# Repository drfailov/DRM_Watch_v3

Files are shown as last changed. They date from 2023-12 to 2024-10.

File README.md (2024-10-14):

<!-- For new line: \ -->
<!-- Picture: <img src="Photos/" width="300"/>  -->
<!-- New Line: "  <br>"  -->

# Про проект DRM Watch 3

<p align="center">
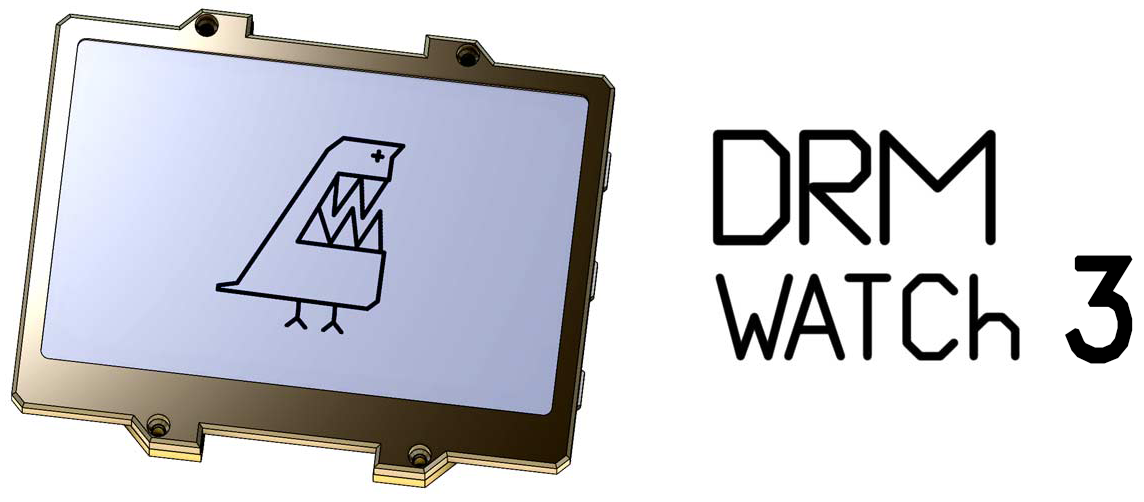
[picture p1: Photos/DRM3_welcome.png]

</p>

**DRM Watch 3** - це мій саморобний наручний годинник, в основі якого лежить дисплей Sharp Memory LCD, ESP32-S2 і бажання носити це на руці:)  <br>
Це **НЕ "Smart годинник"**! Цей пристрій по своїй функціональності близький до звичайного електронного годинника, з кількома додатковими можливостями, і їх можна додавати, перепрограмовувати годинник під себе.  <br>
Наразі в прошивці є всі можливості, що притаманні типовому годиннику і що дозволяє повноцінно використовувати його на щоденній основі.  <br>
В цьому репозиторії можна знайти інфу і інструкції **щоб зібрати собі такий годинник**.  <br>
  <br>
Це у мене таке хобі:) Я в кінці 2023 поліз вивчати проектування плат, після появи 3д принтера в 2022 поліз вивчати 3д моделювання, а за освітою програміст.  От власне це все і зібралось воєдино в цьому проекті) Робив це все з нуля. А яка б класна з цього була дипломна робота)))  <br>
  <br>
Посилання що наведено в цьому тексті є актуальними станом на **2024-04**. Якщо якісь товари будуть вже не актуальні, то шукайте за фотками))  <br>
  <br>
Стаття на Instructables:  <br>
https://www.instructables.com/DIY-ESP32-Wearable-DRM-Watch-3/    <br>
	  <br>

## Фото
<!--p align="center">
<img src="Photos/cad-angle.png" width="200"/>
<img src="Photos/cad-front.png" width="200"/>
<img src="Photos/cad-side.png" width="200"/>
</p-->

<p align="center">
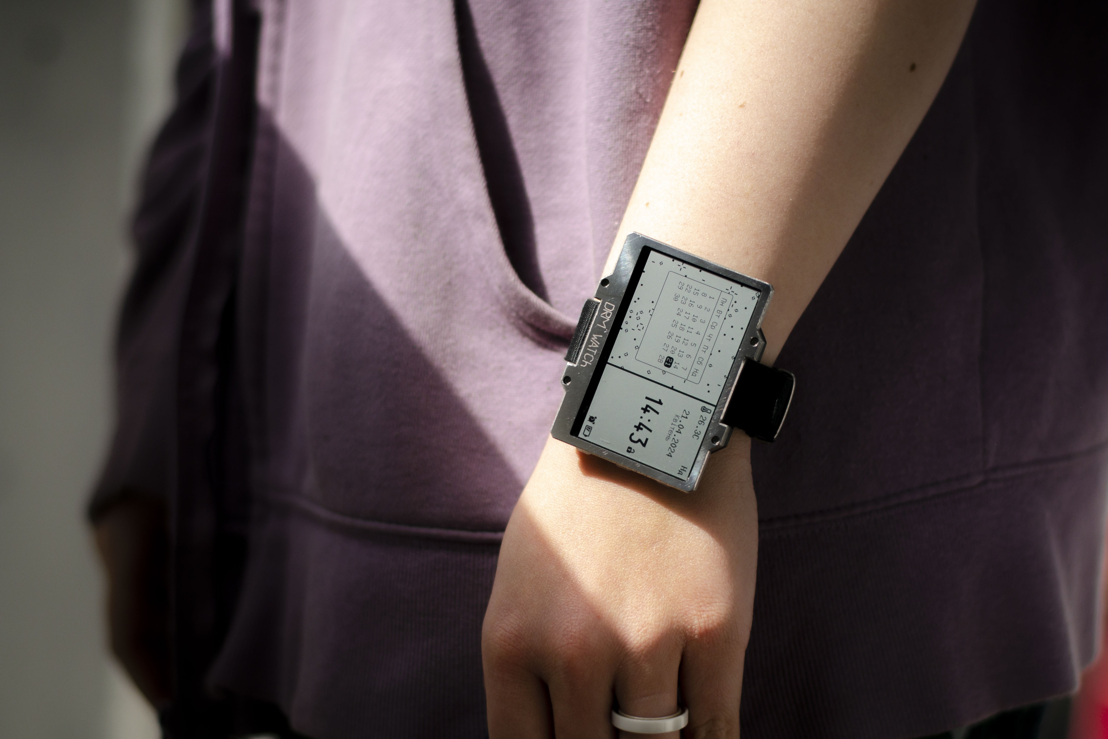
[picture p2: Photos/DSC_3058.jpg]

</p>
<p align="center">
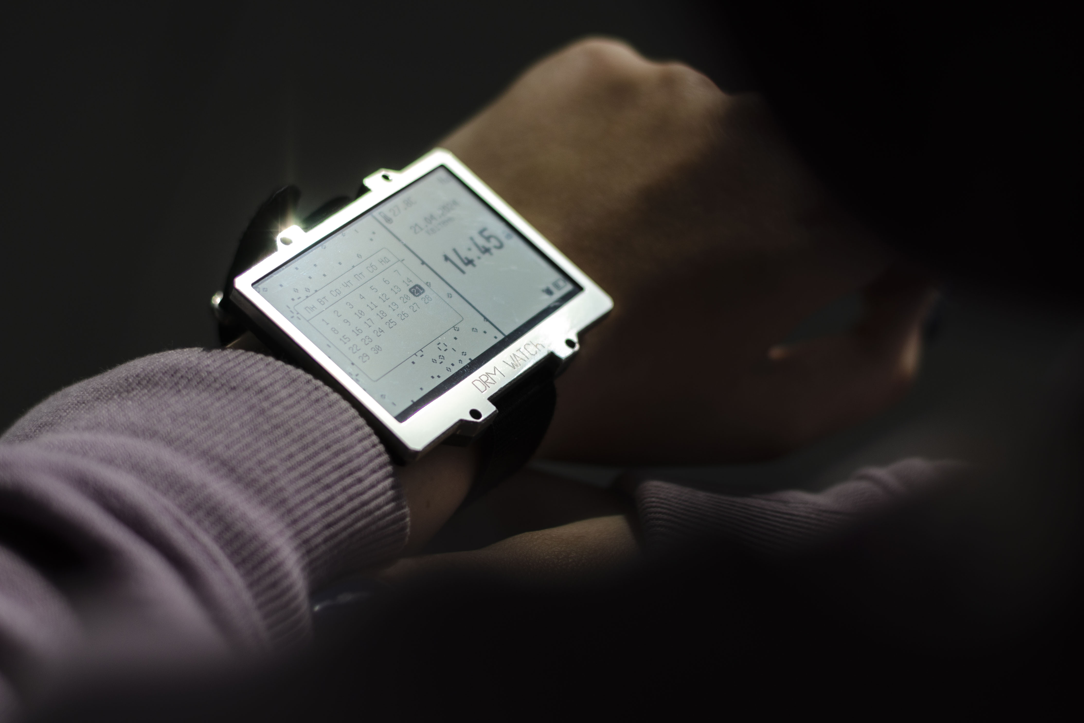
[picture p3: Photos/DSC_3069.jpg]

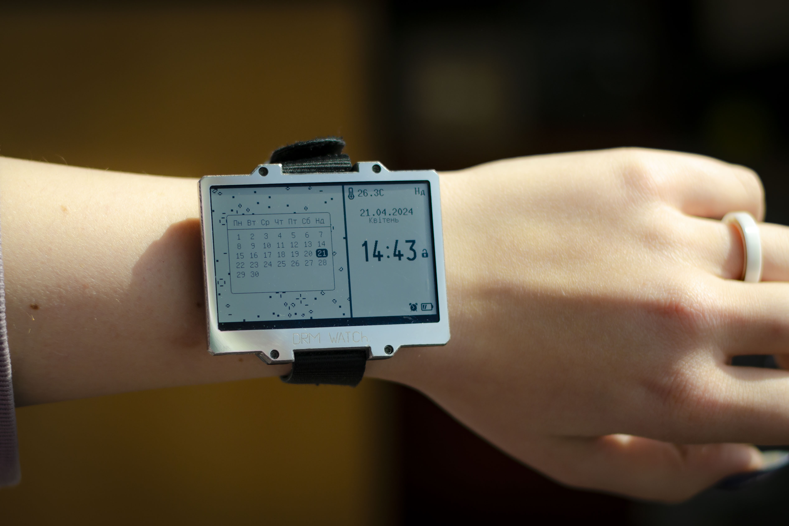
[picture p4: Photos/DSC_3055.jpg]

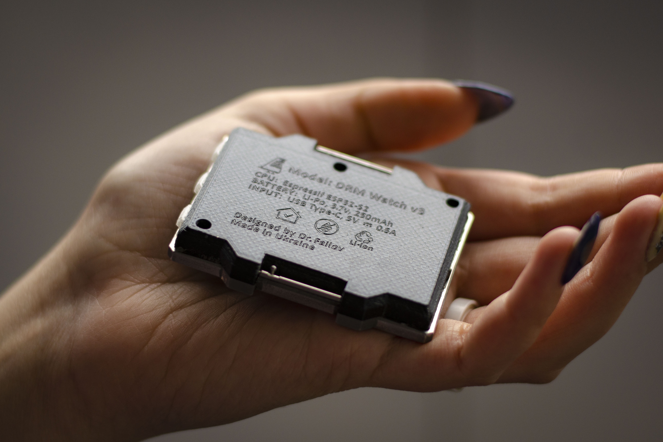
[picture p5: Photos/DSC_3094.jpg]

</p>
<p align="center">
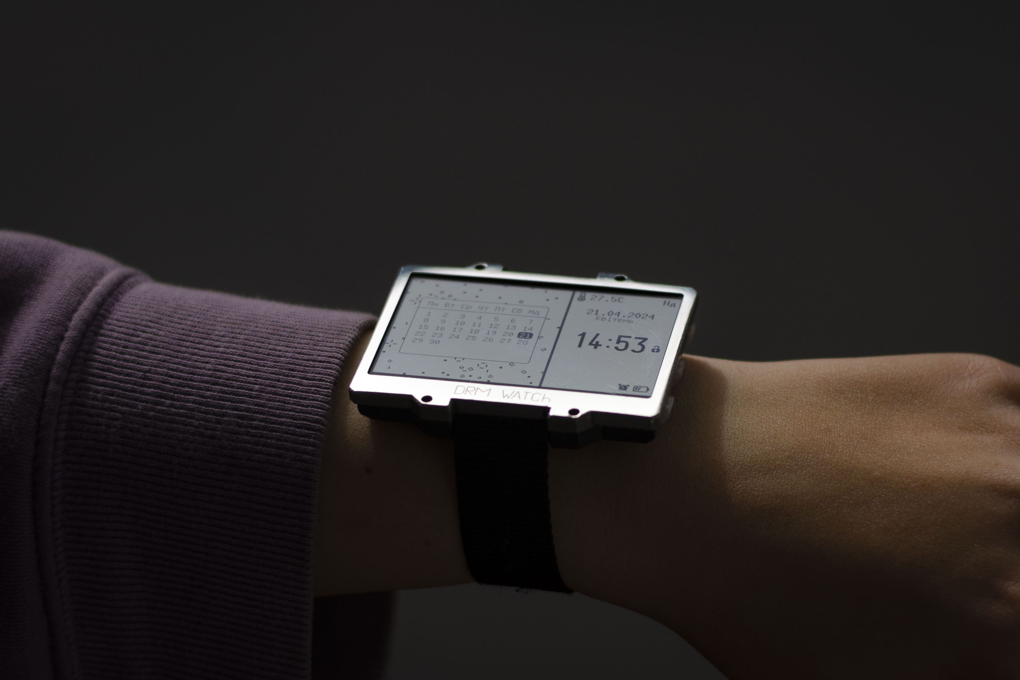
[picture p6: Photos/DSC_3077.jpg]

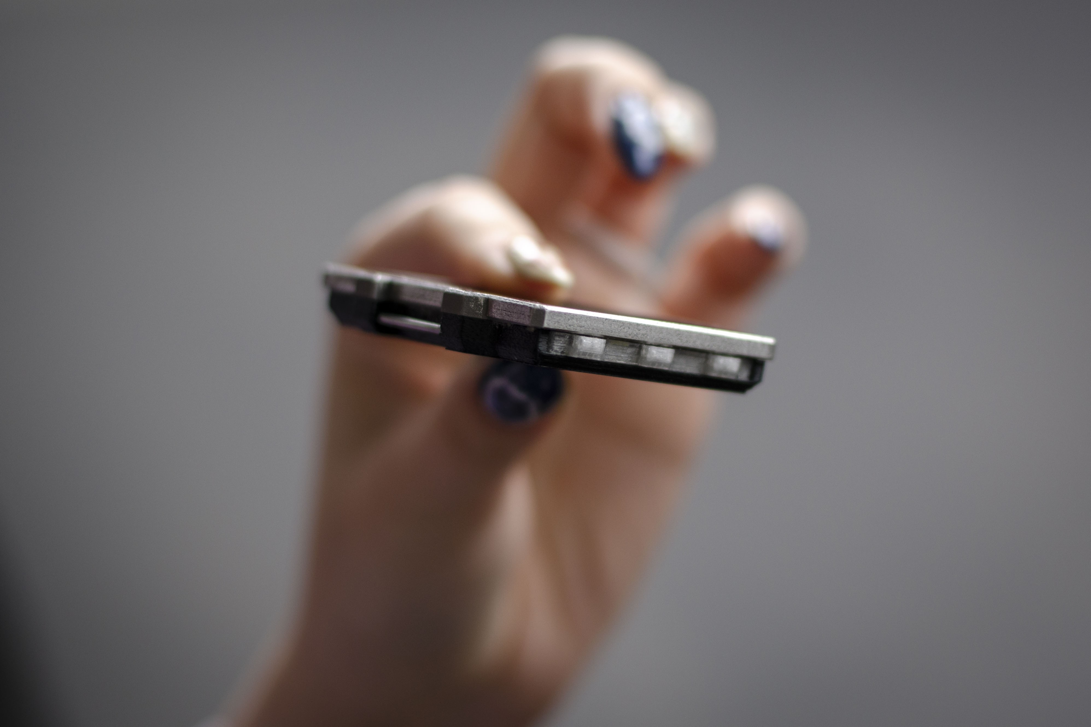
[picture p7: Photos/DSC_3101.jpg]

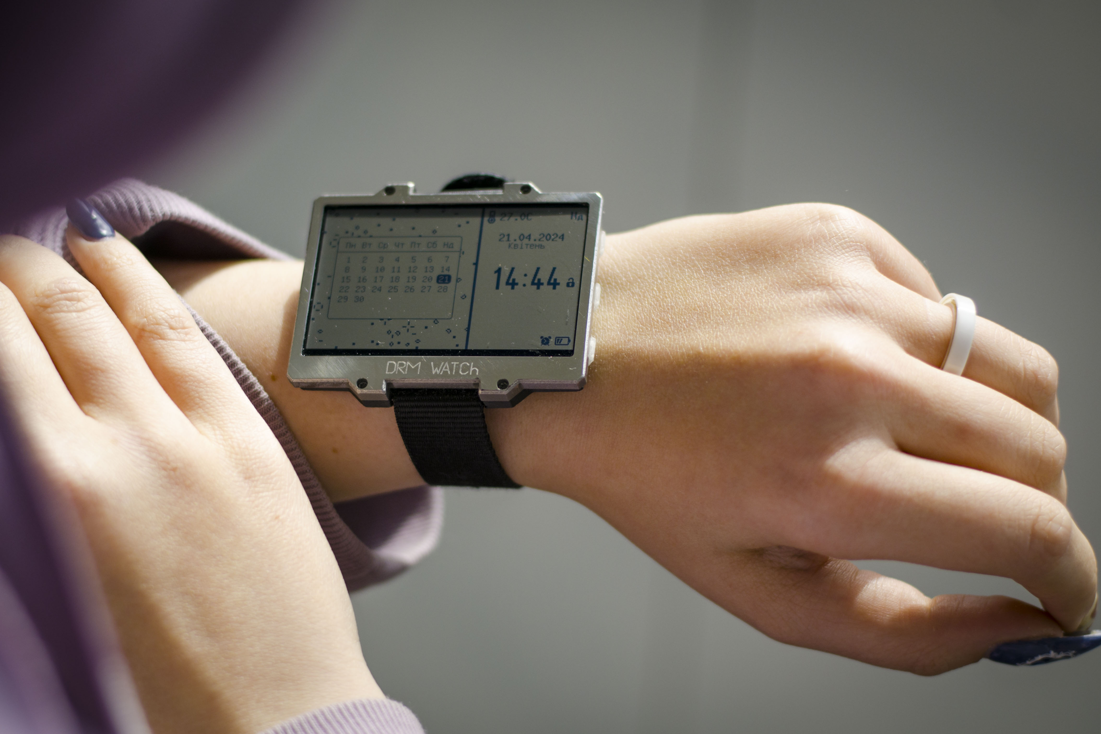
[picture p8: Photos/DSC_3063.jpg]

</p>
<!--p align="center">
<img src="Photos/DSC_3084.jpg" width="200"/>
<img src="Photos/DSC_3097.jpg" width="200"/>
<img src="Photos/DSC_3115.jpg" width="200"/>
</p-->

## Особливості годинника
- Зроблено в Україні;
- Стабільно працює і підходить для щоденного користування;
- Дисплей завжди показує час;
- Інтерфейс двома мовами: Українська та Англійська.
- В годиннику є вбудована "флешка" на 1.2МБ, в яку можна закинути файли
- Годинник може відкрити монохромний BMP, Wav файли, текстовий TXT документи
- Є дуже тускла але дуже приємна нічна підсвітка дисплея;
- Є ліхтарик, білий яскравий та червоний нічний;
- Акумулятора вистачає на понад 14днів, є індикатор заряду;
- Зручні меню, звідки можна отримати доступ до всіх функцій;
- Наявність Wi-Fi, можна зберегти до 8 мереж в пам'яті;
- Можливість синхронізації часу по Wi-Fi;
- Багато мелодій. Їх можна або просто слухати або встановити на будильник.
- Імітація звуку мявчання кошенят;
- Кілька циферблатів, які можна налаштувати;
- На циферблати можна додати календар, стрілочний годинник, дату, та цікавий фон
- Секундомір, працює в фоні;
- Будильники, до 6шт з назвами;
- Вічний календар (або я ще не догортав до кінця);
- Повнекранні клітинні автомати та анімації (Життя, Мураха, Вогонь, Шум, Лава, Мураха, Точки)
- Зарядка по USB, в тому числі від TypeC-TypeC;
- Можна оновлювати прошивку по USB, не розбираючи годинник.
- Компоненти для збірки легко дістати;
- Корпус підходить для стандартних 22мм ремінців;
- Зручно і просто прошивати. Можна написати свою прошивку.
- Якщо під час експериментів з прошивками годинник завис, в корпусі передбачено отвір щоб голкою його перезавантажити.
- Водонепроникність до 0 метрів:) (можна трохи покращити якщо при збірці обробити плату лаком а корпус збирати з клеєм.)
- Годинник можна використовувати як поле для експериментів з ESP32-S2: акумулятор, 3 кнопки, пищалка, дисплей, 3 світлодіоди;
- UART лог: інструмент для розробників, виводить на екран всі байти що надходять по UART.
- Екран "Про годинник" містить інформацію про розробника та версію прошивки.

## Застереження під час користування:
<p align="center">
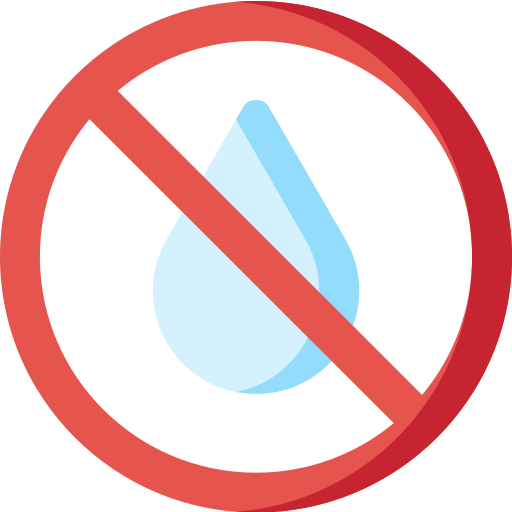
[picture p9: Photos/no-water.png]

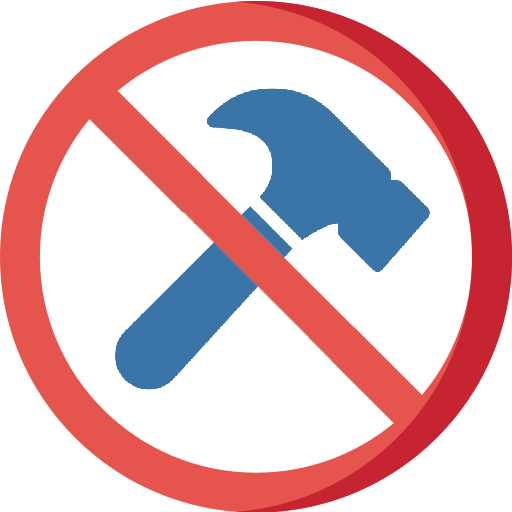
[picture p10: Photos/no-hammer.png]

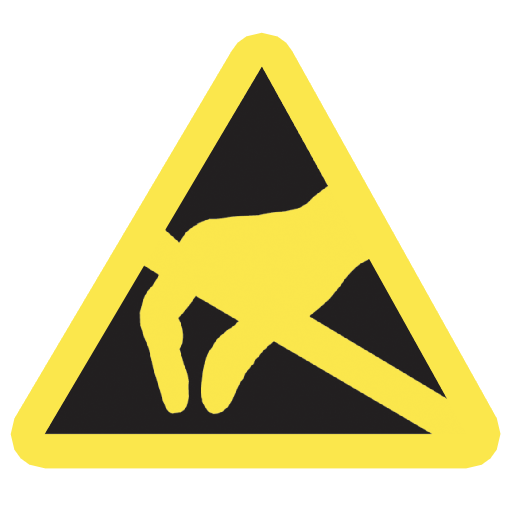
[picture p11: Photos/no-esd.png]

</p>

- Годинник **не можна мочити**. Захист від води тут майже відсутній і це призведе до поломки годинника. Від дрібного дощу або поту йому нічого не буде, а от залити при митті рук - може бути проблемою.
- Годинник **слабко захищений від ударів**. Дисплей не захищений, тонкі рамки, тонкий корпус, годинник спроектований без великого запасу механічної міцності, так він  ще й досить габаритний. Тому вдарити його легко, і це скоріше за все призведе до розбитого дисплея. Протягом моїх місяців експлуатації проблем з пошкодженням годинника не було, але я користувався досить обережно.
- Годинник варто **оберігати від впливу статики**. Є невеликий шанс вбити годинник якщо швидко змімати з себе светр) Тому або знімайте светр повільно, або зніміть перед цим годинник, або використовуйте светр який не електризується. Особливо ризикований момент - постановка на зарядку, тут може проскочити прямо через контроллер. Раджу перед тим як вставити кабель зарядки, доторкнутись до металевої частини корпусу зарядного пристрою - так ви розрядитесь через корпус, а не через годинник і все буде ок.

## Відео огляди годинника:
Тут я зібрав наявні відео годинника.

### Короткий огляд станом на FW v2.03
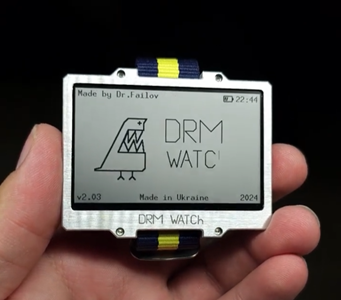
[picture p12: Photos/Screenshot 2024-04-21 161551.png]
Video review (https://www.youtube.com/watch?v=3oIwZVaCEvY)
  <br>
https://www.youtube.com/watch?v=3oIwZVaCEvY

### Повний огляд годинника станом на FW v3.22
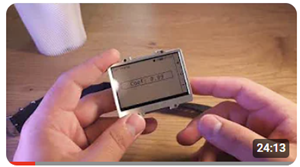
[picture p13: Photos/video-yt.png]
Video review (https://youtu.be/EeJpstsf5wk?si=9BsKVnumjvJCgt0X)
  <br>
https://youtu.be/EeJpstsf5wk?si=9BsKVnumjvJCgt0X

## Короткий відео огляд мелодій станом на FW v2.03
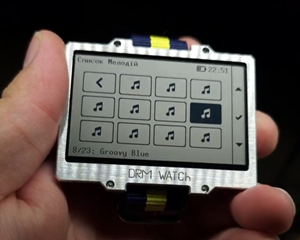
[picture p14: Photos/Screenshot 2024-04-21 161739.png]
Video review (https://www.youtube.com/watch?v=Ylm3CU0DTDE)
  <br>
https://www.youtube.com/watch?v=Ylm3CU0DTDE

### Мій акаунт тікток, де відео багато
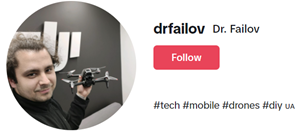
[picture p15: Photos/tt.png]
TT (https://www.tiktok.com/@drfailov)
  <br>
https://www.tiktok.com/@drfailov

# Опис меню, функцій та екранів

## Основний екран, циферблат
<p align="center"> 
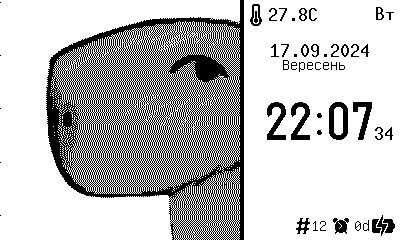
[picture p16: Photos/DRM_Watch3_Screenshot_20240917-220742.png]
       
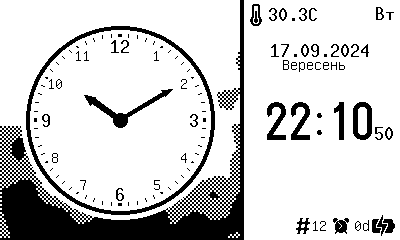
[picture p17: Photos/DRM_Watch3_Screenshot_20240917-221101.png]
       
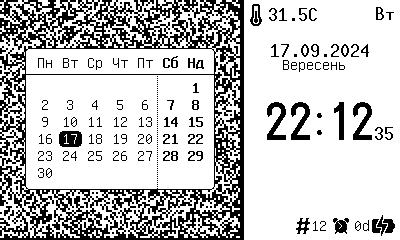
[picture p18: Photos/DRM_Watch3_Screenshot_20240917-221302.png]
       
<img src="Photos/DRM_Watch3_Screenshot_20240917-221522.png" height=200"/>       
<!--img src="Photos/photo_2_2024-06-02_22-49-14.jpg" height=200"/> 
<img src="Photos/photo_51_2024-06-02_22-49-14.jpg" height=200"/> 
<img src="Photos/photo_52_2024-06-02_22-49-14.jpg" height=200"/> 
<img src="Photos/photo_50_2024-06-02_22-49-14.jpg" height=200"/> 
<img src="Photos/photo_46_2024-06-02_22-49-14.jpg" height=200"/> 
<img src="Photos/photo_44_2024-06-02_22-49-14.jpg" height=200"/> 
<img src="Photos/photo_22_2024-06-02_22-49-14.jpg" height=200"/> 
<img src="Photos/photo_17_2024-06-02_22-49-14.jpg" height=200"/-->
</p>

Тут відображаєтья час. Це основний екран годинника, на нього переходят більшість екранів по таймеру бездіяльності. На цьому екрані годинник заходить в сон і спить, просинаючись раз в хвилину щоб намалювати час.     <br>
Вміст циферблату можна налаштувати під себе, тому тут так багато різних його фоток        <br>
**Кнопка вгору** (коротке натиснення) - Відкрити секундомір.      <br>
**Кнопка вгору** (довге натиснення) - Відкрити таймер.      <br>
**Середня кнопка** (коротке натиснення) - Увімкнути ліхтарик.      <br>
**Середня кнопка** (довге натиснення) - вимкнути годинник.      <br>
**Кнопка вниз** - відкрити меню програм.      <br>

## Програми

<p align="center"> 
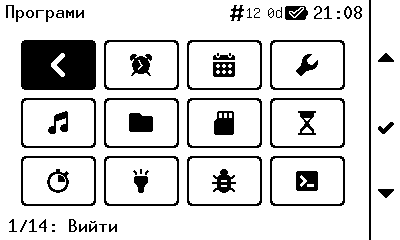
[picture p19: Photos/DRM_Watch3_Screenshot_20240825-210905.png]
 
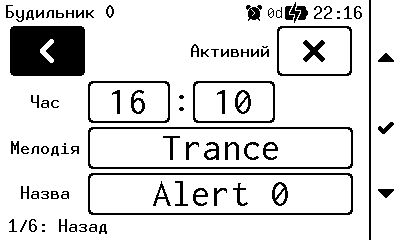
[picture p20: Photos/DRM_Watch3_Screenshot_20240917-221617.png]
 
</p>

Будильник запускає відтворення заданої мелодії в заданий час дня.     <br>
З цього екрану годинник автоматично перейде на основний екран через кілька хвилин бездіяльності.    <br>
Можна налаштувати кілька будильників. До кожного можна задати час, назву та мелодію. Будильник спрацює якщо годинник заряджений і якщо годинник звісно знає поточний час. Спрацює також якщо в момент спрацювання ви знаходитесь в меню а не на циферблаті, а також спрацює якщо годинник вимкнено (але він при цьому заряджений).     <br>
**Кнопками вгору та вниз** - обрати пункт меню.      <br>
**Центральна кнопка** активує обраний пункт меню.      <br>
Коли пункт меню активований, **кнопки вниз та вгору міняють значення пункту**.     <br>
Під час будильника гратиме обрана мелодія і відображатиметься назва будильника та час на який будильник було встановлено. Під час спрацювання будильника його можна закрити (вимкнути на поточний раз), або вікласти на 10 або 5 хвилин (за умови якщо в цей момент не запущено таймер). Після спрацювання будильника він спрацює знову наступного дня. 

## Програми -> Календар

<p align="center"> 
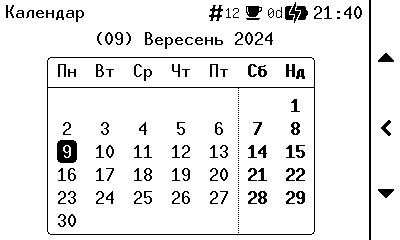
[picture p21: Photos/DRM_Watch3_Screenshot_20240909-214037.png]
 
</p>

## Налаштування -> Дисплей
<p align="center"> 
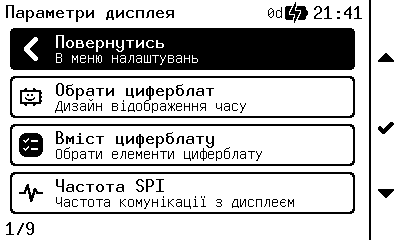
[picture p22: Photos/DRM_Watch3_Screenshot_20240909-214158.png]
 
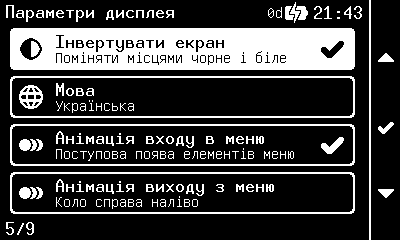
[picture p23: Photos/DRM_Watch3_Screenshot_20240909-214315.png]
 
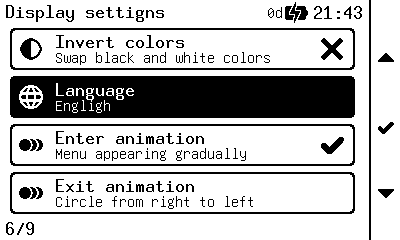
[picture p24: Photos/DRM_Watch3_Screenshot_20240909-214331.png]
 
</p>

Кожен годинник - унікальний, тому кожен показує заряд по своєму.      <br>
Щоб компенсувати цю неточність, я додав алгоритм який це виправляє, але для цього йому потрібно знати свою криву розряду. Щоб провести калібрування:      <br>
- повністю зарядити годинник 
- зняти з зарядки і пройти в налаштування -> дисплей ->калібрування акумулятора
- натиснути там початок калібровки.
- лишити годинник увімкненим на кілька годин поки він не вимкнеться.
Коли годинник вимкнеться, його можна поставити на зарядку і після цього він буде готовий до роботи з новою калібровкою     

## Програми -> Файли
<p align="center"> 
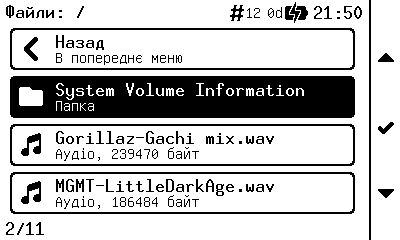
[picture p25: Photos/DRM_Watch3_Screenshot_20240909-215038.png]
 
</p>

Важливо!!! Не зберігайте на годиннику цінну інформацію яка не має копії! У мене кілька разів "ламалась" файлова система і файли втрачались. 
Закономірностей цього явища поки не виявив, але я б не довіряв годиннику нічого цінного!

Формати файлів які може відкрити годинник:
- BMP монохромний. Такі файли можна сформувати з допомогою Microsoft Paint.
- DWM мелодії. Такі файли можна сформувати з допомогою програми в папці `Software\MIDI-to-Arduino-main`.
- WAV PCM 8bit аудіо. Такі файли можна сформувати з допомогою Audacity.
- TXT текстові файли в UTF8 кодуванні. Такі файли можна сформувати з допомогою Notepad++.
<p align="center"> 
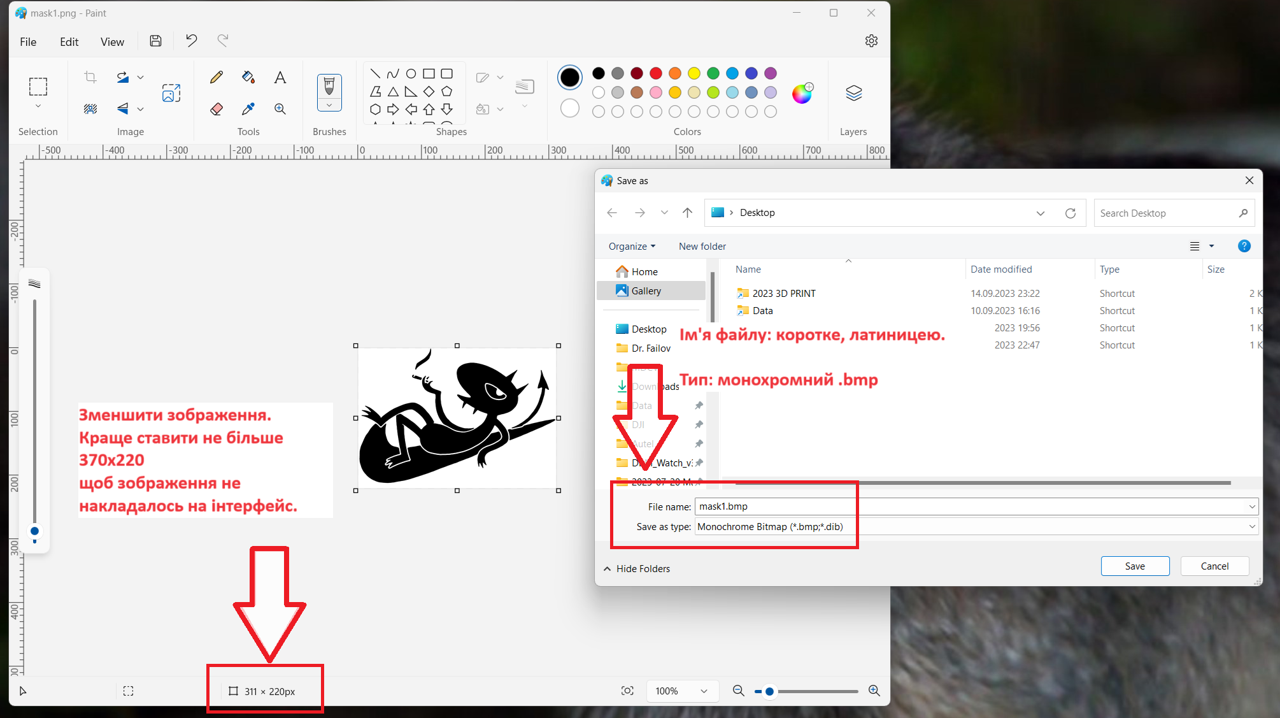
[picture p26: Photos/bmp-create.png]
 
</p>

## Програми -> Менеджер пам'яті
<p align="center"> 
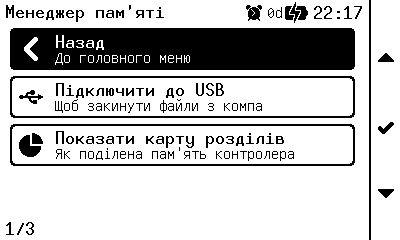
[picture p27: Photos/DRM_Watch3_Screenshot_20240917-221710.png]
 
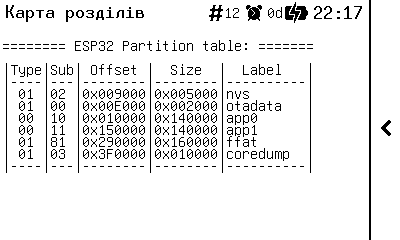
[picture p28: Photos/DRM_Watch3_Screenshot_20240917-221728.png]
 
</p>

Меню зі списком мелодій. Можна переглянути назви та увімкнути мелодію. Їх там багато.     <br>
Я постійно додаю нові мелодії, зокрема з мемів. Додати свої мелодії також можливо, дивіться розділ як зібрати прошивку а потім як додати мелодію.     <br>
З цього екрану годинник автоматично перейде на основний екран через кілька хвилин бездіяльності.    <br>
**Кнопками вгору та вниз** - обрати мелодію.     <br>
**Центральна кнопка** - відкрити і відтворити мелодію.   <br>

## Програми -> Мелодії -> Плеєр
<p align="center"> 
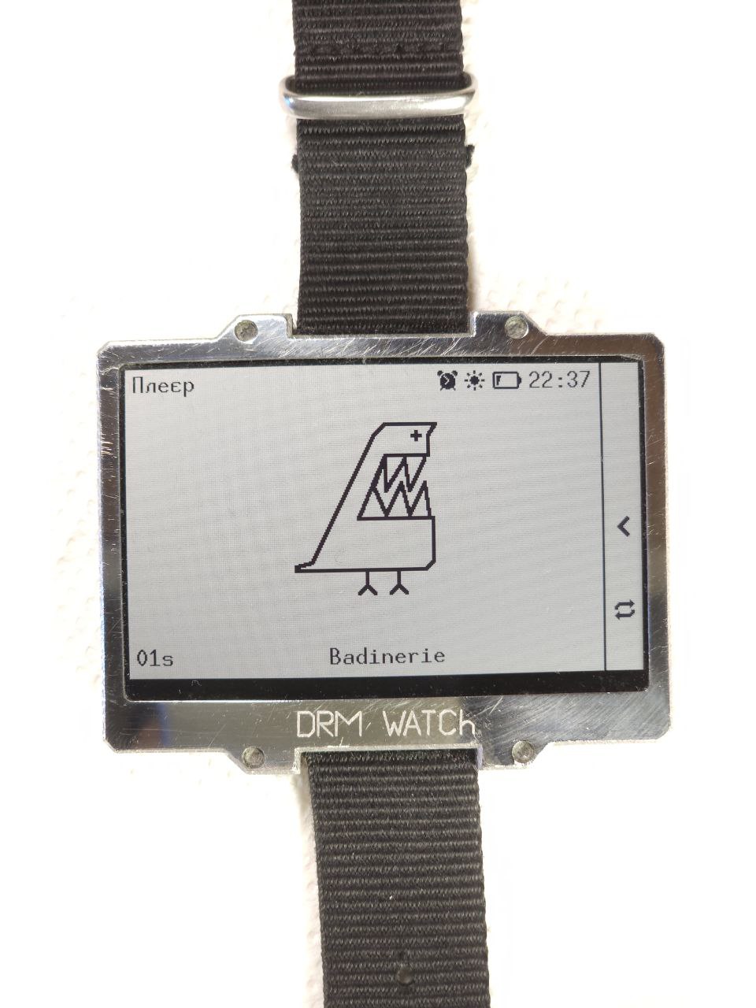
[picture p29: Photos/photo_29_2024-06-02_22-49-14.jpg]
 
</p>

Таймер веде відлік заданого часу від моменту запуску. Коли час спливає, запускається звуковий сигнал.      <br>
З цього екрану годинник автоматично перейде на основний екран через кілька хвилин бездіяльності.    <br>  
**Кнопками вгору та вниз** - задається час на який встановлюється таймер.    <br> 
**Центральна кнопка** - або закриває програму, або запускає таймер.     <br> 
Коли лунає звуковий сигнал, його можна закрити, або вікласти на 10 або 5 хвилин.

## Програми -> Секундомір
<p align="center"> 
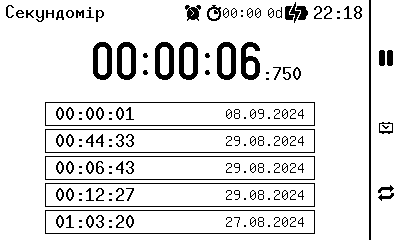
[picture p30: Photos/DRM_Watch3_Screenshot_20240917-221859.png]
 
</p>

Запускає ліхтарик. Програма при цьому ніяка не відкривається, просто вмикається світло.      <br> 
У ліхтарика два режими роботи - червоним світлодіодом і білим.       <br> 
Червоний буде корисним вночі - так він не сліпить і після його використання буде все ще добре видно вночі. 
Денний ліхтарик більш яскравий.      <br> 
Ліхтарик автоматично вимкнеться через кілька хвилин бездіяльності.  <br> 
**Один раз натиснути на кнопку** - якщо ліхтарик вимкнено - увімкнути нічний ліхтарик.      <br> 
**Другий раз натиснути** - увімкнути денний режим.      <br> 
**Якщо ліхтарик вже світить** - більше 5 секунд, то натиснення на кнопку його вимкне.      <br> 
Тобто якщо вночі запустити нічний ліхтарик, покористуватись ним, то натиснення на іконку ліхтарика не запустить денний ліхтар а вимкне ліхтар.      <br> 
Щоб запустити денний ліхтар - кнопку треба натиснути двічі протягом 2 секунд.      <br> 

## Програми -> Інженерне меню
<p align="center"> 
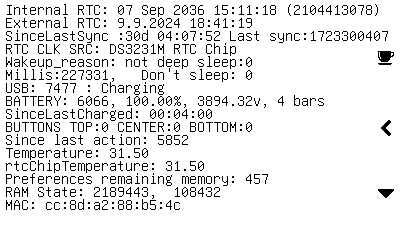
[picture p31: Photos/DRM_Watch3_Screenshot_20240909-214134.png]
 
</p>

На цьому екрані зібрано максимум технічної інформації яка допоможе зрозуміти стан системи.      <br> 
На цьому екрані годинник спить, і не виходить на циферблат.      <br> 
**Центральна кнопка** - вийти до меню програм.      <br> 
**Кнопка вгору** - активувати чи вимкнути режим безсоння     <br>
В режимі безсоння годинник не буде йти в сон по таймеру. 
В цьому режимі годинник дуже швидко розрядиться, за кілька годин. 
В режимі безсоння в статусбарі буде відображатись інонка з кавою, а в інженерному меню буде написано "Don't sleep: 1".     <br>

## Програми -> Лог UART
<p align="center"> 
<img src="Photos/DRM_Watch3_Screenshot_20240909-220405.png" height=200"/> 
</p>

Годинник при підключенні до компа імітує на компі **COM порт**. 
Всі дані що надходять на COM порт - виводяться в лог на екрані.   <br>
Це може бути корисно якщо потрібно зрозуміти яку команду надсилає 
невідома вам програма до підключеного пристрою в процесі, наприклад, діагостики або реверс інжинірінгу.   <br>
Відображення відбувається в форматі лога, можна виводити як в текстовому форматі (ASCII) так і в форматі шістнадцяткових байтів (HEX).  <br>
На цьому екрані годинник не спить і не виходить на циферблат автоматично! Він буде увімкнений доти, доки його не вимкнути вручну або він не розрядиться повністю.  <br>
**Кнопка вгору** - ставить зображення на паузу - якщо потрібно детальніше вивчити отримані дані. Нові дані не будуть виводитись на екран.  <br>
**Центральна кнопка** - вийти до меню програм.  <br>
**Кнопка вниз** - перемкнути режим відображення (ASCII чи HEX).  <br>

## Програми -> Meow
<p align="center"> 
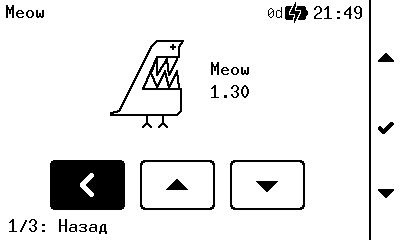
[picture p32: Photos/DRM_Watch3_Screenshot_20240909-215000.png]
 
</p>

Режим повноекранного кліткового автомату "Життя" (Convey's Game Of Life).    <br>
**Будь-яка з кнопок** - повернутись до меню програм.    <br>

## Програми -> Вогонь
<p align="center"> 
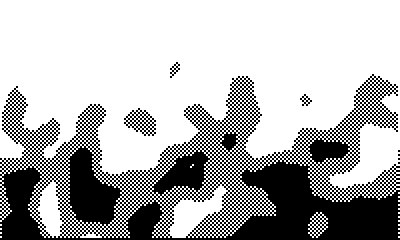
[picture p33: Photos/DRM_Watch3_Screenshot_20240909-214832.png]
 
</p>

Режим повноекранної анімації лави. Красиво. В основі лежить шум Перліна.    <br>
**Будь-яка з кнопок** - повернутись до меню програм.    <br>
Дякую за допомогу з реалізацією Кирилу Лейферу, ось його репозиторій: https://github.com/BOOtak/dct3ngine/blob/master/src/games/perlin_test

## Програми -> Мураха
<p align="center"> 
<img src="Photos/photo_43_2024-06-02_22-49-14.jpg" height=300"/> 
</p>

Режим повноекранного кліткового автомату "Мураха Ленгтона".    <br>
**Кнопки вниз або вгору** - змінити швидкість симуляції.    <br>
**Середня кнопка** - повернутись до меню заставок.    <br>

## Налаштування -> Вміст циферблату
Одночасно відображатиметься тільки один фон, тому щоб був відображався потрібний фон, потрібно залишити активний тільки один з доступних.    <br>
Кнопками вгору та вниз - обрати пункт меню. Центральна кнопка міняє обраний пункт меню. 

# Як зібрати годинник
Готових годинників в продажу не існує, тому якщо є бажання отримати такий годинник, можна зібрати самому.  <br>  

## Що знадобиться
<p align="center">
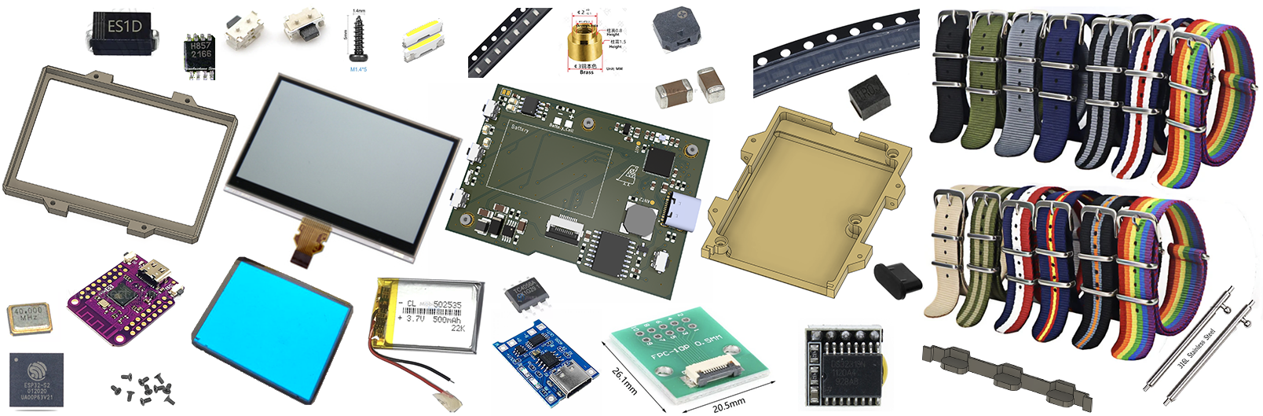
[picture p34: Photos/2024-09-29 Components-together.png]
 
</p>

- Паяльник
- Припой
- Паяльний фен або столик
- Флюс
- Пінцети
- Викрутки
- Мікроскоп (бажано)

## Де брати комплектуючі
<p align="center">
 
</p>

Якщо коротко, то:  <br>  
- Board: Order PCB on jlcpcb, GERBER included  <br>  
- Front panel: order alluminium CNC Milling on jlcpcb, STEP included  <br>  
- Back panel: 3d print, STL included  <br>  
- Display Sharp LS027B7DH01A  <br>  
https://www.aliexpress.us/item/1005005611440829.html  <br>  
- Connector FPC 10pin 0.5mm pitch  <br>  
https://www.aliexpress.us/item/10000348360254.html  <br>  
- Battery lipo 502535  <br>  
https://ampul.eu/de/batterie/4242-li-pol-akku-450mah-37v-502535  <br>  
- Buzzer SMD 7525-3.6V-passive  <br>  
https://www.aliexpress.us/item/1005003620083880.html  <br>  
- Mosfet 2N7002LT1G  <br>  
https://www.aliexpress.us/item/1005003079655220.html  <br>  
- Esp32 board: Lolin S2 Mini  <br>  
https://www.aliexpress.us/item/1005004438665554.html  <br>  
- TP4056 Charging module  <br>  
https://www.aliexpress.com/item/1005006310424899.html  <br>  
- Resistor set SMD 0603  <br>  
https://www.aliexpress.us/item/1005002364437129.html  <br>  
- Capacitors set SMD 0603  <br>  
https://www.aliexpress.us/item/1005006124283234.html  <br>  
- RTC Module based on Analog Devices DS3231   <br>  
https://www.aliexpress.us/item/32822420722.html  <br>  
- 020 SMD Side View LED White 6000K  <br>  
https://www.aliexpress.us/item/32419907074.html  <br>  
- Buttons 2\*4\*3.5mm Micro SMD Tact Switch Side Button  <br>  
https://www.aliexpress.us/item/1005004312046546.html  <br>  
- Screw places SMTSO Surface Mount Copper Nut M1.4X3X1.5-2X0.8  <br>  
https://www.aliexpress.com/item/1005005579653583.html  <br>  
- Screws PH000, M1.4, 3mm length  <br>  
https://www.aliexpress.com/item/1005002364568213.html  <br>  
- Self tapping screws M1.5, 6mm  <br>  
https://www.aliexpress.com/item/1005002324715062.html  <br>  
- Watch band, 22мм   <br>  
https://www.aliexpress.us/item/1005005890436737.html  <br>  
- USB Type C cover:  <br>  
https://www.aliexpress.com/item/4000148621089.html  <br>  
- EL Panel driver: Microchip HV857MG MSOP8  (optional, only if you want backlight)  <br>  
https://www.aliexpress.us/item/1005005512523052.html  <br>  
- EL Driver Capacitor SMD 1206 10NF X7R 200V (optional, only if you want backlight)  <br>  
https://www.aliexpress.us/item/1005004628006766.html  <br>  
- EL Driver Capacitors SMD 1206 320PCS 16Value   (optional, only if you want backlight)  <br>  
https://www.aliexpress.us/item/1005006124283234.html   <br>  
- EL Driver Diode ES1D   (optional, only if you want backlight)  <br>  
https://www.aliexpress.us/item/1005005254835443.html  <br>  
- EL Driver  SMD Inductor 1210 3225 22UH   (optional, only if you want backlight)  <br>  
https://www.aliexpress.us/item/32981310345.html  <br>  
- Glue to connect EL panel MECHANIC MCN-DJ002 Conductive Adhesive Glue Silver (optional, only if you want backlight)  <br>  
https://www.aliexpress.us/item/1005002369819447.html  <br>  

### Дисплей
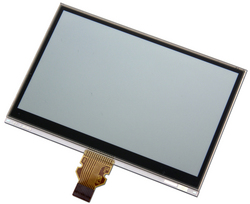
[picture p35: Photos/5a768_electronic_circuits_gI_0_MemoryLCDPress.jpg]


Дисплей потрібен, щоб відображати інформацію користувачу:)  <br>
Модель дисплея: **Sharp LS027B7DH01A**    <br>
Він звісно недешений, але мені дуже подобається як він виглядає. Його можна купити готовим, я купував тут:   <br>
https://www.aliexpress.us/item/1005005611440829.html  <br>

### Конектор дисплея
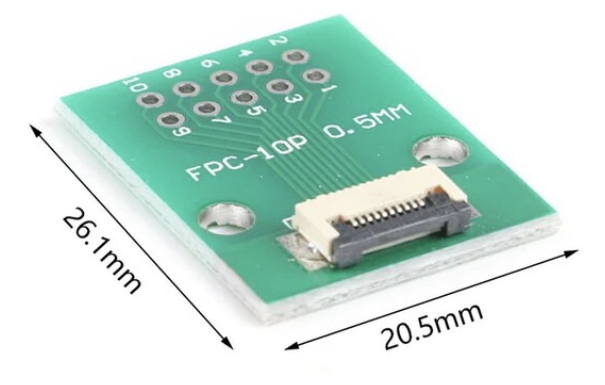
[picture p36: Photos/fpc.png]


Для підключення цього дисплея. Я купував модулем, але можна пошукати і роз'єм окремо.  <br>
Модель: **FPC 10pin 0.5mm pitch** Я купував тут:    <br>
https://www.aliexpress.us/item/1005002288363000.html   <br>
https://www.aliexpress.us/item/10000348360254.html   <br>

### Акумулятор
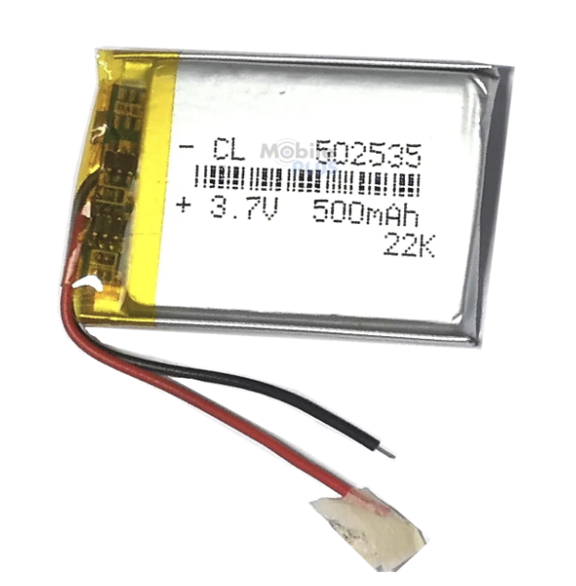
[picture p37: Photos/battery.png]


Якщо потрібно щоб пристрій працював автономно, то потрібен акумулятор.  <br>
Корпус та плата спроектовано під літій-іонний акумулятор такої форми: 35*25*5mm. Звісно, підійде будь-який і меншого розміру, але матиме меншу ємність.  <br>
Модель яка найкраще підходить: **lipo 502535**. Я купував тут:    <br>
https://prom.ua/ua/p1286391849-akkumulyator-kontrollerom-universalnyj.html   <br>
https://ampul.eu/de/batterie/4242-li-pol-akku-450mah-37v-502535   <br>

### Буззер
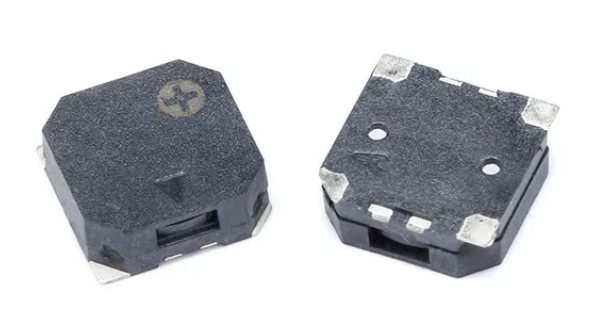
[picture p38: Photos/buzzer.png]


Буззер потрібен щоб пищати, грати мелодії.  <br>
Модель: **Buzzer SMD 7525-3.6V-passive**. Я купував тут:    <br>
https://www.aliexpress.us/item/1005003620083880.html   <br>
https://eu.mouser.com/ProductDetail/CUI-Devices/CMT-7525S-SMT-TR?qs=qCxwlXJ4fnw4ZHFvNib47A%3D%3D

### Мосфет
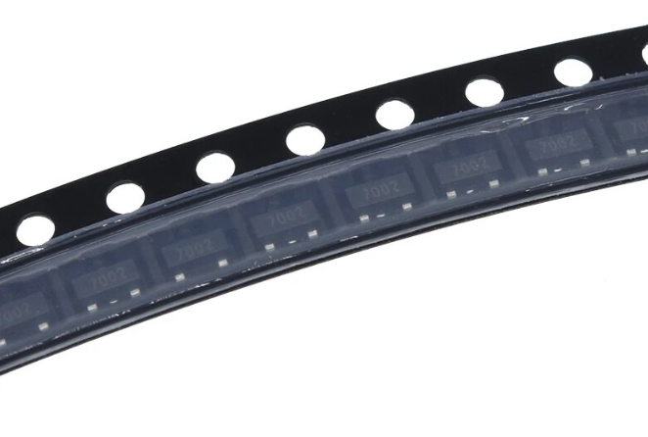
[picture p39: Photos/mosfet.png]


Мосфет використовується для того щоб керувати буззером, щоб на нього надходив не слабкий сигнал з мікроконтроллера, 
а потужний з батареї.    <br>
Модель: **2N7002LT1G**. Можна купити тут:    <br>
https://www.aliexpress.us/item/1005003079655220.html    <br>

### ESP32
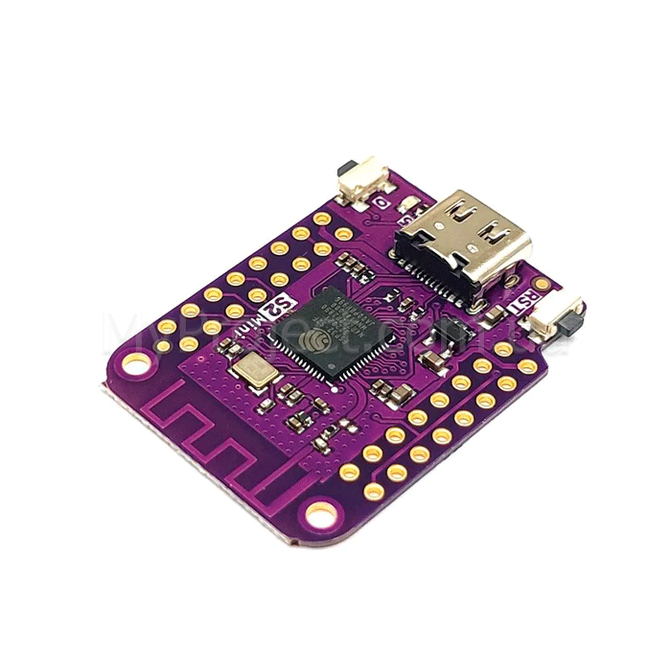
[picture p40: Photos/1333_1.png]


Я розпаював на комплектуючі плати **Lolin S2 Mini**, ось ссилка де я купував:  <br>
https://www.aliexpress.us/item/1005004438665554.html  <br>
  <br>
Якщо немає бажання розпаювати Lolin S2 Mini, можна купити комплектуху окремо:  <br>
<p align="center">
 
</p>

Датащіт:
https://www.espressif.com/sites/default/files/documentation/esp32-s2_datasheet_en.pdf 
Чіп: **ESP32-S2FN4R2, QFN56**  <br>
https://www.tme.eu/ua/details/esp32s2fn4r2/moduli-iot-wifi-bluetooth/espressif/esp32-s2fn4r2   <br>
Кварц: **SMD 3225 4pin 40MHz**:  <br>
https://www.aliexpress.us/item/1005004689346275.html  <br>

### Модуль зарядки акумулятора
<p align="center">
  
</p>

Щоб була можливість заряджати акумулятор. Причому якщо акума не буде - годинник не працюватиме навіть на зарядці.   <br>
https://www.aliexpress.com/item/1005006310424899.html
Тому якщо потрібно обійти модуль зарядки, можна замкнути перемичку біля мікросхеми заряду на платі (вона вона розташована біля самого краю плати) - вона подасть напряму напругу з USB порта замість напруги батареї. Основне не залишити перемичку зі вставленим акумом, щоб не отримати **фаєр-шоу**)))   <br>
Розпаявши такий модуль можна дістати чіп **TP4056** , який відоповідає за зарядку акума. Датащит:  <br>
https://dlnmh9ip6v2uc.cloudfront.net/datasheets/Prototyping/TP4056.pdf  <br>
Якщо нема бажання розпаювати модуль, можна знайти окремо:  <br>
<p align="center">
 
<img src="Photos/led.png" height=50"/> 
</p>

Чіп: **TP4056**  <br>
https://www.alibaba.com/product-detail/TC4056A-SOP-8-is-compatible-with_1600806443781.html  <br>
Роз'єм: **TYPE-C-31-M-12**  <br>
https://jlcpcb.com/partdetail/Korean_HropartsElec-TYPE_C_31_M12/C165948  <br>
Світлодіод: **0805 SMD LED**  <br>
https://www.aliexpress.us/item/4000936781234.html  <br>

### SMD Резистори


Я робив плату під резистори **SMD 0603** (переважно), їх я брав з такого набору:   <br>
https://www.aliexpress.us/item/1005002364437129.html   <br>

### SMD Конденсатори


Я робив плату під конденсатори **SMD 0603** (переважно), їх я брав з такого набору:   <br>
https://www.aliexpress.us/item/1005006124283234.html   <br>

### RTC модуль
<p align="center">
   
  
</p>

Використовується мікросхема **Analog Devices DS3231**, я її купував в складі такого модуля:   <br>
https://www.aliexpress.us/item/32822420722.html   <br>
Але можна також знайти мікросхеми окремо. Ось ще трохи інфи по ним:   <br>
https://octopart.com/ds3231-maxim+integrated-14739425
https://www.analog.com/en/products/ds3231.html   <br>
https://www.analog.com/media/en/technical-documentation/data-sheets/DS3231.pdf   <br>

### Світлодіод ліхтарика
<p align="center">
  
  
</p>

Ці світлодіоди я діставав виключно з підсвітки старих телефонів, бо їх дисплеїв у мене багато.   <br>
Але я знайшов їх типорозмір щоб можна було замовити окремо: **020 SMD Side View LED White 6000K**.   <br>
Знайшов що тут можна замовити:  <br>
https://www.aliexpress.us/item/32419907074.html   <br>

### Кнопки


Я так і не знайшов як їх можна назвати, тому шукаємо по фото і цьому тексту: **2\*4\*3.5mm Micro SMD Tact Switch Side Button**  <br>
https://www.aliexpress.us/item/32880903601.html    <br>

### Місця для гвинтів


Такі можна знайти на материнці DJI Mavic 3. Під гвинт М1.4  <br>
Орієнтовна назва: **SMTSO Surface Mount Copper Nut M1.4X3X1.5-2X0.8**  <br>
Щось схоже:  <br>
Обирати: M1.4X3X1.5-2X0.8 <br>
https://www.aliexpress.com/item/1005005579653583.html

### Гвинти для задньої кришки


Я їх брав з материнки мавіка 3.  <br>
Тип: PH000, M1.4, 3mm  <br>  <br>
Приклад де замовити:  <br>
Обрати Size: M1.4 X 50pcs   Length: 3mm  <br>
https://www.aliexpress.com/item/1005002364568213.html  <br>

### Гвинти для передньої кришки


Я їх брав з Nokia 1280, вона скручена на такі.  <br>
Тип: T5, 1.5mm по пластику   <br>

Схожі можна замовити тут:  <br>
В складі набору є гвинти 1.4мм, вони мають підійти.  <br>
https://www.aliexpress.com/item/1005002324715062.html  <br>

### Електролюмінесцентна панель


Цей елемент можна ставити або не ставити за бажанням, залежно від того чи потрібна вам нічна підсвітна екрана.   <br>
Електролюмінесцентна панель (EL панель) є складовою частиною системи підсвітки. Це панель, що світиться під впливом високої напруги і частоти. Також їх називають світлоконденсаторами (LEC). Це просто цікаві факти щоб краще розуміти що воно таке.  <br>
Фішка цього типу підсвітки в тому, що панель є дуже тонка, світить дуже рівномірно приємним синім кольором, а також її можна нарізати на фрагменти потрібної форми. Але після порізки складною є задача підключення до панелі. Я для підключення використовував одиночні жили дроти а також токопровідний клей.  <br>
Мінуси: будучи розташована за дисплеєм який тут використовується, її ледь-ледь видно, але вночі цього достатньо. Також трохи пищить при роботі. А ще для її роботи потрібна досить складна схема драйвера.  <br>
Раджу купувати синій колір, тому що EL панель натівно такого кольору, а в інші кольори її тупо фарбують, а фарба поглинає частину світла. Якщо прийшла пофарбована панель, її можна очистити від фарби лезом.  <br>
Ось де я купував:  <br>
https://www.aliexpress.us/item/1005003971896012.html  <br>

### Драйвер електролюмінесцентної панелі


Цей елемент можна ставити або не ставити за бажанням, залежно від того чи потрібна вам нічна підсвітна екрана.   <br>
Це та мікросхема, яка і формує змінну високу напругу для електролюмінесцентної панелі.   <br>
Схему її підключення я не розумію, просто зібрав по схемі і воно запрацювало))   <br>
Модель: **Microchip HV857MG MSOP8**   <br>
Датащит:   <br>
https://ww1.microchip.com/downloads/aemDocuments/documents/APID/ProductDocuments/DataSheets/HV857-High-Voltage-Low-Noise-EL-Lamp-Driver-IC-Data-Sheet-DS20005683.pdf   <br>
Я купував тут:  <br>
https://www.aliexpress.us/item/1005005512523052.html  <br>

### Обвязка драйвера електролюмінесцентної панелі
<p align="center">
 
 
</p>

Цей елемент можна ставити або не ставити за бажанням, залежно від того чи потрібна вам нічна підсвітка екрана.   <br>
Насправді я в цій мелочовці взагалі не шарю, причому навіть деякі елементи замовив не ті що треба було... Але у мене воно запрацювало. Тому я кладу тут ссилки на те що я конкретно замовляв.   <br>

Модель: **Capacitor SMD 1206 10NF X7R 200V**   <br>
https://www.aliexpress.us/item/1005004628006766.html   <br>

Модель: **1206 320PCS 16Value**   <br>
https://www.aliexpress.us/item/1005006124283234.html   <br>

Модель: **Diode ES1D**   <br>
https://www.aliexpress.us/item/1005005254835443.html   <br>

Модель: **SMD Inductor 1210 3225 22UH**   <br>
https://www.aliexpress.us/item/32981310345.html   <br>

### Клей для електролюмінесцентної панелі


Цей елемент можна ставити або не ставити за бажанням, залежно від того чи потрібна вам нічна підсвітка екрана.   <br>
Цей клей я використовую для того щоб під'єднати дроти до електролюмінесцентної панелі. Детальніше про процес можна почитати в розділі "процес збірки".   <br>
Модель: **MECHANIC MCN-DJ002 Conductive Adhesive Glue Silver**   <br>
https://www.aliexpress.us/item/1005002369819447.html   <br>

### Ремінець
<p align="center">
  

 
</p>

Можна купити на алі, вибір великий. Потрібні стандартні ремінці **шириною 22мм**.   <br>
До прикладу, можна замовити тут:   <br>
https://www.aliexpress.us/item/1005005890436737.html   <br>

До ремінців як правило йдуть в комплекті і піни для встановлення, але якщо його в комплекті нема, можна замовити окремо:   <br>
https://www.aliexpress.us/item/1005006026719458.html   <br>

### Заглушка роз'єма USB


Оскільки годинник використовується в умовах високої вологи та поту, нагальною є проблема 
окислення роз'єма USB, що з часом призводить до того що роз'єм працює нестабільно, а годинник 
стає все складніше заряджати або прошивати.   <br>
Використання подібних заглушок вирішує дану проблему.  <br>
Лишається тільки не загубити її:)  <br>
<br>
Я їх купував тут:  <br>
https://www.aliexpress.com/item/4000148621089.html

## Корпус
<p align="center">
  


</p>

Корпус спроектовано для простоти збірки та простоти друку на FDM 3D принтері. При цьому можна також замовити друк металом або фрезерування.  <br>
Малював корпус в Fusion 360, якщо потрібно щось змінювати, відкривайте файли `.f3d`. В папці купа версій, шукайте версію з новішою датою в назві.  <br>
Корпус спроектовано під **ремінці 22мм**.  <br>
Корпусні частини краще друкувати з чорного платику, а вкладку з кнопками - прозорим пластиком, щоб через нього світили ліхтарики.  <br>
В папці багато файлі і моделей, обираючи найновіший дивіться на номер версії або дату в назві файлу.  <br>
Для замовлення фрезерування та лазерного маркування вам знадобиться файл `.step` та `.dwg`.  <br>
Для друку металом або звичайним 3д принтером знадобиться `.stl` файл. (по одному на кожну частину корпусу)

### Замовлення фрезерування
<p align="center">
  
  

</p>
Передню частину корпусу рекомендую фрезерувати з алюмінію. 
Замовити можна на JLCPCB, для замовлення знадобиться `.step` файл. 
Також можна додати гравіювання, для цього знадобиться `.dxf` файл.
Параметри можна побачити на скріншоті з замовлення.

## Плата
<p align="center">
  
</p>
<p align="center">
  
  
  
  
  
</p>

Корпус спроектований під плату товщиною **0.8mm**. Колір плати можна обирати на свій смак, я обирав чорні.  <br>
В папці можна знайти плати різних ревізій, коротко про ревізії:  <br>
**Rev 1:** конденсатори розміщені надто далеко від контроллера, конденсаторів мало, 
немає елементів що формують EN для контроллера, нема RTC мікросхеми, антена на платі неефективна, 
розпіновка в деяких моментах відрізняється від нової ревізії, елементи розміщені не плотно, немає ніякої підсвітки.  <br>
**Rev 2:** вісутні підтяжки RTC SCL та SDA. Елементи розміщені не плотно, підсвітна світлодіодна і неефективна.  <br>
**Rev 3:** Помилок по схемі наче поки немає, я зібрав і воно одразу запрацювало. 
Підсвітка електролюмінесцентна з драйвером. Компоненти розміщені плотно. Можна поставити великий акум на 500мАг.  <br>
**Rev 4:** Додано піни щоб підключити до RTC окремий акум щоб не збивався час при розрядці акумулятора, 
додано елементи які відповідають за роботу вібро. Поки програмно він ніяк не задіяний, але хай буде.  <br>  
**Rev 5:** Оновлено BOM виправлено потенційні неоднозначності  <br>  

### Генерування BOM з проекту KiCad
- Відкрити проект KiCad, Перейти до редактора схеми.
- Натиснути `Genetate Bill Of Materials`
- Зі списку обрати `bom_csv_grouped_by_value_with_fp`
- Згенерований файл лежатиме тут: `Board\KiCad Project\_DRM_Watch_v3\DRM_Watch_V3.csv`, але він напряму екселем не читається.
- Створюємо нову таблицю в екселі.
- Йдемо до `Дані - Отримати з текстового/CSV файлу`, обираємо створений файл. Обираємо параметри з якими відображатиметься коректно.
- Готово. Зберігаємо таблицю в файл - цей BOM вже можна нормально переглядати.

Якщо формат "Стандартного" генератора BOM не подобається, то можна замінити скрипт. Я вже його трохи підправив.
Ідемо до папки `C:\Program Files\KiCad\7.0\bin\scripting\plugins` (у вас може бути в іншому місці, пошукайте), 
і заміняємо файл `bom_csv_grouped_by_value_with_fp.py` на файл з моєї папки `Board\KiCad Project\_DRM_Watch_v3\bom_csv_grouped_by_value_with_fp.py`. 
Після заміни створюєм BOM повторно. 
Якщо і цей формат не сподобається, тоді правце цей файл під себе.

### Замовлення плати
<p align="center">
 
 
</p>
Щоб замовити собі плату, можна скористатись файлами в папках GERBER. Знаходяться вони тут: `Board\Gerber OUTPUTs`  <br>
Ці файли достатньо завантажити на сайт де виготовляють плати, я замовляв у **jlcpcb.com**. 
Там одразу має бути видно як виглядатиме плата.   <br>
Якщо потрібно щось поміняти - ставимо KiKad, відкриваєм проект `Board\KiCad Project\_DRM_Watch_v3\DRM_Watch_V3.kicad_pro` і можна міняти.   <br>
Експортувати Gerber на Drl можна в редакторі плат KiKad.  <br>
Також в схемі в проекті я до кожного елемента пододавав інфу про те де його можна замовити (якщо знаю звісно)  <br>

### Пайка елементів на плату
<p align="center">
  
</p>

В проекті KiKad є більше інфи що і куди паяти, що з чим з'єднано. Якщо немає бажання відкривати проект, то я вивів потрібну інфу в файл `Doc\2024-09-29 Board Soldering Plan.pdf`

### Замовлення зібраної плати
Деякі виробники плат в Китаї пропонують замовлення плат вже готовими і зібраними (PCBA = PCB Assemply). Як правило процес замовлення не надто автоматизований, а робота таких виробників покладається на роботу менеджерів. Тому такі замовлення вони часто приймають у форматі особистої переписки в месенджерах.  <br>
Для такого замовлення їм треба наступна інформація:
- Gerberи плати. Це формується з редактора плат KiKad в файли `.gbr` і містить інформацію про саму плату (всі її шари). Один файл `.gbr` це один шар плати. Можна взяти в папці `Board/2024-04-18 GERBER REV4` (або новішу).
- Список елемнетів які розміщено на платі, тобто файл BOM. Він формується зі схеми в KiKad в файл `.csv` і містить інформацію про номер елемента на платі, виробника, назву компонента, посилання де його можна замовити, та опис кожного елемента. Можна взяти в папці `Board/2024-04-18 GERBER REV4` (або новішу).
- Інформацію про розміщення елементів на поверхні плати. В моєму випадку це окремий шар на Gerber плати, а саме `DRM_Watch_V3-F_Fab.gbr`. Там я розписав розміщення елементів, причому я робив це для себе в довільному по суті форматі, але цей файл підійшов для замовлення.
- Інформація про тип плати, в моєму випадку це товщина **0.8mm** та колір чорний.

# Процес збірки та налагодження

## Підготовка електролюмінесцентної панелі
<p align="center">
 
 
</p>

Оскільки щоб встановити електролюмінесцентну панель, її потрібно **порізати**, то з'являється проблема її підключення, 
адже контакти панелі відріжуться. Окрім того все підключення слід виконати **дуже компактно**, оскільки місця під дисплеєм мало.   <br>
У тих панелей що я замовляв, на зворотній стороні можна було бачити, що два контакти які живлять панель **проходять по вьому її периметру**. В них і будем підключатись. Щоб все працювало треба один дріт підключити до зовнішнього електрода, а другий до центрального.   <br>
Підключатись будемо одною **тонкою жилою багатожильного дроту**. Вона звісно дуже тендітна, але в зібраному годиннику це не проблема.   <br>
Я робив так: 
- беремо гостре (свіже, незатуплене) лезо, і під мікроскопом **розрізаємо ламінацію панелі**. Діяти треба обережно, щоб не пошкодити 
нічого зайвого.   <br>
- Далі в цей розріз обережно **запихуємо кінець жили дроту**, пінцетом або лезом. Бажано щоб всередину помістилось хоча б 4мм дроту.   <br>
- Далі набираємо на зубочистку провідний клей, зовсім трішки, і **набиваємо провідний клей всередину** вслід за дротом. Далі чекаємо поки клей засохне.   <br>
- Процес засихання клею можна прискорити прогрівши місце поклейки до температути приблизно **100 градусів на хвилин 20**. Я робив це на паяльному столику.   <br>
- Після поклейки вигинаємо жили дроту так щоб вони виходили до контактів `EL1` та `EL2` на платі, і всю цю поклейку і **жили фіксуємо скотчем.**    <br>
<br>

На цьому етапі ми маємо панель з двома надтонкими жилами які виходять з неї. Можна паятись до плати і має працювати.   <br>
Якщо не працює - варіанти звісно два, або платою не генерується напруга або щось не так з панеллю.    <br>
Плату перевірити легко - звичайним мульмиметром в режимі **вимірювання змінної напруги** поміряти між `EL1` та `EL2`. Має бути приблизно 90 вольт змінного струму.   <br> Якщо напруга є - проблема в панелі.

## Інструменти та розхідники


На етапі налагодження може допомогти такий **QFN56 Breakout Board** який підійде для ESP32-S2 (нагадую, там корпус QFN56)  <br>
https://www.aliexpress.us/item/1005002805132028.html  <br>

<p align="center"><img src="Photos/urethan.png" height=180"/> </p>

**Uretan 71**  <br>
Для покриття плат лаком я використовував таку штуку як **Uretan 71**. Наносив за допомогою маленького пензля в два шари.   <br>

## Інструменти, які я використовував при проектуванні:
- Проектування плати та схеми: **KiCad 7.0.9**;
- Формування BOM: **bom_csv_grouped_by_value_with_fp.py** (розташований в папці `Board`);
- Написання прошивки: **VSCode** (проект в папці `Firmware`);
- Розширення плати: **PlatformIO + Espressif32** (В списку плат оберіть "Lolin S2 Mini");
- Конвертування іконок: **Програма LCD Assistant**. (Виберіть Horizontal).
- Написання флешера: **Visual Studio + C# + WindowsForms + .NET Framework 4.6**.

# Прошивка
Прошивка написана на C++ в **VSCode 1.89.1** з використанням розширення **PlatformIO**, компілювати треба під плату **Lolin S2 Mini**.   <br>
Як не складно помітити, прошивка містить багато робочих екранів (я їх назвав режимами або Mode). Кожен з них - це окремий набір функцій Setup, Loop, Exit, OnButton..., тощо.   <br>
Перехід між режимами (екранами) здійснюється викликом функції `SetupMode...()` для відповідного режиму (екрану) який треба запустити. Ця функція має замінити адреси виконавчих функцій на свої.   <br>
Кожен режим в прошивці (поточний екран, mode) - це комплект функцій які займаються відмальовуванням екрану та обробкою кнопок. Кожен режим може робити по суті що завгодно.   <br>
Основний спосіб навігації в прошивці це змінні типу `Runnable`:  `modeSetup, modeLoop, modeButtonUp, modeButtonCenter, modeButtonDown, modeButtonUpLong, modeButtonCenterLong, modeButtonDownLong`.    <br>
Ці змінні знаходяться в файлі Global і доступні з усієї програми. В кожен момент часу містять посилання на функції які відповідають поточному режиму (екрану). Саме ці змінні викликає кореневий Loop.   <br>
Коли потрібно перемкнути режим (поточний екран), функція `modeSetup` відновідного режиму має перезаписати ці посилання, 
і відновідно `loop` викликатиметься вже інший, малюватиметься інша інфа, користувач бачитиме інший екран та взаємодіятиме з ним.   <br>
   <br>
 
- **enableAutoReturn** - чи з цього режиму годинник виходитиме автоматично якщо його залишити. Ця логіка реалізована в коненевому Loop.	
- **enableAutoSleep** - Чи в цьому режимі годинник буде спати не виходячи з нього. Важливо пам'ятати що сон стирає всю оперативку. Ця логіка реалізована в коненевому Loop.

**modeSetup** - поточного режиму функція входу. Вона має:
- Виконати modeExit якщо вона не нульова (щоб завершити попередній режим)
- Відтворити анімацію виходу з попереднього меню: clearScreenAnimation()
- Задати змінні для даного режиму: modeSetup, modeLoop, modeExit. Якщо щось з цього нема, ТРЕБА задати 0.
- Задати дії кнопок доя даного режиму: modeButtonUp, modeButtonCenter, modeButtonDown, modeButtonUpLong, modeButtonCenterLong, modeButtonDownLong.  Якщо щось з цього нема, ТРЕБА задати 0.
- Викликати registerAction();
- Задати правила цього режиму: enableAutoReturn, enableAutoSleep, autoReturnTime, autoSleepTime.
  <br>
**modeLoop** - поточного режима Loop функція. 
- Намалювати екран
- Обробити дані
- кнопки обробляти тут не треба оскільки вони обробляються окремо і будуть викликані відповідні функції.
  <br>
**ModeExit** - функція призначена для завершення "роботи" що робилась в поточному режимі.
- Можна почистити пам'ять
- Позакривати файли якщо відкриті
- вимкнути вайфай, діоди, чи що ще використовувалось
- при виконанні завжди в ній треба додавати modeExit = 0; щоб не було повторного запуску 

## Структура роботи батареї
В процесі виявлення рівня заряду застосовується
- Усереднене значення кількох замірів
- Виявлення аномалій в значеннях та відсікання аномальних
- Таблиця калібровки для розрахунку відсотка
- Гістерезис для ігнорування дрібних змін відсотка
- Дабл-чек якщо є підозра на 

Послідовність руху даних:
- `analogRead()`   <br>
Беремо сире зашумлене значення з ADC.   <br>
**Діапазон:** [0...8096], **Шумів** - ДУЖЕ багато.

- `analogSmoothRead()`    <br>
Згладжуємо середнім - протитавши кілька разів поспіль.   <br>
**Діапазон:** [0...8096], **Шумів** - багато.

- `readSensBatteryRaw()`   <br>
Функція для спрощення виклику по програмі.   <br>
**Діапазон:** [0...8096], **Шумів** - багато.
  
- `readSensBatteryRawFiltered()`   <br>
Рахуємо середнє, девіацію кожного значення відносно середнього, середнє девіації та ліміт девіації.   <br>
Всі значення девіація яких виходить за межі ліміту, відсікаємо (заміняємо середнім).   <br>
А далі фільтроване значення усереднюєм.   <br>
**Діапазон:** [0...8096], **Шумів** - нормальна кількість.

- `batteryCalibrationGetValuePercent(raw)`   <br>
На основі отриманого Raw рахуємо відсоток заряду на основі таблиці калібровки яка   <br>
була сформована під час повної калібровки вручну.   <br>
**Діапазон:** [0...100], **Шумів** - нормальна кількість.
   
- `getBatteryBars()`   <br>
Беремо відсоток і застосовуємо до нього гістерезис, ігноруючи дрібні зміни відсотка.   <br>
На основі відсотка рахуємо кількість "палочок"   <br>
**Діапазон:** [0...4], **Шумів** - небагато.

- `isBatteryCritical()`
Беремо кількість палочок і дивимось чи годинник в глибокому розряді.   <br>
Якщо в глибокому - перевіряємо ще раз.   <br>
**Діапазон:** [0...1], **Шумів** - не повинно бути.

### Як прошити годинник
<p align="center">
 
<img src="Photos/flasher-complete.png" height=200"/> 
</p>
Найпростіший спосіб - скористатись програмою флешером.  <br>
В релізі можна знайти готову програму яка вже включає в себе файли з потрібною прошивкою.  <br>
Потрібно тільки підключити годинник в режимі прошивки і далі слідувати інструкції.     <br>
   
### Як скомпілювати прошивку
- Скачати **VSCode** (У мене 1.89.1)
https://code.visualstudio.com/docs/?dv=win64user
- Встановити розширення **PlatformIO** (у мене Core 6.1.15·Home 3.4.4)   
Extensions -> в пошук "PlatformIO IDE" -> Install
- Встановити платформу **Espressif 32** (у мене Core 6.6.0)
PlatformIO Home (Відкривається при запуску) -> бокове меню Platforms -> Emnedded -> в пошук "Espressif 32" -> Install
- Відкрити проект **Firmware\DRM Watch 3**
PlatformIO Home (Відкривається при запуску) -> Open Project -> знайти і обрати папку "Firmware\DRM Watch 3"
- Далі коли проект відкрився, внизу натиснути **"Upload"**
Після цього PlatformIO скачає купу всього ще, щоб зібрати прошивку і скомпілить прошивку. Перший раз компілитиме довго, наступні рази буде швидше. 
І Після цього він спробує залити прошивку на підключений по USB годинник.

### Як додати іконку і використати її в меню


**Загалом послідовність така:**
- Мати іконку 24х24 пікселі, зберегти її в форматі **монохромному BMP форматі**;
- Відкрити програму **LCDAssistant.exe**.
- **Load Image** - Обираємо монохромний BMP файл. Файл відкривається, бачимо що показується правильно.
- **Byte orientation** обираємо **Horizontal**.
- **Save Output** - обираємо текстовий файл куди збережемо код.
- Код вставляємо в файл **Icons.ino** (можна звісно інший, але в цьому проекті так прийнято).
- Формуємо для іконки `draw_` функцію за прикладом інших іконок.
- Вставляємо нашу `draw_` функцію в відображення меню.
- Готово. Компілюємо і має працювати.

**Відео як це зробити:**   <br>
(відео таке трішки простеньке, але суть передає)   <br>
https://www.youtube.com/watch?v=P4BCf7cneI8   <br>

### Як додати до прошивки свою мелодію:


1) Знайти мелодію. Це має бути midi файл у якого один із інструментів має містити мелодію повністю. 
Я для пошуку мелодій використовую сайт https://onlinesequencer.net/sequences . Там же можна підправити мелодію щоб вона краще підійшла для годинника.
2) Конвертувати мелодію в формат мелодій годинника. Для цього я дещо модифікував інструмент від ShivamJoker, який тепер генерує мій формат мелодій. Конвертер знаходиться в папці `Software\MIDI-to-Arduino-main`. Для його роботи встановіть NodeJS собі на комп.	
3) В файлі `MelodyPlayer.ini` додаємо масив даних мелодії в файл а також додаємо мелодію та її ім'я до масиву `melodies`. 
4) Цього має бути достатньо. Компілюємо прошивку і має з'явитись нова мелодія.

Зауважу, що після додавання нової мелодії, вона посуне індекси попередніх мелодій і якщо мелодія була обрана для будильника, вона зміститься.    <br>

Я записав відео процесу додавання мелодії:   <br>
https://www.youtube.com/watch?v=u_XPCM6kgQM

Формат масиву:   <br>
- Додатнє число - частота в Гц який потрібно вітворити
- Від'ємне число - час, скільки треба тримати частоту. Від'ємне число після частоти - тривалість частоти. Якщо від'ємних кілька підряд то це паузи.
- 19 - ідентифікатор кінця мелодії. Його треба ставити обов'язково бо система почне відтворювати сміття із оперативки.

### Відомі конфлікти між бібліотеками або пінами
- Temperature measurement is hanging system if after Wi-Fi usage it were not initialized.
- Pin D17 - Stays ON when firmware update
- Pin D31 - Used for flash communication
- Pin D32 - Used for flash communication

## Цікаві факти:
- Щоб загнати в режим прошивки ESP32-S2 достатньо підключитись до неї по COM порту з баудом 1200.
- Процес маркування металевого корпусу: https://youtube.com/shorts/PZIMB8fdEP8?si=xofTaj4oOFBRnQQU

## Посилання на ресурси

- Дякую за код для "Вогню": https://github.com/BOOtak/dct3ngine/blob/master/src/games/perlin_test

- Big repository of phone melodies where I found some melodies
http://onj3.andrelouis.com/phonetones/unzipped/

- Vibration implementation
https://makeabilitylab.github.io/physcomp/advancedio/vibromotor.html

## Історія проекту
- 2023 рік: я десь наткнувся на відео про sharp memory lcd зрозумів, що дуже хочу собі такий дисплей. Замовив на алі.
- 2023 кінець року: Таки дійшои руки до замовленого дисплея, було бажання розібратись з проектуванням плат, тож я спробував створити свій перший проект в KiCad.
- 2024 рік, в новорічну ніч я програмував перший прототип, який ще навіть не мав своєї плати, був зібраний на картонці.
- 2024 рік, вечорами після роботи по невеличкій частинці на день я покращував прошивку

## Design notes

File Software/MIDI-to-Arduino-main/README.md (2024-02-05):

# MIDI-to-Arduino
Convert MIDI files into arduino code

Website - https://arduinomidi.netlify.app

## Video Demo

https://user-images.githubusercontent.com/23727670/130347699-c570263c-faeb-4b81-9385-85230c25dcc2.mp4

Запустить очень легко

Тебе нужно скачать и установить nodejs (это  для js )

https://nodejs.org/en/download/current

После чего тебе нужно зайти из консоли в проект

и запустить npm install

Это установка зависимостей

После чего npm start

И оно у тебя запустится

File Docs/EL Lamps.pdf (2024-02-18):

Seite 1 von 20

LUMITEC LTD | Tel. ++41 71 791 07 37 | DATSSAGA_E
Strahlholz 13 | Fax ++41 71 793 14 23 | E/A: 18.07.18 RT
CH-9056 Gais | E-Mail mail@lumitec.ch | G+F: 18.07.18 EE

## General Information about Electroluminescent Lamps

Characteristics of EL-Lamps | 2
1. Capacity of an EL-lamp
2. What’s the appearance of the replace control circuit of an EL-lamp?
3. How can the EL-cristals be stimulated?
4. Requirements of operation voltages
5. The mentioned characteristics of the EL-lamp lead to following
conclusions for EL-drivers: | 2
| 3
| 4
| 5
| 5
Definitions for EL-Lamps | 6
EL-Driver Technologies for EL-Lamps | 10
1. Self swinger
1.1. Self swinger circuit
1.2. Specifications E040 601X
2. PWM-Inverter
2.1. EL-driver from DC-supply, with output power of about 10VA with transformer or transferrable at the output
2.2. EL-driver ELD-76
| 10
| 10
| 11
| 12
| 13
| 14

Seite 2 von 20

LUMITEC LTD | Tel. ++41 71 791 07 37 | DATSSAGA_E
Strahlholz 13 | Fax ++41 71 793 14 23 | E/A: 18.07.18 RT

### Characteristics of EL-Lamps

### 1. Capacity of an EL-lamp

The EL-lamp is actually a light capacitor. For this reason the term "LEC" (Light-Emitting-Capacitor) would be more suitable analogous to the term "LED" (Light-Emitting-Diode). From the point of view of the supply we are mainly concerned with a capacitive load, precisely with a disk capacitor. The disk capacitor has the following structure:

electrode 1

dielectric εr

electrode 2

Between the two electrodes 1 and 2 with the distance s there is the so-called dielectric with a permeability number εr

. The unity for the capacity of the capacitor is Farad. We define the capacitor "C" with the following formula:

# C = ε0 x εr x A / s

The units have the following meaning as written below:

ε0 is the electric field constant with the quantity 8,85 x 10-12As/Vm

εr
is the permeability number which is determined by the material between the electrodes

Seite 3 von 20

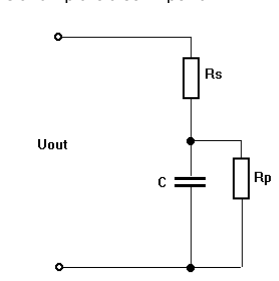
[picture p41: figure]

LUMITEC LTD | Tel. ++41 71 791 07 37 | DATSSAGA_E
Strahlholz 13 | Fax ++41 71 793 14 23 | E/A: 18.07.18 RT
A | is the real capacitor surface
s | is the distance between the two electrodes

How can you influence the capacity when you produce an EL-lamp?

Capacity index of an EL-lamp:

Cpassive 0,2 - 0,5 nF/cm²
i.e. measured with a C-measuring instrument (approx. 0,5V at approx. 800Hz) Cactive 0,3 - 0,6 nF/cm²
i.e. measured while operating
(e.g. 110V 400Hz)

### 2. What’s the appearance of the replace control circuit of an EL-lamp?

Apart of the capacity respresenting a dominant quantity, the two resistances Rs and Rp are also important.

Seite 4 von 20

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

The series resistance Rs is determined by transmission resistance, transition resistance of the connections, electrode resistance and light emission. The values are around 100kOhm x cm2.

Seite 5 von 20

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

The parallel resistance Rp has in fact more than 100MOhhm which is very much, but is still small enough to enable the capacitor to discharge after switching off.

The capacitive blind resistance depends on the frequency and has the following formula: Xc =1/2xπxfxC.

### 3. How can the EL-cristals be stimulated?

In principle the EL-lamp emits light in dependance of the electrical current. The current however can only flow by changing the voltage at the electrodes. Therefore an EL-system can only be operated with alternative voltage.

The current is influenced by two parameters. On the one hand by the amplitude of the voltage and on the other hand by the frequency of the change of polarity in function of time, i.e. the frequency of supply voltage.

A big advantage of EL-lamps are the short reaction times. The delay in switching on of the light emission is neglectible with the EL-systems of nowadays and the delay in switching off is about 100µs. Because of that the useful maximum frequency is about 3000Hz. Exceeding this frequency the efficiency decreases extremely due to overstimulation.

The luminousity of EL-lamps is specified in luminous intensity [cd/m2].

Seite 6 von 20

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

### 4. Requirements of operation voltages

EL-lamps being produced with the paste of Du Pont, so-called EL-thick-coat-systems start emitting the cristals at about 20VAC. Not until this voltage, a field power is reached which stimulates the electrons enough and therefore releases a light emission.

The maximum voltage depends on the construction of the EL-lamp. At high-voltage systems up to 200Veff can be set up.

### 5. The mentioned characteristics of the EL-lamp lead to following

conclusions for EL-drivers:

1. At a defined EL-system the quantity of the capacity depends on the
illumination surface. With it the driver load is proportionally to the illumination surface.
2. Several lamps can be connected at the same supply. The entire capacity is the total sum of all single capacities.
3. At a serial circuit a voltage distribution occurs in opposite proportion to single capacities. Normally this kind of operation is
only used for special cases.
4. A phase angle between 80° and 87° results from the dominant influence of the capacity in proportion to the resistances Rs and
Rp. Because of that there flows practically only reactive current
and there is no heat in the EL-lamp.
5. Efficient operating frequences are between 200 and 3000Hz.
6. The sector of operation voltage of an EL-lamp extends to 20 up to

Seite 7 von 20

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

150VAC.

Seite 8 von 20

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

### Definitions for EL-Lamps

Nominal Supply Conditions
All the values of the parameters of the current supply, from which the nominal characteristics are derived and where the lamp produces the nominal output.

The parameters, where the values are specified in the product norm, are as follows:

- Nominal voltage [V eff]
- Nominal frequency [Hz]
- Form of signals

Nominal Current Intensity [A]
Effective alternative current, which is absorbed from the lamp under nominal supply conditions.

Nominal Current Intensity related to Surfaces [A/m²]
Effective alternative current which is absorbed from the surface unity of the lamp under nominal supply conditions.

Power Factor
Cosine of the angle of phase displacement at sine wave supply between the absorbed current and the regulated tension under nominal supply conditions.

Apparent Nominal Power [VA]
Product from nominal tension and nominal current intensity.

Seite 9 von 20

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

Apparent Nominal Power related to Surfaces [VA/m²]
Product from nominal tension and nominal current intensity relating to the surface.

Nominal Luminance [cd/m²]
Luminance of the electroluminescent lamp under nominal supply conditions.

Useful Luminance [cd/m²]
Value of the luminance according to the specific application conditions.

Half-Life [h]
Number of operation hours under nominal supply conditions to reach half of the value of nominal luminance.

Useful Life [h]
Number of operation hours during which the electroluminescent lamp at nominal frequency supplied with nominal tension (not exceeding nominal tension) can be hold on the value of useful luminance.

Emission Spectrum
Representation of the energetic allocation as function of the wavelength which has been emitted by the electroluminescent lamp under nominal supply conditions.

Luminance-Constancy [%]
Luminance fluctuations related to the nominal value of the illuminated surface of the electroluminescent lamp under nominal supply conditions.

Lead Wavelength [nm]

Seite 10 von 20

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

Wavelength of the energetic emission-maximum of the electroluminescent lamp under nominal supply conditions.

Leading Wavelength [nm]
Wavelength of the monochromatic radiation of the same colour as the illuminated surface of the electroluminescent lamp under nominal supply conditions.

Seite 11 von 20

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

Chromatic Coordinates
Chromatic coordinates (x, y or u`, v`), fixed in the chromatic spectrogramme C.I.E. 1931 (standard observer 20 or C.I.E. 1976), of the electroluminescent lamp under nominal supply conditions.

Energetic Luminance [W/m²/sr]
Energy which is radiated from the electroluminescent lamp under nominal supply conditions.

Luminous Power [Im/W]
Light flow emitted by the electroluminescent lamp under nominal supply conditions related to the active absorbed efficient power.

Efficiency [cd/VA]
Quotient of the luminance under effective illumination surface divided by the apparent power.

Capacity [F]
Capacity of the electroluminescent lamp under nominal supply conditions.

Capacity related to Surfaces [F/m²]
Capacity per unit of illumination surface of the electroluminescent lamp under nominal supply conditions.

Width of Margins [mm]
Dimensions of the non-luminous external limits of the electroluminescent lamp.

Seite 12 von 20

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

Minimal Curve Radius [mm]
Smallest radius which can be accepted by a flexible electroluminescent lamp without deterioration of its power.

Seite 13 von 20

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

Looks
The way of presentation of an electroluminescentlamp at visual inspection.

Visible Faults
Visible defects, especially in the luminous surface which can affect the performance.

Seite 14 von 20

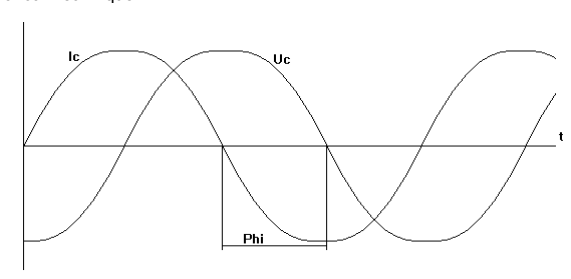
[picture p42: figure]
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

### EL-Driver Technologies for EL-Lamps

### 1. Self swinger

At an adapted EL-lamp the self swinger has got a similar current to sine, preceding the voltage by almost 90°. EL-drivers ELD-40 are based on this circuit technique.

### 1.1. Self swinger circuit

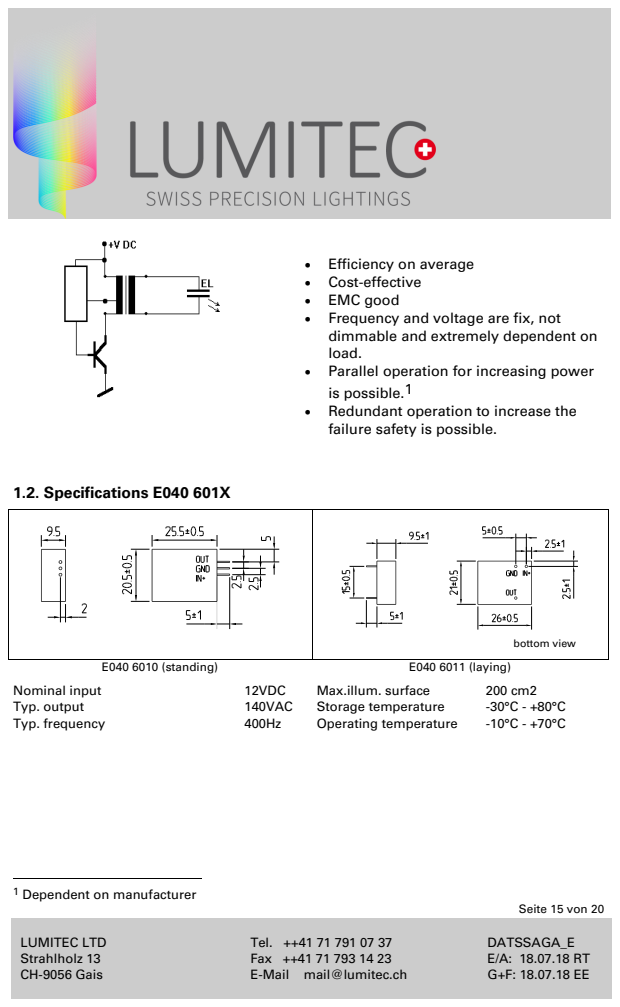
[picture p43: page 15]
Seite 15 von 20; LUMITEC LTD Strahlholz 13; Tel. ++41 71 791 07 37 Fax ++41 71 793 14 23; DATSSAGA_E E/A: 18.07.18 RT; 1.2. Specifications E040 601X; bottom view; E040 6010 (standing); E040 6011 (laying); Nominal input; 12VDC; Typ. output; 140VAC; Typ. frequency; Max.illum. surface; Storage temperature; Operating temperature

• Efficiency on average
• Cost-effective
• EMC good
• Frequency and voltage are fix, not
dimmable and extremely dependent on
load.
• Parallel operation for increasing power
is possible.1
• Redundant operation to increase the
failure safety is possible.

1 Dependent on manufacturer

Seite 16 von 20

LUMITEC LTD
Strahlholz 13

Tel. ++41 71 791 07 37
Fax ++41 71 793 14 23

DATSSAGA_E
E/A: 18.07.18 RT

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
0 | 25 | 50 | 75 | 100 | 125 | 150 | 175 | 200 | 225

Illum. Surface [cm²

2

]

Pin=640mW Uout=170V f=810Hz

| Pin=850mW Uout=140V f=610Hz
Pin=350mW Uout=130V f=780Hz | | Uin=16V
| Pin=450mW Uout=110V f=580Hz | | Pin=1210mW Uout=120V f=470Hz | | Pin=1450mW
Pin=150mW Uout=90V f=780Hz | | Uin=12V | Pin=640mW Uout=100V f=440Hz | ] Luminous Intensity [cd/m | Uout=110V f=420Hz | Pin=1690mW Uout=100V f=380Hz
| Pin=190mW Uout=80V | Uin=8V | | | Pin=740mW Uout=90V f=390Hz | Pin=860mW Uout=80V f=350Hz
| f=580Hz | | Pin=260mW Uout=70V f=440Hz | | Pin=310mW Uout=60V f=380Hz | Pin=360mW Uout=60V f=340Hz

The values on the above diagram are based on the following EL-datas:

ELF 2006

Colour
Emission max.
C passive
C active

green-blue
500nm
0.25 nF/cm2
0.39 nF/cm2 @ 100V 400Hz

Attention: Running on the spot or short circuit can damage the EL-Driver!

### 2. PWM - Inverter

The meaning of PWM is Pulse-Wide-Modulation. With this way of circuit any EL-lamp can be driven with an accurately definite frequency. An ideal harmonic current curve is caused for the EL-lamp. The Full Costum ASIC ELD-

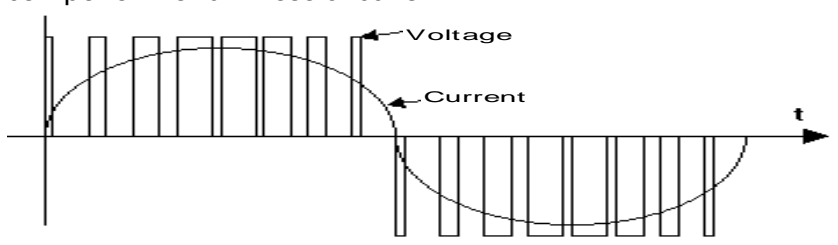
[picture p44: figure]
Voltage; Current

Seite 17 von 20

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

76 which has been developped by ENZ-Electronic AG offers an optimum main component for all these circuits.

Seite 18 von 20

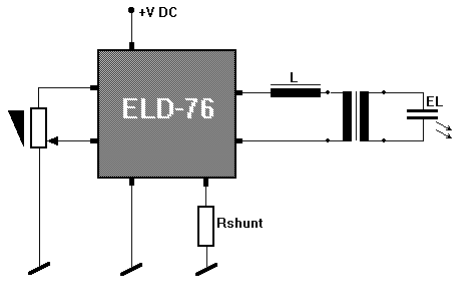
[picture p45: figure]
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

### 2.2.1. EL-driver from DC-supply, with output power of about 10VA with

transformer or transferrable at the output

Characteristics: high efficiency, galvanic separation, dimmable, 200 - 2800Hz

Seite 19 von 20

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

### 2.2. EL-Driver ELD-76

The driver ELD-76 is a full custom ASIC for controlling thickfilm electroluminescent lamps via transformator. The ASIC is available in DIE form and with PLCC44 case.

Main Characteristics
- High current driver up to 0.5A
- Wide supply voltage range from 4.5V to 35V
- Overload protection
- High efficiency through PWM
- Integrated 5V - Low Drop voltage regulator
- Thermal overload protection, fault output
- Eight output frequencies digitally selectable from 200 Hz to 2800 Hz
- Flash mode with three flash intervalls from 1.4 Hz to 5.5 Hz
- Output voltage adjustable by means analog and digital (PWM)
- Softstart
- Appropriate for control of output voltage or luminous intensity
- Mode selectable for external high current driver
- Noise filter guarantees high quality sine wave
- Input/output isolation through transformator

Block Diagram

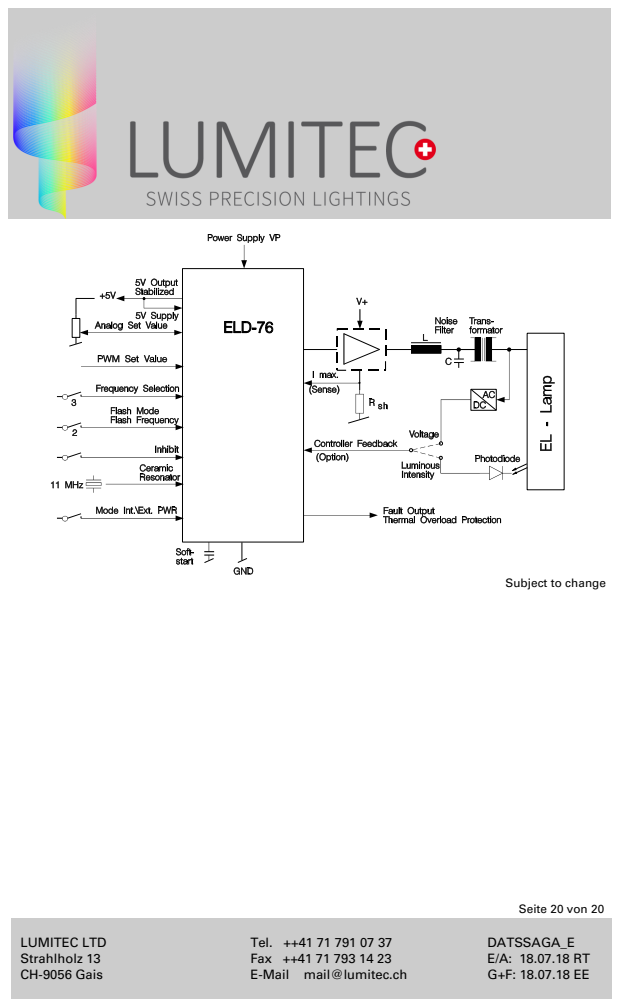
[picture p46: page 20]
Seite 20 von 20; LUMITEC LTD Strahlholz 13; Tel. ++41 71 791 07 37 Fax ++41 71 793 14 23; DATSSAGA_E E/A: 18.07.18 RT

Subject to change

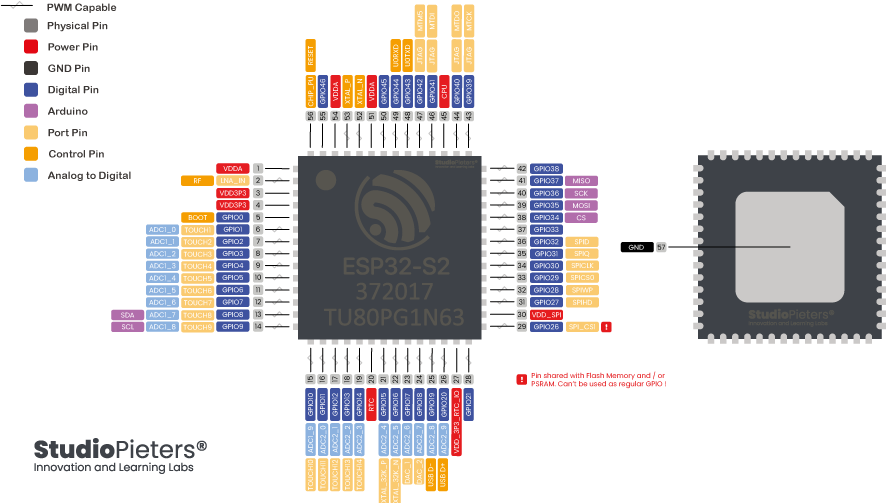
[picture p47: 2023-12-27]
Docs/ESP32-S2-FQN-PINOUT.png

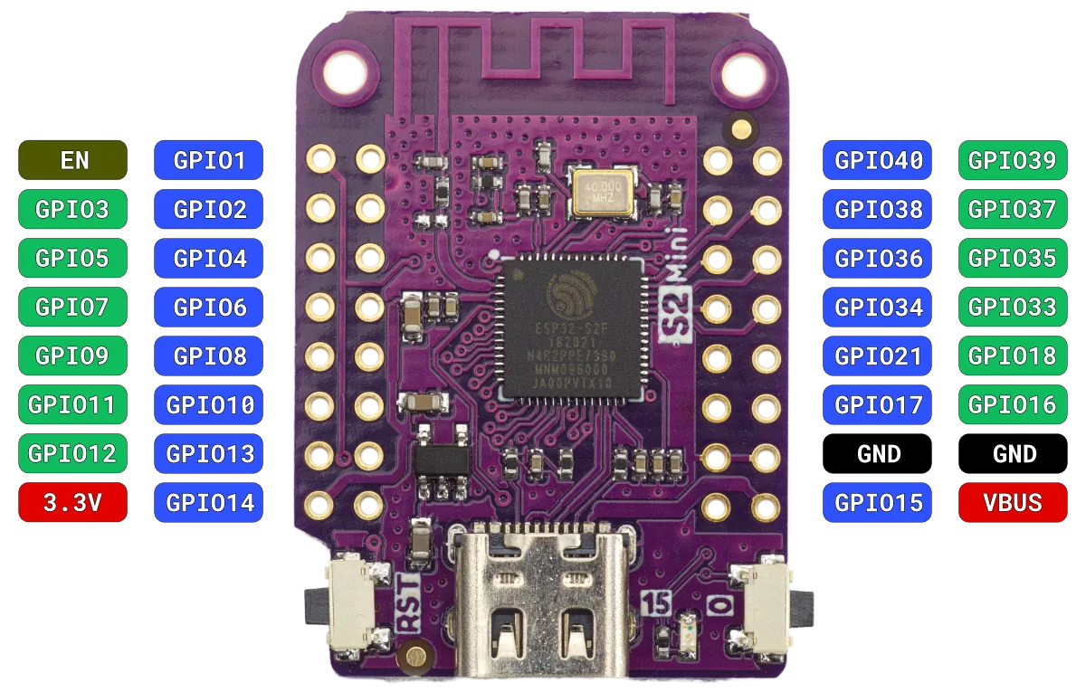
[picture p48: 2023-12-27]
Docs/Wemos_S2_mini_EPS32_pinout.webp

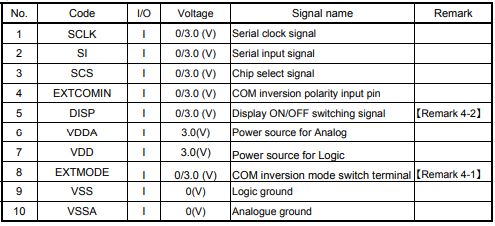
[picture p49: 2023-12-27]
Docs/sharp_lcd_display_pinout_ls013b7dh03.jpg

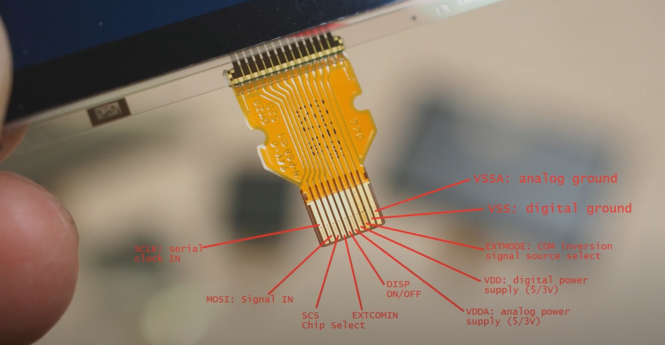
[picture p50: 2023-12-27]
Docs/Screenshot 2023-10-03 204709.png

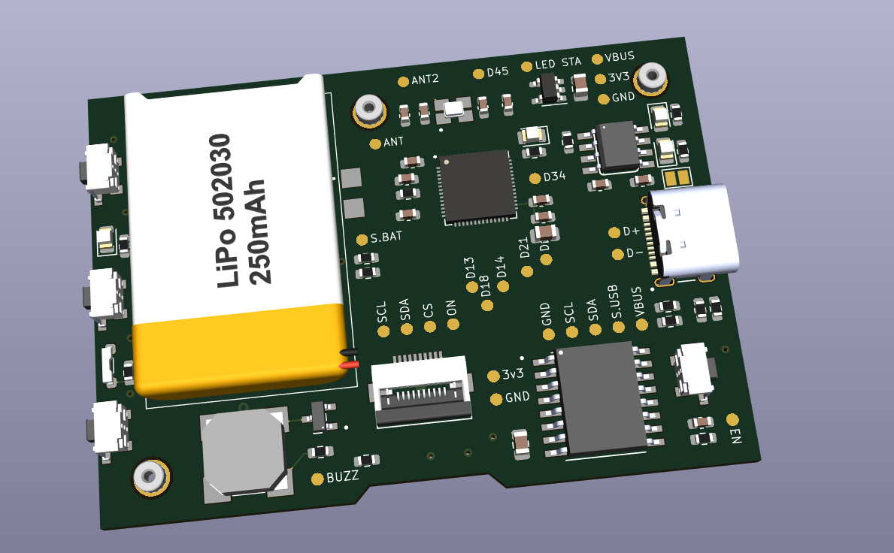
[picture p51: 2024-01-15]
Board/Photos/Screenshot 2024-01-14 222454.png

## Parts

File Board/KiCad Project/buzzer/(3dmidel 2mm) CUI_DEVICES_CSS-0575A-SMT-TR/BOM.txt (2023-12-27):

3DX_CUI_DEVICES_Supplier: CUI Devices
3DX_CUI_DEVICES_Description: 5 mm, 3 V, 76 dB, Surface Mount (SMT), Magnetic Audio Transducer Buzzer
3DX_CUI_DEVICES_Model Number: CSS-0575A-SMT-TR

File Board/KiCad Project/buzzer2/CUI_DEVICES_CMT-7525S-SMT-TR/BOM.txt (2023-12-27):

3DX_CUI_DEVICES_Supplier: CUI Devices
3DX_CUI_DEVICES_Description: 7.5 mm, 3.6 Vo-p, 90 dB, Surface Mount (SMT), Magnetic Audio Transducer Buzzer
3DX_CUI_DEVICES_Model Number: CMT-7525S-SMT-TR

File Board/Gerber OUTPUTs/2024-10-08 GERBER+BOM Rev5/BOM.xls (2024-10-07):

Column1 | Column2 | Column3 | Column4 | Column5 | Column6 | Column7 | Column8 | Column9 | Column10 | Column11 | Column12 | Column13
Date: | 08/10/2024 00:11:06
Tool: | Eeschema 7.0.9
Component Count: | 68
Collated Components:
Item | Qty | Reference(s) | Value | LibPart | Footprint | Datasheet | DNP | Description | Link | Link2 | Manufacturer | Role
1 | 1 | C1 | 0.1uF | Device:C | Project-Lib:C_0805_2012Metric | ~ |  | Unpolarized capacitor | https://www.aliexpress.us/item/1005006124283234.html |  |  | Voltage stabilizer capacitor for 3v3
2 | 3 | C2, C3, C13 | 10pF | Device:C | Project-Lib:C_0603_1608Metric | ~ |  | Unpolarized capacitor | https://www.aliexpress.us/item/1005006124283234.html |  |  | Capacitor for oscilator
3 | 4 | C4, C5, C6, C8 | 0.1uF | Device:C | Project-Lib:C_0603_1608Metric | ~ |  | Unpolarized capacitor | https://www.aliexpress.us/item/1005006124283234.html |  |  | Voltage stabilizer capacitor for 3v3
4 | 2 | C7, C14 | 1uF | Device:C | Project-Lib:C_0603_1608Metric | ~ |  | Unpolarized capacitor | https://www.aliexpress.us/item/1005006124283234.html |  |  | Voltage stabilizer capacitor for VDD_SPI
5 | 3 | C9, C10, C19 | 1uF | Device:C | Project-Lib:C_0805_2012Metric | ~ |  | Unpolarized capacitor | https://www.aliexpress.us/item/1005006124283234.html |  |  | Voltage stabilizer capacitor for VBAT
6 | 3 | C11, C12, C15 | 10uF | Device:C | Project-Lib:C_0603_1608Metric | ~ |  | Unpolarized capacitor | https://www.aliexpress.us/item/1005006124283234.html |  |  | Capacitor for vbat
7 | 1 | C16 | 12nF 200V | Device:C_Small | Project-Lib:C_1206 | ~ |  | High voltage unpolarized capacitor SMD 1206 12nF 200V | https://www.aliexpress.us/item/1005004628006766.html |  |  | Complementary component for EL driver chip
8 | 1 | C17 | 4.7uF | Device:C_Small | Project-Lib:C_1206 | ~ |  | Unpolarized capacitor | https://www.aliexpress.us/item/1005006124283234.html |  |  | Input capacitor
9 | 1 | C18 | 0.1uF | Device:C_Small | Project-Lib:C_1206 | ~ |  | Unpolarized Capacitor | https://www.aliexpress.us/item/1005006124283234.html |  |  | Input capacitor
10 | 2 | D1, D4 | LED RED | Device:LED | Project-Lib:HOLE_LED_0805_2012Metric | ~ |  | SMD 0805 LED Color RED | https://www.aliexpress.us/item/4000936781234.html |  |  | LED TOP
11 | 1 | D2 | 020 SMD Side View LED White 6000K | Device:LED | Project-Lib:SMD-LED-Side-View | ~ |  | SMD 020 Side View bright LED | https://www.aliexpress.us/item/32419907074.html |  |  | Flashlight, Led bottom
12 | 2 | D3, D5 | LED BLUE | Device:LED | Project-Lib:HOLE_LED_0805_2012Metric | ~ |  | SMD 0805 Blue LED | https://www.aliexpress.us/item/4000936781234.html |  |  | LED STBY
13 | 2 | D6, D7 | US1D | Diode:US1D | Project-Lib:US1D | https://www.diodes.com/assets/Datasheets/ds16008.pdf |  | SMD schottky diode | https://www.aliexpress.us/item/1005005254835443.html |  |  | Complementary part for EL driver chip
14 | 1 | J1 | TYPE-C-31-M-12 | Project-Lib:TYPE-C-31-M-12 | Project-Lib:HRO_TYPE-C-31-M-12 | https://www.lcsc.com/datasheet/lcsc_datasheet_2205251630_Korean-Hroparts-Elec-TYPE-C-31-M-12_C165948.pdf |  | USB Type-C Connector | https://jlcpcb.com/partdetail/Korean_HropartsElec-TYPE_C_31_M12/C165948 | https://www.snapeda.com/parts/TYPE-C-31-M-12/HRO+Electronics+Co.%252C+Ltd./view-part/?ref=snap | HRO Electronics Co., Ltd. | USB Port for charging and update
15 | 1 | J2 | FPC 10pin 0.5mm pitch | Project-Lib:687110149022 | Project-Lib:687110149022 |  |  | FPC Connector 10 pin 0.5mm pitch | https://www.aliexpress.us/item/10000348360254.html |  |  | LCD Connector
16 | 1 | L1 | 220uH | Device:L | Project-Lib:Inductor-L_1210_3225Metric | ~ |  | 220uH SMD 1210 Inductor | https://www.aliexpress.us/item/32981310345.html |  |  | Complementary part for EL driver chip
17 | 1 | LS1 | CMT-7525S-SMT | Project-Lib:CMT-7525S-SMT | Project-Lib:CUI_CMT-7525S-SMT | https://eu.mouser.com/datasheet/2/670/cmt_7525s_smt_tr-1777280.pdf |  | 7.5 mm, 3.6 Vo-p, 90 dB, Surface Mount (SMT), Magnetic Audio Transducer Buzzer | https://www.aliexpress.us/item/1005003620083880.html | https://eu.mouser.com/ProductDetail/CUI-Devices/CMT-7525S-SMT-TR?qs=qCxwlXJ4fnw4ZHFvNib47A%3D%3D | CUI Devices | Buzzer to play sound
18 | 3 | M1, M2, M3 | Brass SMTSO-M1.4X3X1.5-2X0.8 | Project-Lib:screwMount | Project-Lib:m1.4-screw-mount |  |  | M1.4 screw mount get from DJI Mavic 3 CORE board | https://www.aliexpress.com/item/1005005579653583.html |  |  | Screw mount for back case
19 | 1 | Q1 | 2N7002LT1G (SOT-23-3) | :2N7002LT1G_1 | Project-Lib:SOT95P240X111-3N | https://www.rcscomponents.kiev.ua/datasheets/2n7002lt1g.pdf |  | 2N7002 N-Channel MOSFET, SOT-23-3 Package | https://www.aliexpress.us/item/1005003909614901.html | https://www.aliexpress.us/item/1005003079655220.html | ON Semiconductor | Driving MOSFET for buzzer
20 | 1 | Q2 | 2N7002LT1G (SOT-23-3) | Project-Lib:2N7002LT1G | Project-Lib:SOT95P240X111-3N | https://www.rcscomponents.kiev.ua/datasheets/2n7002lt1g.pdf |  | 2N7002 N-Channel MOSFET, SOT-23-3 Package | https://www.aliexpress.us/item/1005003909614901.html | https://www.aliexpress.us/item/1005003079655220.html | ON Semiconductor | Driving MOSFET for Vibro
21 | 4 | R1, R7, R8, R22 | 1K | Device:R | Project-Lib:R_0603_1608Metric | ~ |  | SMD Resistor |  |  |  | Pull-down for buzzer signal
22 | 2 | R2, R3 | 5.1K | Device:R | Project-Lib:R_0603_1608Metric | ~ |  | SMD Resistor |  |  |  | USB Type-C CC Line terminator
23 | 5 | R4, R5, R6, R10, R23 | R22 | Device:R | Project-Lib:R_0603_1608Metric | ~ |  | SMD Resistor | https://www.aliexpress.us/item/1005002364437129.html |  |  | Current-limiting ressitor for buzzer
24 | 1 | R9 | 2K | Device:R | Project-Lib:R_0603_1608Metric | ~ |  | SMD Resistor |  |  |  | Current setting resistor more 1K=1A, 10K=100mA
25 | 4 | R11, R12, R13, R14 | 100K | Device:R | Project-Lib:R_0603_1608Metric | ~ |  | SMD Resistor |  |  |  | Part of voltage divider for battery
26 | 1 | R15 | 0 ohm | Device:R | Project-Lib:R_0603_1608Metric | ~ |  | SMD Resistor |  |  |  | Resistor to antenna
27 | 1 | R16 | 10K | Device:R | Project-Lib:R_0603_1608Metric | ~ |  | SMD Resistor | https://www.aliexpress.us/item/1005002364437129.html |  |  | Pull-Up for ENABLE pin of ESP32
28 | 1 | R17 | 560K | Device:R | Project-Lib:R_0603_1608Metric | ~ |  | SMD Resistor |  |  |  | Complementary part for EL Driver IC
29 | 1 | R18 | 2M | Device:R | Project-Lib:R_0603_1608Metric | ~ |  | SMD Resistor |  |  |  | Complementary part for EL Driver IC
30 | 2 | R19, R20 | 4.3K | Device:R | Project-Lib:R_0603_1608Metric | ~ |  | SMD Resistor |  |  |  | Pull-Up for RTC SDA
31 | 1 | R21 | 500R | Device:R | Project-Lib:R_0603_1608Metric | ~ |  | SMD resistor 500 Ohm |  |  |  | Resistor for reducing audible noize
32 | 4 | S1, S2, S3, S4 | 2*4*3.5mm Micro SMD Tact Switch Side Button | Project-Lib:TL3330AF130QG | Project-Lib:SW_TL3330AF130QG |  |  | SMD Side Tactile Button | https://www.aliexpress.us/item/32880903601.html |  |  | TOP
33 | 1 | U1 | ESP32-S2FN4R2 | Project-Lib:ESP32-S2 | Project-Lib:QFN-56-1EP_7x7mm_P0.4mm_EP4x4mm_ThermalVias | https://www.espressif.com/sites/default/files/documentation/esp32-s2_datasheet_en.pdf |  | ESP32-S2FN4R2 Programmable Microcontroller Chip | https://www.tme.eu/ua/details/esp32s2fn4r2/moduli-iot-wifi-bluetooth/espressif/esp32-s2fn4r2 |  | Espressif | Main controller
34 | 1 | U2 | ME6211 SOT23-5 3.3V | Project-Lib:LDO_ME6211 | Project-Lib:ME6211 SOT-23-5 | https://pdf1.alldatasheet.com/datasheet-pdf/download/1138839/ETC2/ME6211.html |  | 3.3V Step-Down DC-DC Voltage Converter | https://www.aliexpress.us/item/1005006036398325.html |  |  | Step-down voltage converter
35 | 1 | U3 | TP4056 | Project-Lib:TP4056 | Project-Lib:SO08 | https://dlnmh9ip6v2uc.cloudfront.net/datasheets/Prototyping/TP4056.pdf |  | Battery charging TP4056 IC | https://www.alibaba.com/product-detail/TC4056A-SOP-8-is-compatible-with_1600806443781.html |  | Texas Instruments | Battery charger
36 | 1 | U4 | DS3231S | Project-Lib:DS3231S | Project-Lib:SOIC127P1032X265-16N | https://www.analog.com/media/en/technical-documentation/data-sheets/DS3231.pdf |  | SOIC-16 Real Time Clock (RTC) IC Clock/Calendar - IВІC, 2-Wire Serial 16-SOIC (0.295, 7.50mm Width) | https://www.analog.com/en/products/ds3231.html |  | Analog Devices | Handling Time
37 | 1 | U5 | Microchip HV857 | Project-Lib:HV857 | Project-Lib:HV857 | https://ww1.microchip.com/downloads/aemDocuments/documents/APID/ProductDocuments/DataSheets/HV857-High-Voltage-Low-Noise-EL-Lamp-Driver-IC-Data-Sheet-DS200056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 |  | EL Lamp Driver chip | https://www.aliexpress.us/item/1005005512523052.html | https://www.microchip.com/en-us/product/hv857 | microchip | EL Backlight driver IC
38 | 1 | Y1 | 3225 4PIN 40Mhz 3.2*2.5mm Passive SMD Quartz Resonator Crystal | Project-Lib:Oscolator | Project-Lib:Oscilator |  |  | SMD 3225 4PIN 40Mhz 3.2*2.5mm Passive SMD Quartz Resonator 40.000Mhz | https://www.aliexpress.us/item/1005004689346275.html |  |  | Frequency Oscilator

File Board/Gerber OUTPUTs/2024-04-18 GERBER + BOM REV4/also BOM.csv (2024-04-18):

Id | Designator | Footprint | Quantity | Designation | Supplier and ref
1 | R3,R2 | R_0603_1608Metric | 2 | 5.1K
2 | D2 | SMD-LED-Side-View | 1 | 020 SMD Side View LED White 6000K
3 | C18 | C_1206 | 1 | 0.1uF
4 | LS1 | CUI_CMT-7525S-SMT | 1 | CMT-7525S-SMT
5 | R14,R11,R13,R12 | R_0603_1608Metric | 4 | 100K
6 | R6,R23,R10,R5,R4 | R_0603_1608Metric | 5 | R22
7 | M2,M3,M1 | m1.2-screw-mount | 3 | M1.2 screw mount get from DJI Mavic 3 CORE board
8 | C5,C6,C4,C8 | C_0603_1608Metric | 4 | 0.1uF
9 | R19,R20 | R_0603_1608Metric | 2 | 4.3K
10 | C15,C12,C11 | C_0603_1608Metric | 3 | 10uF
11 | R9,R16 | R_0603_1608Metric | 2 | 10K
12 | D3,D5 | HOLE_LED_0805_2012Metric | 2 | LED BLUE
13 | S2,S1,S4,S3 | SW_TL3330AF130QG | 4 | 2*4*3.5mm Micro SMD Tact Switch Side Button
14 | C9,C19,C10 | C_0805_2012Metric | 3 | 1uF
15 | Q1,Q2 | SOT95P240X111-3N | 2 | 2N7002LT1G (SOT-23-3)
16 | R21 | R_0603_1608Metric | 1 | 500R
17 | R17 | R_0603_1608Metric | 1 | 560K
18 | U3 | SO08 | 1 | TP4056
19 | D6,D7 | US1D | 2 | US1D
20 | J2 | 687110149022 | 1 | FPC 10pin 0.5mm pitch
21 | C7,C14 | C_0603_1608Metric | 2 | 1uF
22 | C3,C13,C2 | C_0603_1608Metric | 3 | 10pF
23 | R7,R22,R8,R1 | R_0603_1608Metric | 4 | 1K
24 | U4 | SOIC127P1032X265-16N | 1 | DS3231S
25 | D1,D4 | HOLE_LED_0805_2012Metric | 2 | LED RED
26 | U5 | HV857 | 1 | Microchip HV857
27 | R18 | R_0603_1608Metric | 1 | 2M
28 | C16 | C_1206 | 1 | 12nF 200V
29 | U2 | ME6211 SOT-23-5 | 1 | ME6211 SOT23-5 3.3V
30 | L1 | Inductor-L_1210_3225Metric | 1 | 220uH
31 | C17 | C_1206 | 1 | 4.7uF
32 | R15 | R_0603_1608Metric | 1 | 0 ohm
33 | J1 | HRO_TYPE-C-31-M-12 | 1 | TYPE-C-31-M-12
34 | Y1 | OSC_XRCGB48M000F0Z00R0 | 1 | 3225 4PIN 40Mhz 3.2*2.5mm Passive SMD Quartz Resonator Crystal
35 | REF** | Battery502535 | 1 | Battery502535
36 | U1 | QFN-56-1EP_7x7mm_P0.4mm_EP4x4mm_ThermalVias | 1 | ESP32-S2
37 | C1 | C_0805_2012Metric | 1 | 0.1uF

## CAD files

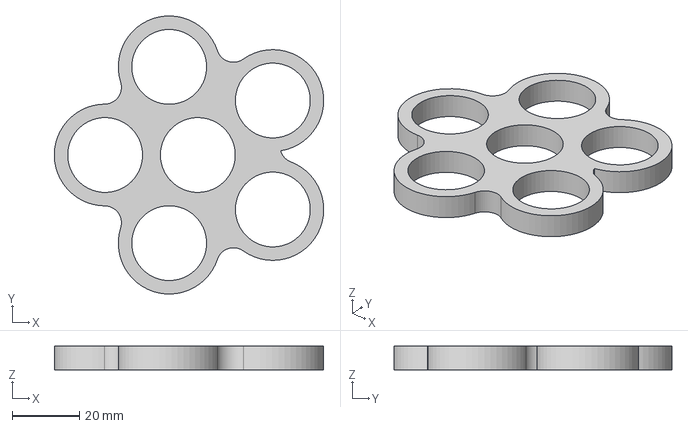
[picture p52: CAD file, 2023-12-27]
Board/KiCad Project/3dmodel-test/2023-12-02 Spinner v2.step
79.9 x 82.5 x 7.00 mm

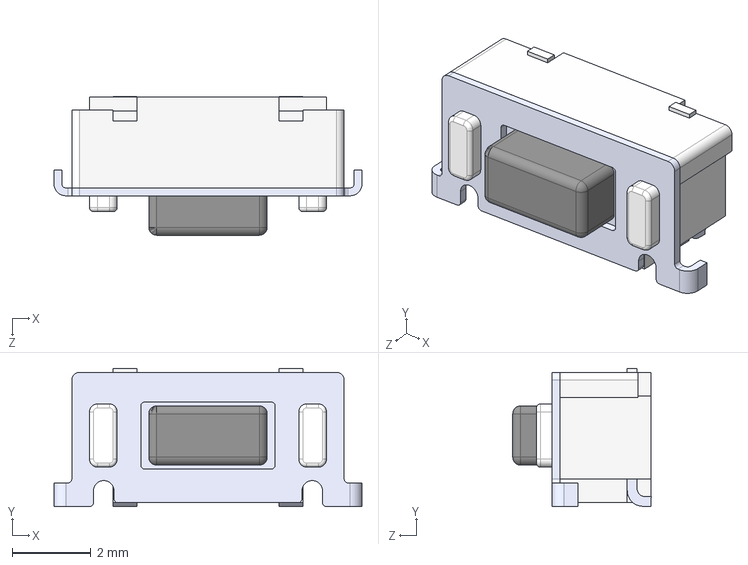
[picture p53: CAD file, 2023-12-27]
Board/KiCad Project/buttons/TL3330AF130QG/TL3330AF130QG.step
7.80 x 3.50 x 3.51 mm

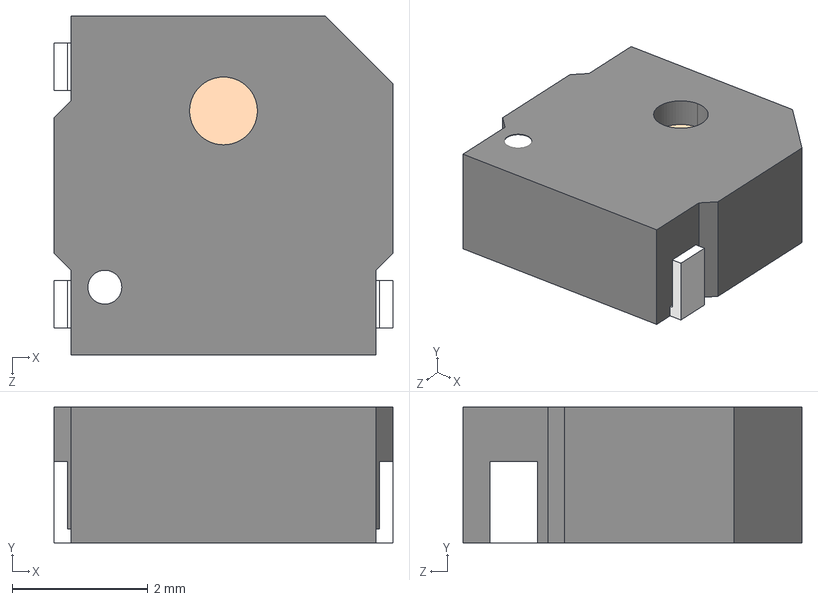
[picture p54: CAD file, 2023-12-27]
Board/KiCad Project/buzzer/(3dmidel 2mm) CUI_DEVICES_CSS-0575A-SMT-TR/CUI_DEVICES_CSS-0575A-SMT-TR.step
5.00 x 2.00 x 5.00 mm

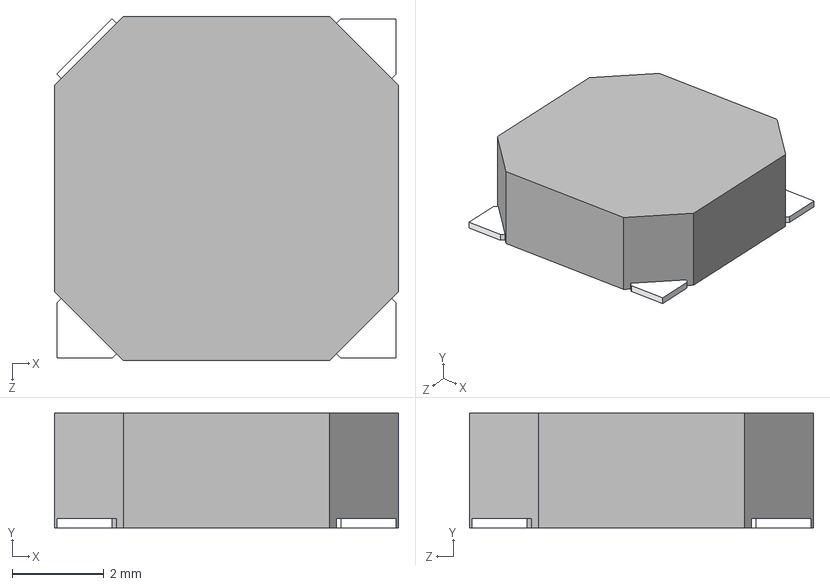
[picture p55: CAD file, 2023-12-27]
Board/KiCad Project/buzzer2/CUI_DEVICES_CMT-7525S-SMT-TR/CUI_DEVICES_CMT-7525S-SMT-TR.step
7.50 x 2.50 x 7.50 mm

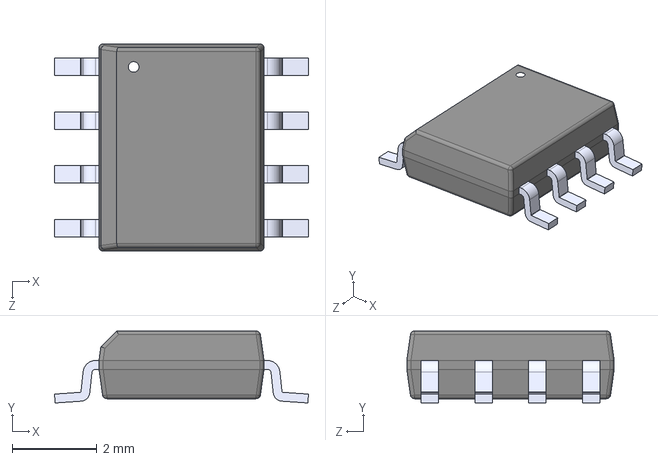
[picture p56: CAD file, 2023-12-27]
Board/KiCad Project/CHARGE/TP4056/TP4056.step
6.00 x 1.70 x 4.90 mm

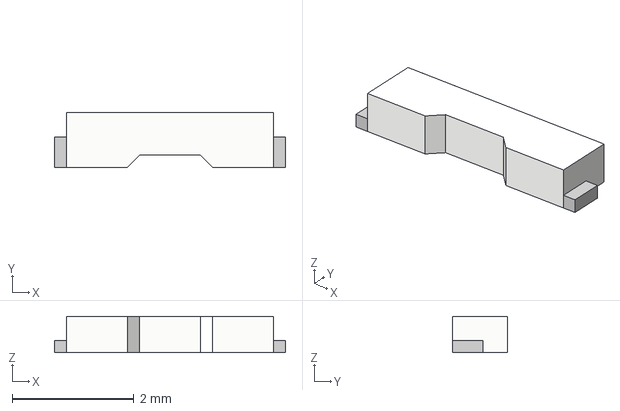
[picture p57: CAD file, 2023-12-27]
Board/KiCad Project/LED/2023-12-17 LED v1.step
3.80 x 0.9 x 0.6 mm

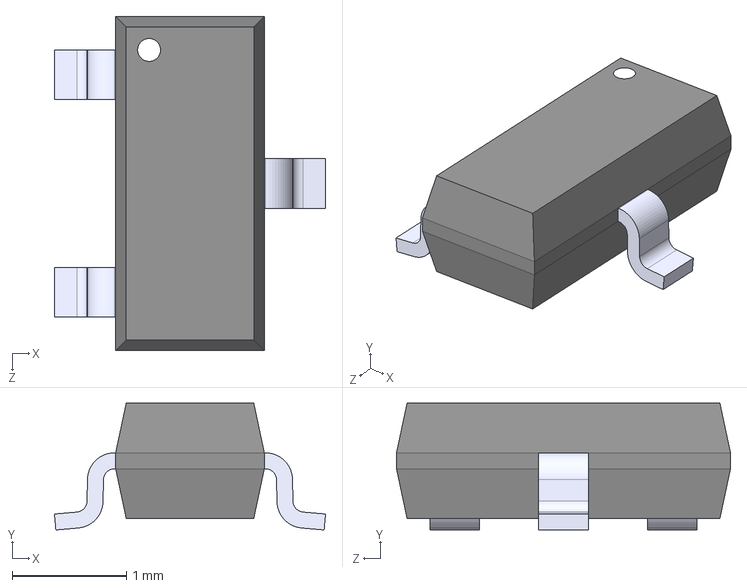
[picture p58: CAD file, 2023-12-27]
Board/KiCad Project/mosfet/2N7002LT1G/2N7002LT1G.step
2.37 x 1.11 x 2.92 mm

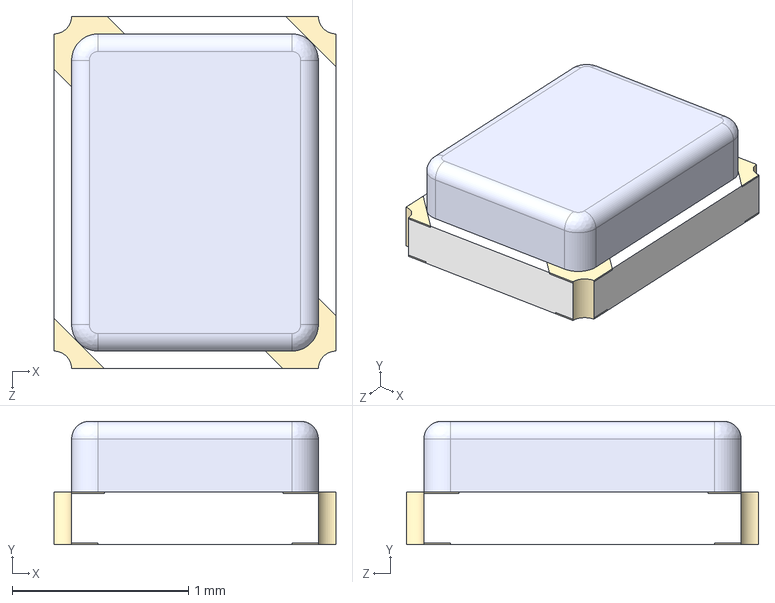
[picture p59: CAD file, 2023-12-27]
Board/KiCad Project/oscillator/XRCGB48M000F0Z00R0/XRCGB48M000F0Z00R0.step
1.60 x 0.7 x 2.00 mm

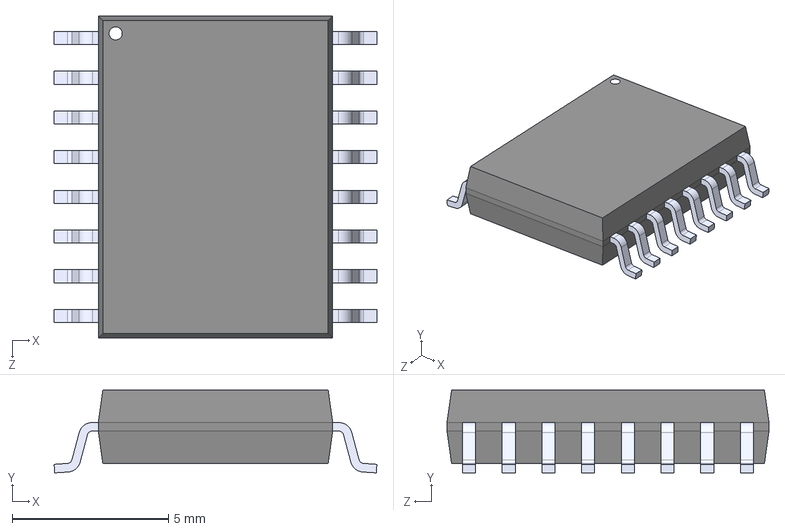
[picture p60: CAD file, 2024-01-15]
Board/KiCad Project/RTC/DS3231S.step
10.3 x 2.65 x 10.3 mm

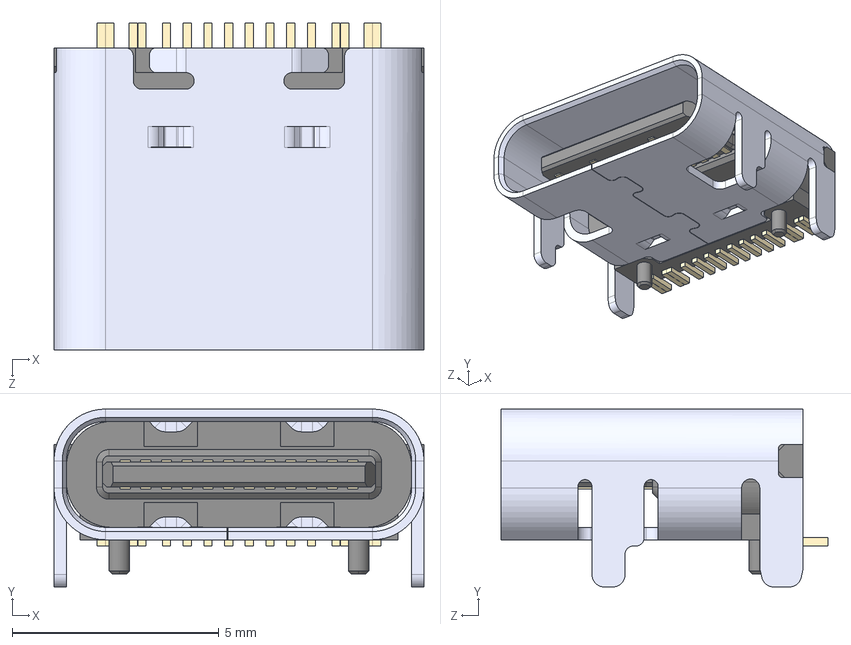
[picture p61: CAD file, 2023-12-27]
Board/KiCad Project/TYPE-C-31-M-12/TYPE-C-31-M-12.step
8.94 x 4.30 x 7.90 mm

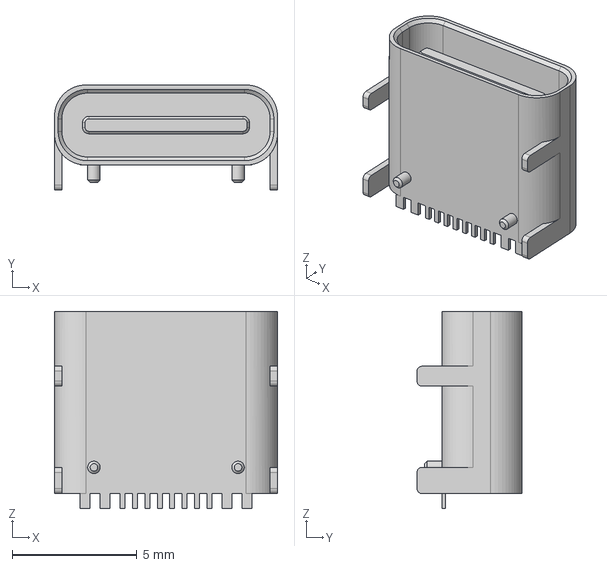
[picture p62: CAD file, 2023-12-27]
Board/KiCad Project/Type-C.pretty-master/Type-C.pretty-master/HRO TYPE-C-31-M-12.step
8.94 x 4.21 x 7.90 mm

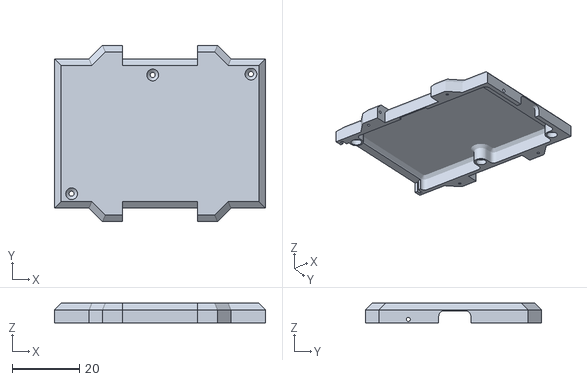
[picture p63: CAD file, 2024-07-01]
Case/2024-07-01 v205 Back.stl
62.7 x 52.4 x 5.80

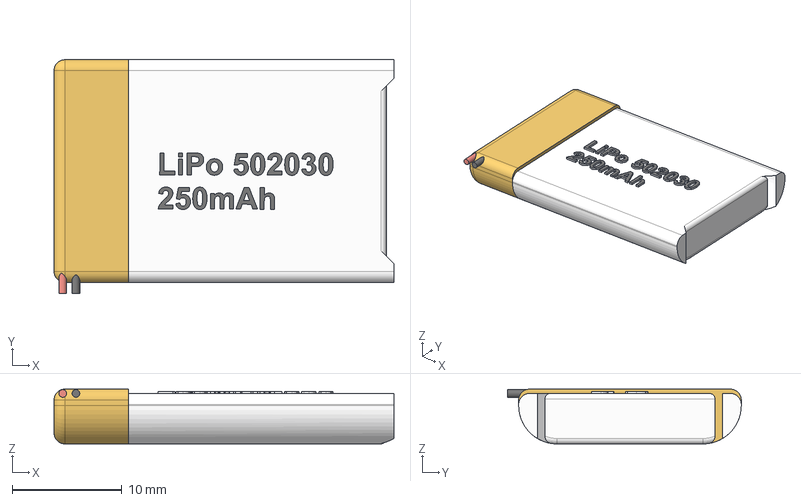
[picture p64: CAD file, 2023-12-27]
Board/KiCad Project/3dmodel-test/2023-12-16 lipo 502030 v1.step
31.0 x 21.3 x 5.00 mm

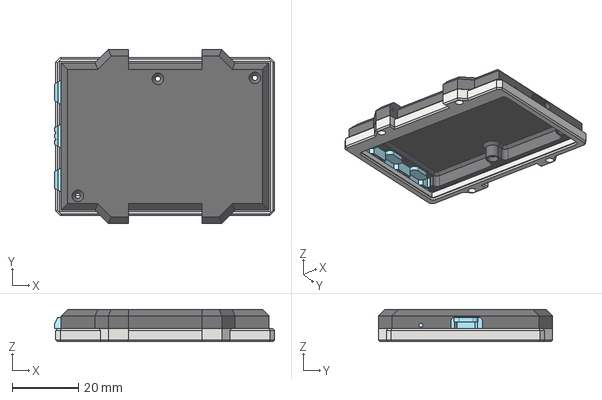
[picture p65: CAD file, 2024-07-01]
Case/2024-07-01 v205 DRM Watch 3.step
66.3 x 52.4 x 9.75 mm

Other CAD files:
Case/2024-04-17 v200 front-case-engraving.dxf
Case/2024-04-17 v200 front-case.step
Case/2024-04-17 v200 newbuttons.stl
Case/2024-04-05 Back Cover Engraving.dxf
Board/KiCad Project/ScrewMount/2023-12-18 M2 Screw Mount v6.step
Board/KiCad Project/ScrewMount/M1.2 Screw Mount v9.step
Board/KiCad Project/ScrewMount/m1.2-screw-mount.stl
Board/KiCad Project/lcd connector/143115216-659-687110149022/687110149022.stp
Case/2024-04-05 Back Cover Engraving.dwg
Case/2024-04-17 v200 front-case-engraving.dwg
Case/2024-04-17 v200 front-case.stl
Case/OLD/2024-01-15 back v184.step
Case/OLD/2024-04-16 Front Cover Engraving With Frame Included.dwg
Case/OLD/2024-04-16 Front Cover Engraving With Frame Included.dxf
Case/OLD/2024-04-16 Front Cover Engraving.dwg
Case/OLD/2024-04-16 Front Cover Engraving.dxf
Case/OLD/2024-04-16 board v190.step
Case/OLD/2024-04-17 board v195.step
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

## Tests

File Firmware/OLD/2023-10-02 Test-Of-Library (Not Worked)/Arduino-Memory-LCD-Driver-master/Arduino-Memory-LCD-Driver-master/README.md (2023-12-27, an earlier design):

# Arduino driver for Sharp Memory LCD #

[Sharp's Memory LCD](https://www.sharpsma.com/products?sharpCategory=Memory%20LCD) is a lightweight display with 1-bit memory in every pixel allowing high-contrast, ultra-thin and at the time same delivering a relatively high frame rate (20Hz max)  at merely microWatt power consumption level.<br>
<br>
Driver compatible with ESP32 and Arduino M0 PRO listed in this repository. Although this driver has been developed for a dedicated [EVK](http://www.techtoys.com.hk/Sharp_MemoryLCD/EVK/Sharp%20Memory%20LCD%20Shield%20-%20User%20Guide-Update20181207.pdf), a simplified breakout board with few jumper wires are enough to test this library out. <br>
<br>
# Folder structure : #
<pre>
\MemoryLCD
	\picts
	\examples
		\BloodPressure_GUI
		\Energy
		\FirstPixel
		\HelloWorld
		\HelloWorld2
	\src
	library.properties
	README.md (this file)
</pre>
Install this library to `/arduino libraries` folder. In Arduino IDE from File->Examples->Custom Libraries you will see 5 examples. We have tested 5 Memory LCD models up to time of writing:<br>
- LS027B7DH01 (2.7")<br>
- LS032B7DD02 (3.2")<br>
- LS044Q7DH01(4.4")<br>
- LS006B7DH03 (0.56")<br>
- LS011B7DH03 (1.08")<br>
Different LCD sizes with the same FPC interface simplifies hardware design.<br>
<br>
Selection options for which LCD model to use is available in `MemoryLCD.h`. Listing below shows an example with 2.7" model to use by leaving only `#define LS027B7DH01` while other models has been comment out. 
<pre>
#define   LS027B7DH01
//#define	LS032B7DD02
//#define 	LS044Q7DH01
//#define 	LS006B7DH03
//#define 	LS011B7DH03
</pre>

With this breakout board there are only few jumper cables required to finish the setup. Photos of ESP32 PICO Kit and Arduino M0 PRO as examples:<br>
<br>

----------

<br>

----------

Memory LCD is driven with two data update modes: 1-line mode and multiple-lines mode. There is no single pixel write! To get around this problem a frame buffer is declared to store all pixels in a 2D array:
`uint8_t frameBuffer[GFX_FB_CANVAS_H][GFX_FB_CANVAS_W]`<br>
Each byte in the second subscript `frameBuffer[0][x]` represents 8 pixels in the horizontal direction. On the first horizontal line, pixels 0-7 are represented by `frameBuffer[0][0]`, pixels 8-15 by `frameBuffer[0][1]` and so forth. Bitwise operation is used to fill up this frame buffer in SRAM of the MCU. After the required pixels have been updated in SRAM, the LCD is refreshed for a complete horizontal line with consecutive SPI transfers.<br>

----------
To illustrate this idea better we have captured the pixels on a 4.4" Memory LCD with a macro lens as below. The red rectangle is a label for the first 8 pixels represented by the byte element at `framebuffer[0][0]`. <br>
<br>
Now suppose we need to set the odd pixels to black color for positions 1,3,5,7 we may call the API function `GFXDisplayPutPixel(x,y,color)` with code snippet:<br>
<pre>
for (int x=0; x<8; x++)
{
	if(x%2)
		GFXDisplayPutPixel(x,0,WHITE);
	else
		GFXDisplayPutPixel(x,0,BLACK);
}
</pre>
What's happening in the for-loop is that, every time GFXDisplayPutPixel() is called for example GFXDisplayPutPixel(0,0,BLACK), it is the pixel position at (0,0) set BLACK with `framebuffer[0][0]=0b1111 1111 -> framebuffer[0][0]=0b0111 1111`. A pixel is set white with bit set `1` & clear to `0` to set black. After bitwise is finished with `GFXDisplayPutPixel_FB()`the line will be updated by the local function `GFXDisplayUpdateLine()`. Interested readers may take a look at the source code for GFXDisplayPutPixel() here:<br>
<pre>
void GFXDisplayPutPixel(uint16_t x, uint16_t y, COLOR color)
{
	GFXDisplayPutPixel_FB(x, y, color);	//where bitwise operation in framebuffer occurs
	GFXDisplayUpdateLine(y+1, (uint8_t *)&frameBuffer[y]);	//update the line with SPI write
}
</pre>
After running the for-loop above the LCD displays something this:
<br>

----------

To extend this concept to 2D, we may partially update a rectangular area with GFXDisplayUpdateBlock() to keep the content at the right unchanged while updating the area at the left. Graphical interface illustrated in the Arduino Sketch BloodPressure_GU.ino shows a counting blood pressure reading at the left with a stood still icon of an up-arrow at the right. Feel free to open this sketch and change the delay constant in loop() from delay(50) to delay(1), or removing it to get an impression on how fast it can go. Another unique features of Memory LCD is partial update as long as it spans a horizontal region. Given the blood pressure reading GUI below this means only the area occupying the font height of the SYS. pressure is changed while the top and bottom regions unchanged when it is the systolic pressure counting.
<br>
This leads to a faster frame rate even with a slow SPI transfer rate of 2MHz. 

# **YouTube** video : [https://youtu.be/DUMHNQGVNnY](https://youtu.be/DUMHNQGVNnY) #

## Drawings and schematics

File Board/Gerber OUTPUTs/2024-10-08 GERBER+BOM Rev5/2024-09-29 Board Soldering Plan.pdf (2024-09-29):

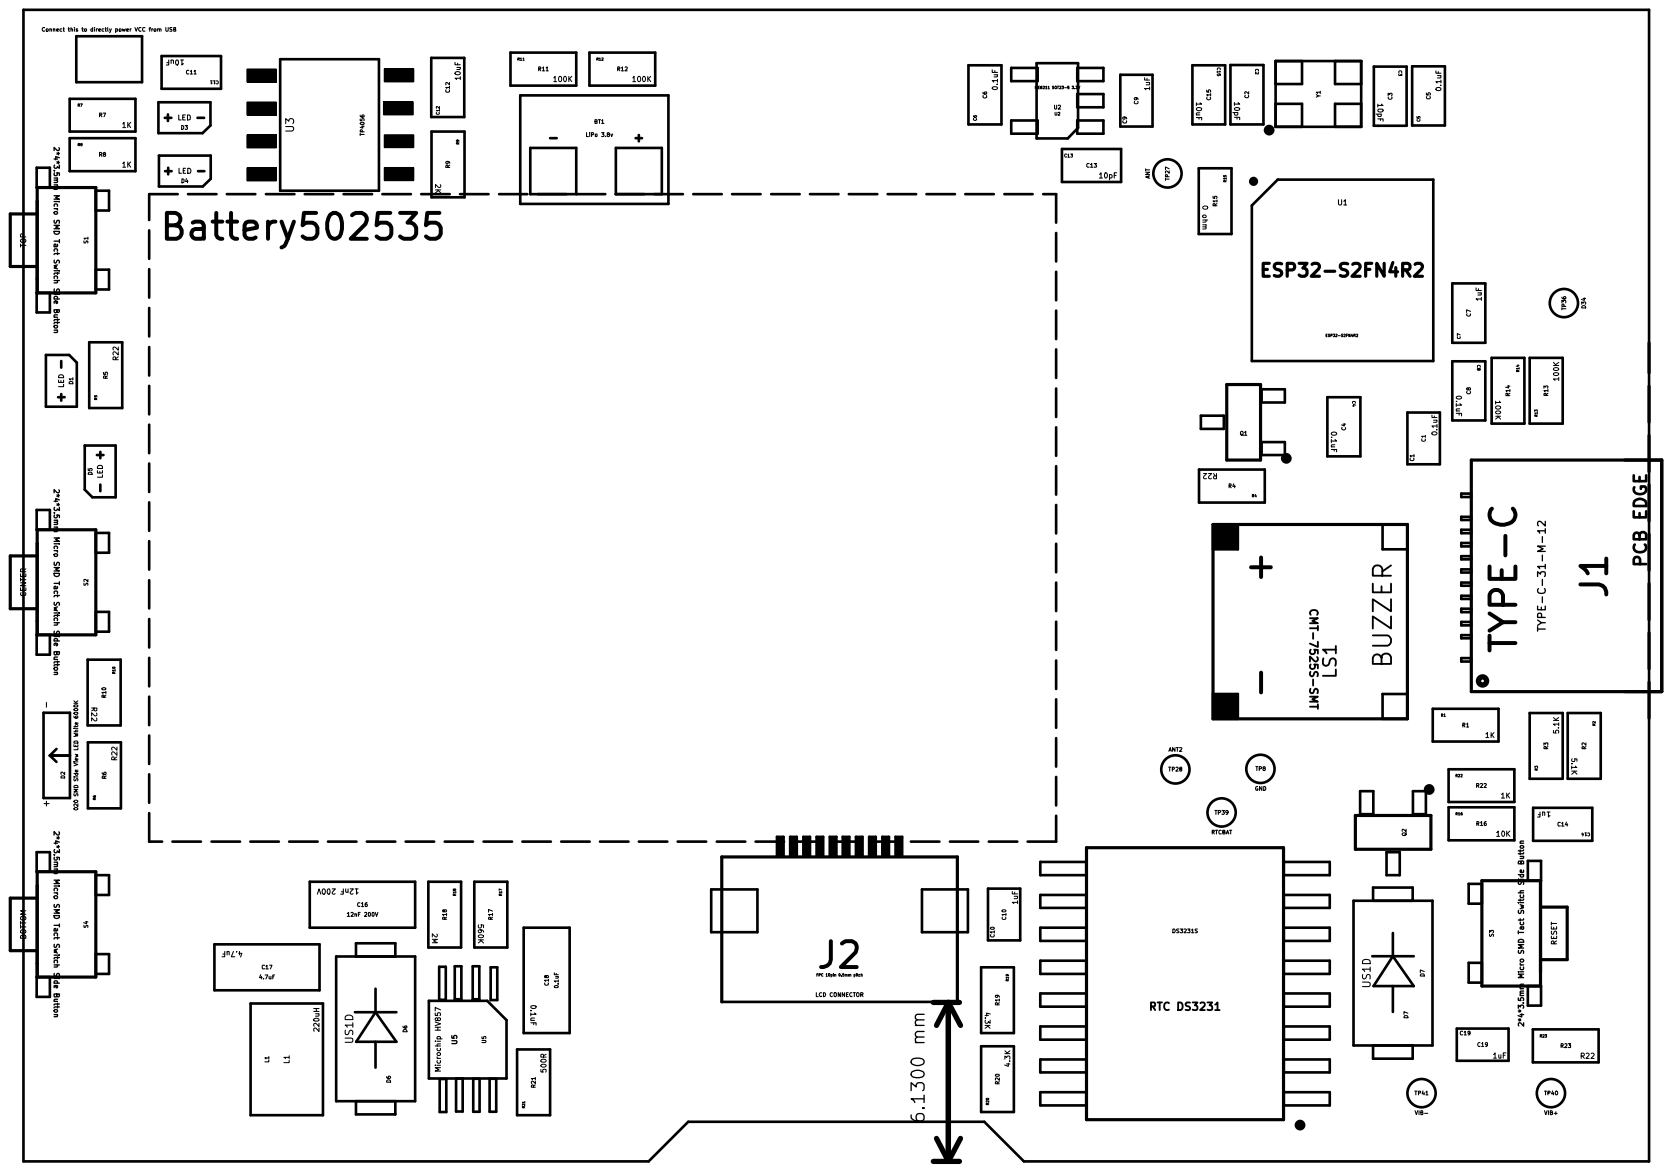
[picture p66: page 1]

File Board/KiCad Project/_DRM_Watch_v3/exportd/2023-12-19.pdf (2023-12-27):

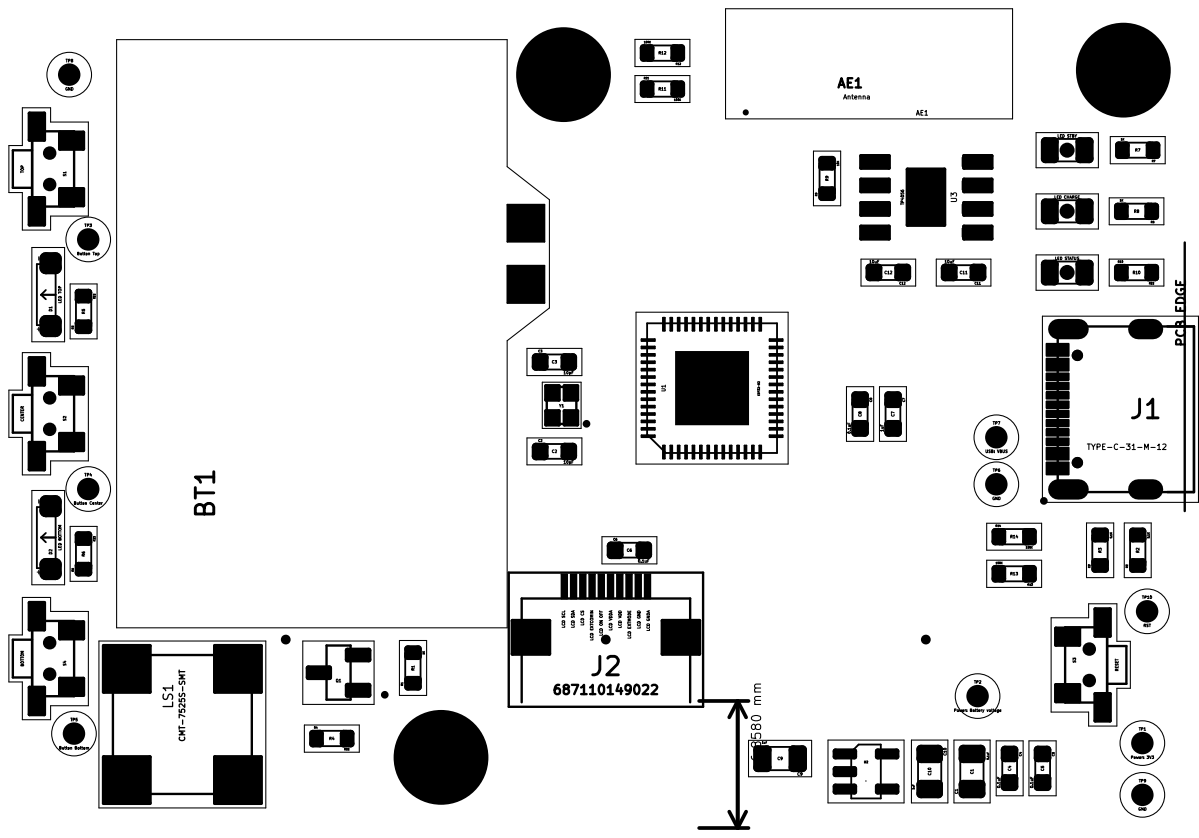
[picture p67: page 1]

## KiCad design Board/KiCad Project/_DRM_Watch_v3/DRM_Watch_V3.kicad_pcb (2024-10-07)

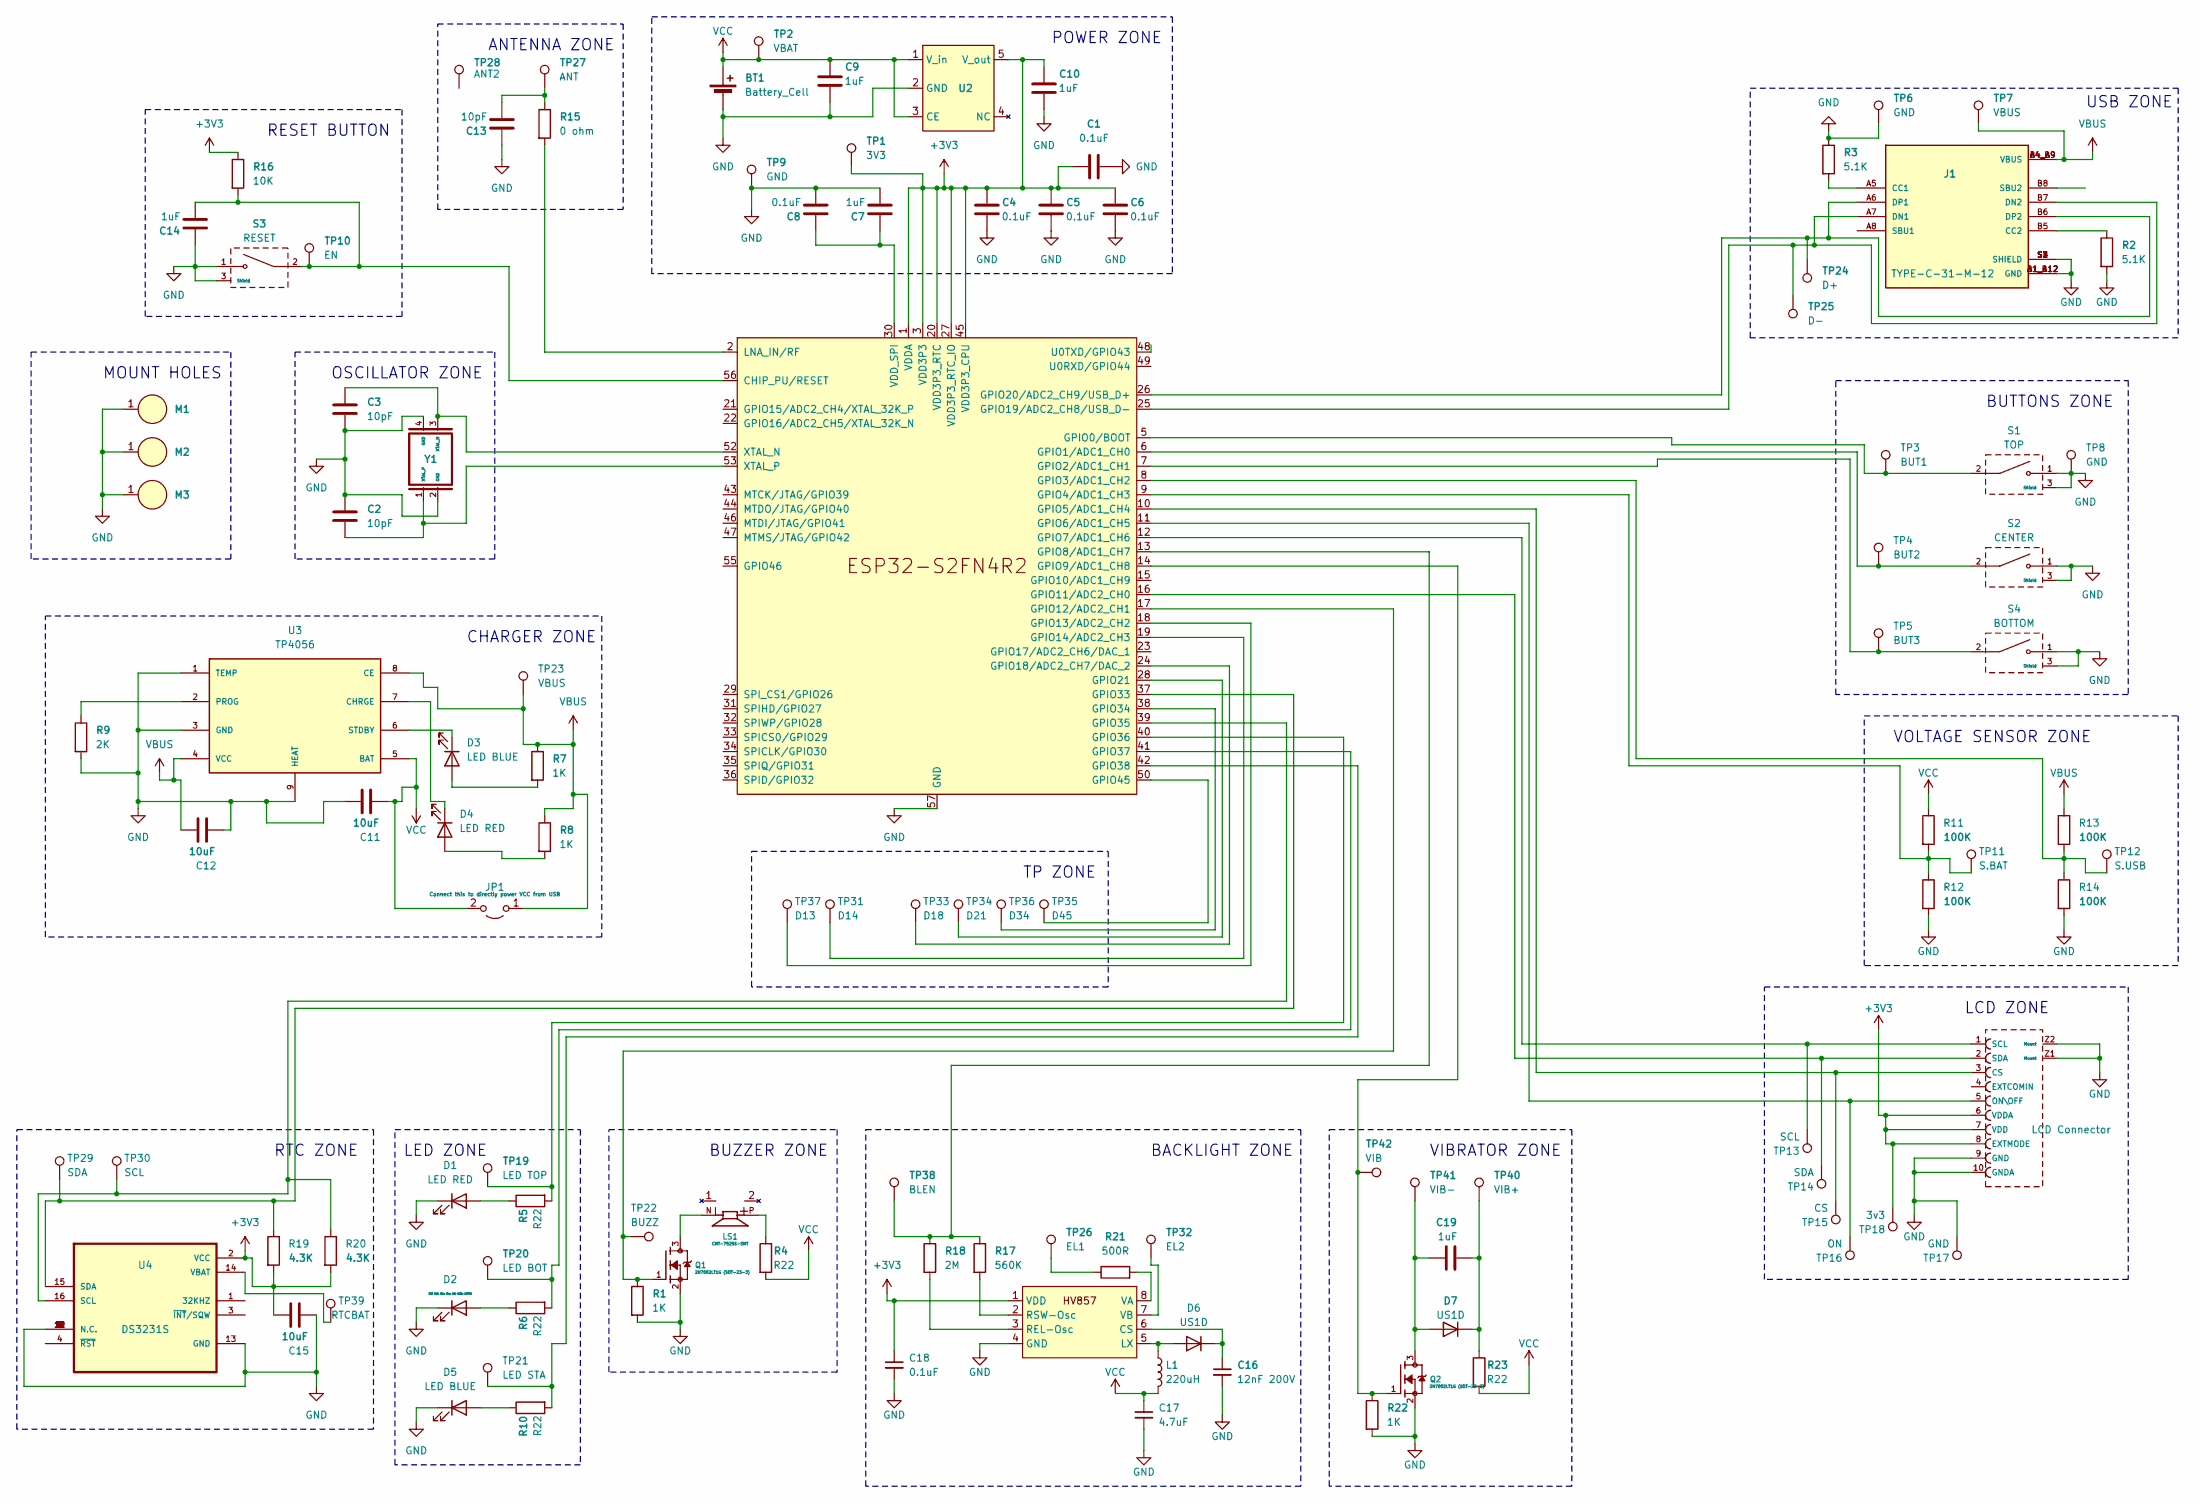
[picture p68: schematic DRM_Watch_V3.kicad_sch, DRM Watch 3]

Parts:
BT1: Battery_Cell; Battery
C1: 0.1uF; C_0805_2012Metric
C2, C3, C13: 10pF; C_0603_1608Metric
C4, C5, C6, C8: 0.1uF; C_0603_1608Metric
C7, C14: 1uF; C_0603_1608Metric
C9, C10, C19: 1uF; C_0805_2012Metric
C11, C12, C15: 10uF; C_0603_1608Metric
C16: 12nF 200V; C_1206
C17: 4.7uF; C_1206
C18: 0.1uF; C_1206
D1, D4: LED RED; HOLE_LED_0805_2012Metric
D2: 020 SMD Side View LED White 6000K; SMD-LED-Side-View
D3, D5: LED BLUE; HOLE_LED_0805_2012Metric
D6, D7: US1D
J1: TYPE-C-31-M-12; HRO_TYPE-C-31-M-12
J2: FPC 10pin 0.5mm pitch; 687110149022
JP1: Connect this to directly power VCC from USB; SolderJumper-2_P1.3mm_Open_Pad1.0x1.5mm
L1: 220uH; Inductor-L_1210_3225Metric
LS1: CMT-7525S-SMT; CUI_CMT-7525S-SMT
M1, M2, M3: Brass SMTSO-M1.4X3X1.5-2X0.8; m1.4-screw-mount
Q1, Q2: 2N7002LT1G (SOT-23-3); SOT95P240X111-3N
R1, R7, R8, R22: 1K; R_0603_1608Metric
R2, R3: 5.1K; R_0603_1608Metric
R4, R5, R6, R10, R23: R22; R_0603_1608Metric
R9: 2K; R_0603_1608Metric
R11, R12, R13, R14: 100K; R_0603_1608Metric
R15: 0 ohm; R_0603_1608Metric
R16: 10K; R_0603_1608Metric
R17: 560K; R_0603_1608Metric
R18: 2M; R_0603_1608Metric
R19, R20: 4.3K; R_0603_1608Metric
R21: 500R; R_0603_1608Metric
S1, S2, S3, S4: 2*4*3.5mm Micro SMD Tact Switch Side Button; SW_TL3330AF130QG
TP1: 3V3; TestPoint_Pad
TP2: VBAT; TestPoint_Pad
TP3: BUT1; TestPoint_Pad
TP4: BUT2; TestPoint_Pad
TP5: BUT3; TestPoint_Pad
TP6, TP8, TP9, TP17: GND; TestPoint_Pad
TP7, TP23: VBUS; TestPoint_Pad
TP10: EN; TestPoint_Pad
TP11: S.BAT; TestPoint_Pad
TP12: S.USB; TestPoint_Pad
TP13, TP30: SCL; TestPoint_Pad
TP14, TP29: SDA; TestPoint_Pad
TP15: CS; TestPoint_Pad
TP16: ON; TestPoint_Pad
TP18: 3v3; TestPoint_Pad
TP19: LED TOP; TestPoint_Pad
TP20: LED BOT; TestPoint_Pad
TP21: LED STA; TestPoint_Pad
TP22: BUZZ; TestPoint_Pad
TP24: D+; TestPoint_Pad
TP25: D-; TestPoint_Pad
TP26: EL1; TestPoint_Pad
TP27: ANT; TestPoint_Pad
TP28: ANT2; TestPoint_Pad
TP31: D14; TestPoint_Pad
TP32: EL2; TestPoint_Pad
TP33: D18; TestPoint_Pad
TP34: D21; TestPoint_Pad
TP35: D45; TestPoint_Pad
TP36: D34; TestPoint_Pad
TP37: D13; TestPoint_Pad
TP38: BLEN; TestPoint_Pad
TP39: RTCBAT; TestPoint_Pad
TP40: VIB+; TestPoint_Pad
TP41: VIB-; TestPoint_Pad
TP42: VIB; TestPoint_Pad
U1: ESP32-S2FN4R2; QFN-56-1EP_7x7mm_P0.4mm_EP4x4mm_ThermalVias
U2: ME6211 SOT23-5 3.3V; ME6211 SOT-23-5
U3: TP4056; SO08
U4: DS3231S; SOIC127P1032X265-16N
U5: Microchip HV857; HV857
Y1: 3225 4PIN 40Mhz 3.2*2.5mm Passive SMD Quartz Reso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; Oscilator

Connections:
+3V3: C1.2, C4.1, C5.1, C6.1, C10.1, C15.2, C18.1, J2.6 (VDDA), J2.7 (VDD), J2.8 (EXTMODE), R16.1, R19.2, R20.2, TP1.1, TP18.1, U1.1 (VDDA), U1.3 (VDD3P3), U1.4 (VDD3P3), U1.20 (VDD3P3_RTC), U1.27 (VDD3P3_RTC_IO), U1.45 (VDD3P3_CPU), U1.51 (VDDA), U1.54 (VDDA), U2.5 (V_out), U4.2 (VCC), U5.1 (VDD)
GND: BT1.2 (-), C1.1, C2.1, C3.2, C4.2, C5.2, C6.2, C7.2, C8.2, C9.2, C10.2, C11.2, C12.1, C13.1, C14.1, C15.1, C16.2, C17.2, C18.2, D1.1 (K), D2.1 (K), D5.1 (K), J1.A1_B12 (GND), J1.B1_A12 (GND), J1.S1 (SHIELD), J1.S2 (SHIELD), J1.S3 (SHIELD), J1.S4 (SHIELD), J2.9 (GND), J2.10 (GNDA), J2.Z1 (Mount), J2.Z2 (Mount), M1.1, M2.1, M3.1, Q1.2, Q2.2, R1.2, R2.2, R3.1, R9.2, R12.2, R14.2, R22.2, S1.1, S1.3 (Shield), S2.1, S2.3 (Shield), S3.1, S3.3 (Shield), S4.1, S4.3 (Shield), TP6.1, TP8.1, TP9.1, TP17.1, U1.57 (GND), U2.2 (GND), U3.1 (TEMP), U3.3 (GND), U3.9 (HEAT), U4.5 (N.C.), U4.6 (N.C.), U4.7 (N.C.), U4.8 (N.C.), U4.9 (N.C.), U4.10 (N.C.), U4.11 (N.C.), U4.12 (N.C.), U4.13 (GND), U5.4 (GND), Y1.2 (GND), Y1.4 (GND)
unnamed: C13.2, R15.1, TP27.1
unnamed: D1.2 (A), R5.1
unnamed: D2.2 (A), R6.1
unnamed: D3.2 (A), R7.2
unnamed: D3.1 (K), U3.6 (STDBY)
unnamed: D4.2 (A), R8.2
unnamed: D4.1 (K), U3.7 (CHRGE)
unnamed: D5.2 (A), R10.1
unnamed: D6.2 (A), L1.1, U5.5 (LX)
unnamed: C16.1, D6.1 (K), U5.6 (CS)
unnamed: C19.1, D7.2 (A), Q2.3, TP41.1
unnamed: C19.2, D7.1 (K), R23.1, TP40.1
unnamed: J1.A5 (CC1), R3.2
unnamed: J1.B5 (CC2), R2.1
unnamed: J1.A7 (DN1), J1.B7 (DN2), TP25.1, U1.25 (GPIO19/ADC2_CH8/USB_D-)
unnamed: J1.A6 (DP1), J1.B6 (DP2), TP24.1, U1.26 (GPIO20/ADC2_CH9/USB_D+)
unnamed: J2.3 (CS), TP15.1, U1.10 (GPIO5/ADC1_CH4)
unnamed: J2.5 (ON\OFF), TP16.1, U1.11 (GPIO6/ADC1_CH5)
unnamed: J2.1 (SCL), TP13.1, U1.12 (GPIO7/ADC1_CH6)
unnamed: J2.2 (SDA), TP14.1, U1.16 (GPIO11/ADC2_CH0)
unnamed: LS1.N, Q1.3
unnamed: LS1.P, R4.1
unnamed: R21.1, TP26.1
unnamed: C14.2, R16.2, S3.2, TP10.1, U1.56 (CHIP_PU/RESET)
unnamed: S1.2, TP3.1, U1.5 (GPIO0/BOOT)
unnamed: S2.2, TP4.1, U1.6 (GPIO1/ADC1_CH0)
unnamed: S4.2, TP5.1, U1.7 (GPIO2/ADC1_CH1)
unnamed: R13.2, R14.1, TP12.1, U1.8 (GPIO3/ADC1_CH2)
unnamed: R11.2, R12.1, TP11.1, U1.9 (GPIO4/ADC1_CH3)
unnamed: R17.1, R18.1, TP38.1, U1.13 (GPIO8/ADC1_CH7)
unnamed: Q2.1, R22.1, TP42.1, U1.14 (GPIO9/ADC1_CH8)
unnamed: Q1.1, R1.1, TP22.1, U1.17 (GPIO12/ADC2_CH1)
unnamed: TP37.1, U1.18 (GPIO13/ADC2_CH2)
unnamed: TP31.1, U1.19 (GPIO14/ADC2_CH3)
unnamed: TP33.1, U1.24 (GPIO18/ADC2_CH7/DAC_2)
unnamed: TP34.1, U1.28 (GPIO21)
unnamed: R19.1, TP29.1, U1.37 (GPIO33), U4.15 (SDA)
unnamed: TP36.1, U1.38 (GPIO34)
unnamed: R20.1, TP30.1, U1.39 (GPIO35), U4.16 (SCL)
unnamed: R5.2, TP19.1, U1.40 (GPIO36)
unnamed: R6.2, TP20.1, U1.41 (GPIO37)
unnamed: R10.2, TP21.1, U1.42 (GPIO38)
unnamed: TP35.1, U1.50 (GPIO45)
unnamed: R15.2, U1.2 (LNA_IN/RF)
unnamed: C7.1, C8.1, U1.30 (VDD_SPI)
unnamed: C3.1, U1.52 (XTAL_N), Y1.3 (XTAL_N)
unnamed: C2.2, U1.53 (XTAL_P), Y1.1 (XTAL_P)
unnamed: R9.1, U3.2 (PROG)
unnamed: TP39.1, U4.14 (VBAT)
unnamed: R18.2, U5.3 (REL-Osc)
unnamed: R17.2, U5.2 (RSW-Osc)
unnamed: R21.2, U5.8 (VA)
unnamed: TP32.1, U5.7 (VB)
VBUS: C12.2, J1.A4_B9 (VBUS), J1.B4_A9 (VBUS), JP1.1 (A), R7.1, R8.1, R13.1, TP7.1, TP23.1, U3.4 (VCC), U3.8 (CE)
VCC: BT1.1 (+), C9.1, C11.1, C17.1, JP1.2 (B), L1.2, R4.2, R11.1, R23.2, TP2.1, U2.1 (V_in), U2.3 (CE), U3.5 (BAT)

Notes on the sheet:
MOUNT HOLES
OSCILLATOR ZONE
BUZZER ZONE
CHARGER ZONE
TP ZONE
LED ZONE
RESET BUTTON
BUTTONS ZONE
VOLTAGE SENSOR ZONE
USB ZONE
ANTENNA ZONE
VIBRATOR ZONE
LCD ZONE
POWER ZONE
RTC ZONE
BACKLIGHT ZONE

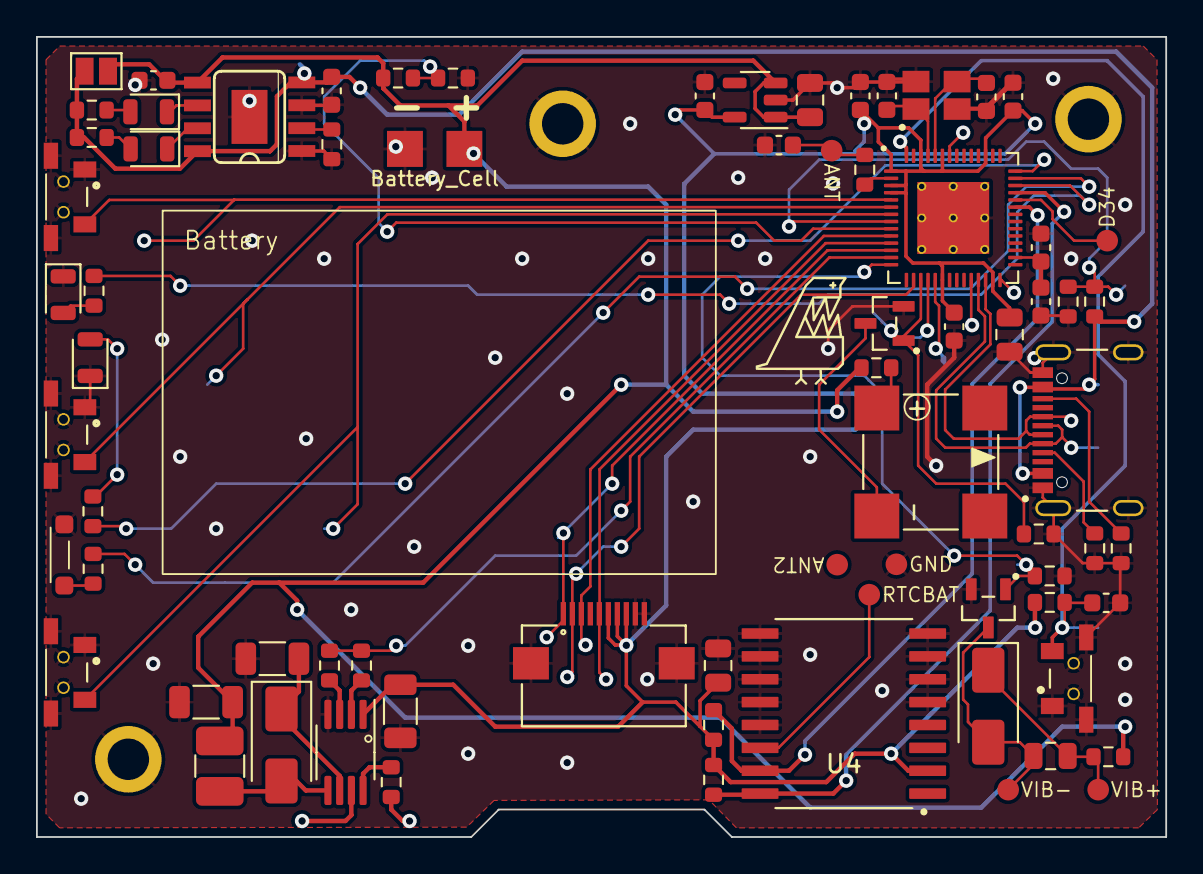
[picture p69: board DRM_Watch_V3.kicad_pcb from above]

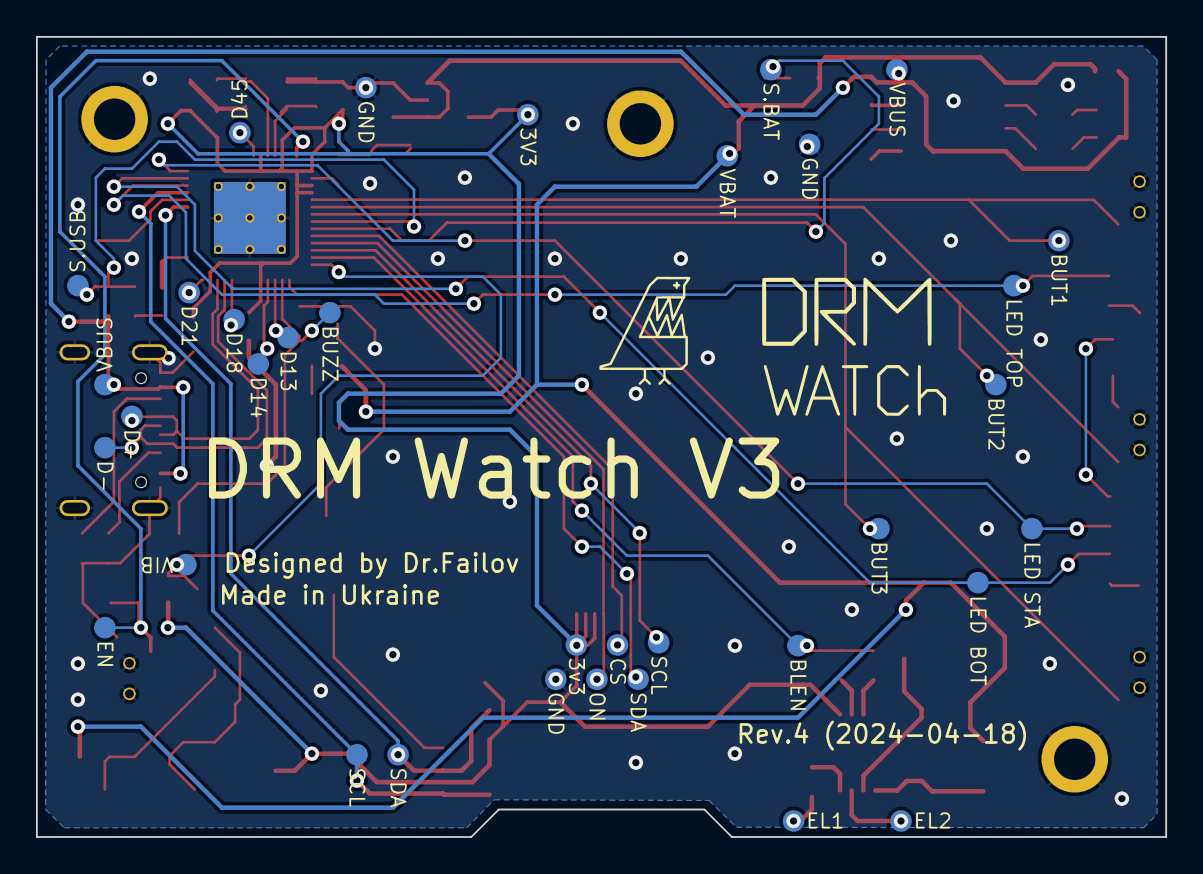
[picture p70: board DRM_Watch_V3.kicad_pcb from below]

Board: 2 copper layers, 62.7 x 44.4 mm, 112 parts (35 on the bottom side), 57 nets.

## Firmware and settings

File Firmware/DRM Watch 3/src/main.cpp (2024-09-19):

/*
 *  Project     DRM Watch 3
 *  @author     Dr.  Failov
 *  @link       https://github.com/drfailov/DRM_Watch_v3
 *  @license    GNU GENERAL PUBLIC LICENSE
 *
 *  
 */


#include "Global.h"
#include "DrmPreferences.h"
#include "Battery.h"
#include "Buzzer.h"
#include "RTC.h"
#include "Led.h"
#include "Lcd.h"
#include "TimeSync.h"
#include "Backlight.h"
#include "Button.h"
#include "ModeTest.h"
#include "ModeAlertSettings.h"
#include "ModeTimer.h"
#include "ModeWatchface.h"
#include "SerialCommands.h"

#include <Arduino.h>

#include <ESP32Time.h>
#ifdef U8X8_HAVE_HW_SPI
#include <SPI.h>
#endif
#ifdef U8X8_HAVE_HW_I2C
#include <Wire.h>
#endif


void setup(void) {
  if(esp_sleep_get_wakeup_cause() != ESP_SLEEP_WAKEUP_TIMER && !isOff())/*NOT periodical wakeup*/
    Serial.begin(115200);   
  initPreferences();
  black = getBlackValue(); //load from memory
  white = getWhiteValue(); //load from memory
  if(!isOff() && isBatteryCritical()){  //if deelpy discharged - go to sleep to let it charge
    setModeOff();
    return;
  }
  buzzerInit();
  if(esp_sleep_get_wakeup_cause() == ESP_SLEEP_WAKEUP_EXT0/*By button*/) buttonBeep();
  lcdInit();
  backlightInit();
  initButtons();
  initLed();
  if(esp_sleep_get_wakeup_cause() == 0 && !isOff()) drawMessageAnimated(L("Ініціалізація RTC...", "Init RTC..."));
  initRtc();
  initTime();

  if(esp_sleep_get_wakeup_cause() == 0){  //normal wakeup with animation and sound
    if(isButtonDownPressed()){
      setModeTest();
      return;
    }
    lcd()->setColorIndex(white);
    lcd()->drawBox(0, 0, 400, 240);
    lcd()->setFont(u8g2_font_10x20_t_cyrillic);  //ok
    lcd()->setColorIndex(black);
    lcd()->setCursor(316, 234); 
    lcd()->print(version);
    int x=130;
    displayDrawVector(getPathZubat(), x, 60, 3.0, 3, 0, black);
    lcd()->sendBuffer();
    if(!isBatteryCritical()){
      ledSelftest();
      playInit();
    }
    while(x>40){
      displayDrawVector(getPathZubat(), x, 60, 3.0, 3, 0, white);
      x-=15;
      displayDrawVector(getPathZubat(), x, 60, 3.0, 3, 0, black);
      lcd()->sendBuffer();
    }
    displayDrawVector(getPathDrmWatch(), 190, 60, 3.0, 2, 3, black);
    lcd()->setCursor(340, 164); lcd()->setFont(u8g2_font_logisoso38_tn);  lcd()->print("3");
    lcd()->sendBuffer();
    delay(300);
    firstDraw = true;
    setModeWatchface();
  }
  else{   //wakeup only to draw next frame
    modeSetup();
  }
}

void loop(void) {
  buttonsLoop();
  backlightLoop();
  alertLoop();
  timerLoop();
  serialLoop();

  isBatteryLow();   //TEST!!! 

  if(modeLoop != 0){
     //unsigned long millisStarted = millis();  //routine needed to measure performance
    modeLoop();    //125ms 1MHz SPI  |   63ms  3MHz SPI
    firstDraw = false;
    // unsigned long millisEnd = millis();
    // Serial.print("Loop: "); Serial.print(millisEnd-millisStarted); Serial.println("ms.");
  }
  autoSleepLoop();
}













//----------------------//----------------------//----------------------//----------------------//----------------------//----------------------//----------------------

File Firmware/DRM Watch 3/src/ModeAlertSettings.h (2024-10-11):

#ifndef MODEALERTSETTINGS_H
#define MODEALERTSETTINGS_H

bool disableAlertsTemporarily = false;
void ModeAlertSettingsMenuLoop();
void ModeAlertSettingsMenuButtonUp();
void ModeAlertSettingsMenuButtonCenter();
void ModeAlertSettingsMenuButtonDown();
void resetAlertMetadata(int index);
void setModeAlertSettingsMenu(int alertIndex);
void setModeAlertSettingsMenu();
void ModeAlertSettingsMenuNameSelected();
void ModeAlertSettingsMenuMelodySelected();
void alertLoop();

#include "Lcd.h"
#include "Global.h"
#include "AutoSleep.h"
#include "ModeTimer.h"
#include "Button.h"
#include "GlobalMenu.h"
#include "ModeAlertsList.h"
#include "ModeKeyboard.h"
#include "MelodyPlayer.h"
#include "DrmPreferences.h"

int modeAlertSettingsIndex = 0;
int modeAlertSettingsHourValue = 0;
int modeAlertSettingsMinuteValue = 0;
int modeAlertSettingsMelodyValue = 0;
bool modeAlertSettingsEditMode = false;

const int itemModeAlertSettingsBack = 0;
const int itemModeAlertSettingsEnabled = 1;
const int itemModeAlertSettingsHour = 2;
const int itemModeAlertSettingsMinute = 3;
const int itemModeAlertSettingsMelody = 4;
const int itemModeAlertSettingsName = 5;

void setModeAlertSettingsMenu(int alertIndex)
{
  if(modeExit != 0)
    modeExit();
  clearScreenAnimation();
  Serial.println(F("Set mode: Alert settings Menu"));
  modeSetup = setModeAlertSettingsMenu;
  modeLoop = ModeAlertSettingsMenuLoop;
  modeButtonUp = ModeAlertSettingsMenuButtonUp;
  modeButtonCenter = ModeAlertSettingsMenuButtonCenter;
  modeButtonDown = ModeAlertSettingsMenuButtonDown;
  modeButtonUpLong = 0;
  modeButtonCenterLong = 0;
  modeButtonDownLong = 0;
  registerAction();
  enableAutoReturn = true;
  enableAutoSleep = false;
  autoReturnTime = autoReturnDefaultTime;
  autoSleepTime = autoSleepDefaultTime;
  selected = 0;
  items = 6;
  modeAlertSettingsIndex = alertIndex;
  modeAlertSettingsHourValue = getAlertHour(modeAlertSettingsIndex);
  modeAlertSettingsMinuteValue = getAlertMinute(modeAlertSettingsIndex);
  modeAlertSettingsMelodyValue = getAlertMelody(modeAlertSettingsIndex);
}

void setModeAlertSettingsMenu()
{
  setModeAlertSettingsMenu(modeAlertSettingsIndex);
}

void ModeAlertSettingsMenuLoop()
{
  if (modeAlertSettingsHourValue < 0)
    modeAlertSettingsHourValue = 23;
  if (modeAlertSettingsHourValue > 23)
    modeAlertSettingsHourValue = 0;
  if (modeAlertSettingsMinuteValue < 0)
    modeAlertSettingsMinuteValue = 59;
  if (modeAlertSettingsMinuteValue > 59)
    modeAlertSettingsMinuteValue = 0;
  if (modeAlertSettingsMelodyValue < 0)
    modeAlertSettingsMelodyValue = getMelodyCount() - 1;
  if (modeAlertSettingsMelodyValue > getMelodyCount() - 1)
    modeAlertSettingsMelodyValue = 0;

  lcd()->setColorIndex(white);
  lcd()->drawBox(0, 0, 400, 240);

  lcd()->setFont(u8g2_font_10x20_t_cyrillic); // ok
  lcd()->setColorIndex(black);
  lcd()->setCursor(5, 18);
  lcd()->print(L("Будильник ", "Alert "));
  lcd()->print(modeAlertSettingsIndex);

  drawStatusbar(363, 1, true);
  drawMenuLegend();
  if (modeAlertSettingsEditMode)
  {
    draw_ic16_plus(lx(), ly1(), black);
    draw_ic16_minus(lx(), ly3(), black);
  }

  drawMenuItem(itemModeAlertSettingsBack, draw_ic24_back, L("Назад", "Back"), firstDraw, 10, 26);
  lcd()->setFont(u8g2_font_10x20_t_cyrillic); // ok
  lcd()->setColorIndex(black);
  drawCentered(L("Активний", "Active"), 230, 57);
  if (getAlertEnabled(modeAlertSettingsIndex))
    drawMenuItem(itemModeAlertSettingsEnabled, draw_ic24_check2, L("Вимкнути", "Disable"), firstDraw, 277, 26); // draw_ic24_cancel   draw_ic24_check2
  else
    drawMenuItem(itemModeAlertSettingsEnabled, draw_ic24_cancel, L("Увімкнути", "Enable"), firstDraw, 277, 26); // draw_ic24_cancel   draw_ic24_check2

  lcd()->setFont(u8g2_font_10x20_t_cyrillic); // ok
  lcd()->setColorIndex(black);
  drawCentered(L("Час", "Time"), 45, 108);
  drawNumberFrame(/*index*/ itemModeAlertSettingsHour, /*number*/ modeAlertSettingsHourValue, /*name*/ L("Обрати годину", "Select hour"), /*editMode*/ modeAlertSettingsEditMode, /*animate*/ firstDraw, /*x*/ 88, /*y*/ 81, /*Width*/ 82);
  lcd()->setFont(u8g2_font_inr24_t_cyrillic); // ok
  lcd()->setColorIndex(black);
  lcd()->setCursor(172, 111);
  lcd()->print(":");
  drawNumberFrame(/*index*/ itemModeAlertSettingsMinute, /*number*/ modeAlertSettingsMinuteValue, /*name*/ L("Обрати хвилину", "Select minute"), /*editMode*/ modeAlertSettingsEditMode, /*animate*/ firstDraw, /*x*/ 193, /*y*/ 81, /*Width*/ 82);

  lcd()->setFont(u8g2_font_10x20_t_cyrillic); // ok
  lcd()->setColorIndex(black);
  drawCentered(L("Мелодія", "Melody"), 45, 154);
  drawTextFrame(/*index*/ itemModeAlertSettingsMelody, /*text*/ getMelodyName(modeAlertSettingsMelodyValue).c_str(), /*name*/ L("Обрати мелодію", "Select melody"), /*editMode*/ modeAlertSettingsEditMode, /*animate*/ firstDraw, /*x*/ 88, /*y*/ 127, /*width*/ 265);
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

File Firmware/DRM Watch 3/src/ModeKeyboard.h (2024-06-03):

#ifndef MODEKEYBOARD_H
#define MODEKEYBOARD_H

/*PROTOTYPES*/
void addLetter();
void backspace();
void shift();
void modeKeyboardCancel();
void modeKeyboardDone();
int cntKeys();
void setModeKeyboard(String title, Runnable onDone, Runnable onCancel);
void setModeKeyboard();
void modeKeyboardLoop();
void modeKeyboardButtonUp();
void modeKeyboardButtonCenter();
void modeKeyboardButtonDown();
int drawKey(int index, int startX);


#include "Global.h"
#include "AutoSleep.h"
#include "Button.h"


struct Key {
    int row;
    int col;
    int width = 0;
    char letter;
    char letterCaps;
    char letterSym;
    Drawable drawIcon;
    Drawable drawIconCaps;
    Drawable drawIconSym;
    Runnable onClick;

    Key(int _row, int _col, int _width, char _letter, char _letterCaps, char _letterSym, Drawable _drawIcon, Drawable _drawIconCaps, Drawable _drawIconSym, Runnable _onClick): 
    row(_row), col(_col), width(_width), letter(_letter), letterCaps(_letterCaps), letterSym(_letterSym), drawIcon(_drawIcon), drawIconCaps(_drawIconCaps), drawIconSym(_drawIconSym), onClick(_onClick) {}
  };

const int KEYBOARD_MODE_NORMAL = 0;
const int KEYBOARD_MODE_CAPS = 1;
const int KEYBOARD_MODE_SYM = 2;

String keyboardTitle = "";
Runnable keyboardDone = 0;
Runnable keyboardCancel = 0;
int keyboardMode = KEYBOARD_MODE_NORMAL;
String text = "";
int selectedRow = 0;
int selectedCol = 0;
int keyDefaultWidth = 30;

Key keys[] = {
  {/*row*/0, /*col*/0, /*width*/keyDefaultWidth, /*letter*/'1', /*letterCaps*/'1', /*letterSym*/'!', /*drawable*/0, /*drawableCaps*/0, /*drawableSym*/0, /*onClick*/addLetter},
  {/*row*/0, /*col*/1, /*width*/keyDefaultWidth, /*letter*/'2', /*letterCaps*/'2', /*letterSym*/'@', /*drawable*/0, /*drawableCaps*/0, /*drawableSym*/0, /*onClick*/addLetter},
  {/*row*/0, /*col*/2, /*width*/keyDefaultWidth, /*letter*/'3', /*letterCaps*/'3', /*letterSym*/'#', /*drawable*/0, /*drawableCaps*/0, /*drawableSym*/0, /*onClick*/addLetter},
  {/*row*/0, /*col*/3, /*width*/keyDefaultWidth, /*letter*/'4', /*letterCaps*/'4', /*letterSym*/'$', /*drawable*/0, /*drawableCaps*/0, /*drawableSym*/0, /*onClick*/addLetter},
  {/*row*/0, /*col*/4, /*width*/keyDefaultWidth, /*letter*/'5', /*letterCaps*/'5', /*letterSym*/'%', /*drawable*/0, /*drawableCaps*/0, /*drawableSym*/0, /*onClick*/addLetter},
  {/*row*/0, /*col*/5, /*width*/keyDefaultWidth, /*letter*/'6', /*letterCaps*/'6', /*letterSym*/'^', /*drawable*/0, /*drawableCaps*/0, /*drawableSym*/0, /*onClick*/addLetter},
  {/*row*/0, /*col*/6, /*width*/keyDefaultWidth, /*letter*/'7', /*letterCaps*/'7', /*letterSym*/'&', /*drawable*/0, /*drawableCaps*/0, /*drawableSym*/0, /*onClick*/addLetter},
  {/*row*/0, /*col*/7, /*width*/keyDefaultWidth, /*letter*/'8', /*letterCaps*/'8', /*letterSym*/'*', /*drawable*/0, /*drawableCaps*/0, /*drawableSym*/0, /*onClick*/addLetter},
  {/*row*/0, /*col*/8, /*width*/keyDefaultWidth, /*letter*/'9', /*letterCaps*/'9', /*letterSym*/'(', /*drawable*/0, /*drawableCaps*/0, /*drawableSym*/0, /*onClick*/addLetter},
  {/*row*/0, /*col*/9, /*width*/keyDefaultWidth, /*letter*/'0', /*letterCaps*/'0', /*letterSym*/')', /*drawable*/0, /*drawableCaps*/0, /*drawableSym*/0, /*onClick*/addLetter},

  {/*row*/1, /*col*/0, /*width*/keyDefaultWidth, /*letter*/'q', /*letterCaps*/'Q', /*letterSym*/'%', /*drawable*/0, /*drawableCaps*/0, /*drawableSym*/0, /*onClick*/addLetter},
  {/*row*/1, /*col*/1, /*width*/keyDefaultWidth, /*letter*/'w', /*letterCaps*/'W', /*letterSym*/'\\',/*drawable*/0, /*drawableCaps*/0, /*drawableSym*/0, /*onClick*/addLetter},
  {/*row*/1, /*col*/2, /*width*/keyDefaultWidth, /*letter*/'e', /*letterCaps*/'E', /*letterSym*/'|', /*drawable*/0, /*drawableCaps*/0, /*drawableSym*/0, /*onClick*/addLetter},
  {/*row*/1, /*col*/3, /*width*/keyDefaultWidth, /*letter*/'r', /*letterCaps*/'R', /*letterSym*/'=', /*drawable*/0, /*drawableCaps*/0, /*drawableSym*/0, /*onClick*/addLetter},
  {/*row*/1, /*col*/4, /*width*/keyDefaultWidth, /*letter*/'t', /*letterCaps*/'T', /*letterSym*/'[', /*drawable*/0, /*drawableCaps*/0, /*drawableSym*/0, /*onClick*/addLetter},
  {/*row*/1, /*col*/5, /*width*/keyDefaultWidth, /*letter*/'y', /*letterCaps*/'Y', /*letterSym*/']', /*drawable*/0, /*drawableCaps*/0, /*drawableSym*/0, /*onClick*/addLetter},
  {/*row*/1, /*col*/6, /*width*/keyDefaultWidth, /*letter*/'u', /*letterCaps*/'U', /*letterSym*/'<', /*drawable*/0, /*drawableCaps*/0, /*drawableSym*/0, /*onClick*/addLetter},
  {/*row*/1, /*col*/7, /*width*/keyDefaultWidth, /*letter*/'i', /*letterCaps*/'I', /*letterSym*/'>', /*drawable*/0, /*drawableCaps*/0, /*drawableSym*/0, /*onClick*/addLetter},
  {/*row*/1, /*col*/8, /*width*/keyDefaultWidth, /*letter*/'o', /*letterCaps*/'O', /*letterSym*/'{', /*drawable*/0, /*drawableCaps*/0, /*drawableSym*/0, /*onClick*/addLetter},
  {/*row*/1, /*col*/9, /*width*/keyDefaultWidth, /*letter*/'p', /*letterCaps*/'P', /*letterSym*/'}', /*drawable*/0, /*drawableCaps*/0, /*drawableSym*/0, /*onClick*/addLetter},
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

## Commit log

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2024-01-07 2024-01-07 v0.14 light flashlight slightly when system not in sleep 2024-01-07 v0.14 version info 2024-01-07 v0.14 Init view 2024-01-07 v0.14 about window 2024-01-07 v0.14 Fixed: permament reconnecti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
2024-01-15 2024-01-15 Board: add step-up resistor and cap to RST pin 2024-01-15 Board: quartz bigger package 2024-01-15 Board: add more testpoints for unused pins 2024-01-15 Board: top led: place for smaller le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
    [DRM_Watch_V3-B_Cu.gbr, DRM_Watch_V3-B_Mask.gbr, DRM_Watch_V3-B_Paste.gbr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]
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2024-01-28 2024-01-27 Updated model case 2024-01-28 Updated model case 2024-01-28 Added images to engrave on back and front panel
    [v105back-case.stl, v105buttons.stl, v105case.3mf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]
2024-01-29 2024-01-29 v0.21 fixed case when unsiccessful tyme sync makes time-travel tool 2024-01-29 v0.21 improved work of auto-sleep and auto exit functions 2024-01-29 v0.21 Added counter for auto sleep 2024-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
2024-02-03 2024-02-03 v0.23 Stopwatch fixed 2024-02-03 v0.23 updated init led effect 2024-02-03 v0.23 added value showing time since last charging 2024-02-03 v0.23 replaced back icon 2024-02-03 v0.23 started im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
    [DRM_Watch_V3.kicad_pcb, DRM_Watch_V3.kicad_sch]
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2024-02-14 2024-02-14 v0.27 Added silent mode 2024-02-14 v0.27 fixed: if disconnected from charger, watch immediately go to sleep 2024-02-14 v0.27 add option to enable or disable auto sync (default is off) 2024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
2024-02-21 2024-02-21 v0.32 added slow light change, rewrite all LED class 2024-02-21 v0.32 Calendar legend fixed
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2024-02-26 2024-02-25 Board: Added symbols for HV857 2024-02-26 Board: Added case outline to board project 2024-02-26 Schematic: Added elements for EL Backlight
    2024-02-25 Board: Added symbols for HV857
    2024-02-26 Board: Added case outline to board project
    2024-02-26 Schematic: Added elements for EL Backlight
    [DRM_Watch_V3.kicad_pcb, DRM_Watch_V3.kicad_sch]
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2024-02-29 2024-02-29 move led-charging to edge and make lightpipe for it 2024-02-29 move led-status to edge and make lightpipe for it 2024-02-29 board: Add EL backlight 2024-02-29 Board: move elements to make 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
    2024-02-29 move led-charging to edge and make lightpipe for it
    2024-02-29 move led-status to edge and make lightpipe for it
    2024-02-29 board: Add EL backlight
    2024-02-29 Board: move elements to make compact
    [DRM_Watch_V3.kicad_pcb]
2024-03-02 2024-03-02 Board rev3: add more info to FAB layer to meke it more informative
    [DRM_Watch_V3.kicad_pcb]
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2024-03-13 2024-03-13 v0.37 Fixed animation 2024-03-13 v0.37 Додати анімацію тексту
    2024-03-13 v0.37 Fixed animation
    2024-03-13 v0.37 Додати анімацію тексту
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2024-03-18 2024-03-18 v1.39 Виправлено: Через анімацію циферблат показує неправильний час 2024-03-18 v1.39 Виправлено: відтворення музики починається без анімації 2024-03-18 v1.39 Додано анімацію при відображен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
    2024-03-18 v1.39 Виправлено: Через анімацію циферблат показує неправильний час
    2024-03-18 v1.39 Виправлено: відтворення му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
    [v179front-case.stl]
2024-03-19 2024-03-19 v1.40 Зміна циферблату коректна в обидві сторони 2024-03-19 v1.40 Виведення дати тепер номером місяця і поряд написано назва місяця 2024-03-19 v1.40 Оновлено шрифт на циферблаті "Life"
    [front v179.step]
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2024-04-01 2024-04-01 v2.03 Виправлено баг: Дисплей постійно мигав при оновленнях 2024-04-01 Доповнено документацію
    2024-04-01 v2.03 Виправлено баг: Дисплей постійно мигав при оновленнях
    2024-04-01 Доповнено документацію
    [DRM_Watch_V3.kicad_sch]
2024-04-03 2024-04-02 Доповнено документацію 2024-04-03 Доповнено документацію
    2024-04-02 Доповнено документацію
    2024-04-03 Доповнено документацію
    [DRM_Watch_V3.csv, DRM_Watch_V3.kicad_sch]
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2024-04-16 2024-04-17 Трохи оновлено модель 2024-04-17 Додано файли для гравіювання передньої панелі 2024-04-17 Доповнено схему
    2024-04-17 Трохи оновлено модель
    2024-04-17 Додано файли для гравіювання передньої панелі
    2024-04-17 Доповнено схему
    [2024-04-16 Front Cover Engraving.dwg, 2024-04-16 Front Cover Engraving.dxf, 2024-04-16 board v190.step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]
2024-04-17 2024-04-17 Оновлено модель - ремінець тепер 22мм.
    2024-04-17 Оновлено модель - ремінець тепер 22мм.
    [2024-04-16 Front Cover Engraving With Frame Included.dwg, 2024-04-16 Front Cover Engraving With Frame Included.dxf, 2024-04-17 board v195.step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]
2024-04-17 2024-04-17 Оновлено модель - на центральну кнопку додано насічки щоб було простіще нащупати всліпу
    2024-04-17 Оновлено модель - на центральну кнопку додано насічки щоб було простіще нащупати всліпу
    [2024-04-17 v199 front-case.stl, 2024-04-17 v199 newback.stl, 2024-04-17 v200 front-case.stl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]
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2024-04-18 2024-04-18 Оновлено Production файли для v200 (22mm)
    2024-04-18 Оновлено Production файли для v200 (22mm)
    [2024-04-17 v200 front-case-engraving.dwg, 2024-04-17 v200 front-case-engraving.dxf, 2024-04-17 v200 front-case.step]
2024-04-18 2024-04-18 Оновлено схему 2024-04-18 Оновлено Плату 2024-04-18 Оновлено Production файли для плати rev4
    2024-04-18 Оновлено схему
    2024-04-18 Оновлено Плату
    2024-04-18 Оновлено Production файли для плати rev4
    [BOM.xlsx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]
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2024-05-18 2024-05-18 Виправлено: отвір для піна ремінця в задній частині корпусу був неправильного розміру
    2024-05-18 Виправлено: отвір для піна ремінця в задній частині корпусу був неправильного розміру
    [v204newback.stl]
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2024-05-26 2024-05-23 v2.26 Почато перенос проекту на PlatformIO 2024-05-23 v2.26 Трохи наведено лад у файлах проекту
    2024-05-23 v2.26 Почато перенос проекту на PlatformIO
    2024-05-23 v2.26 Трохи наведено лад у файлах проекту
    [2024-01-15 back v184.step, 2024-04-16 Front Cover Engraving With Frame Included.dwg, 2024-04-16 Front Cover Engraving With Frame Included.dxf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]
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2024-06-22 2024-06-22 v2.32 Збільшено кількість точок що додаються на один кадр 2024-06-22 v2.32 Реалізовано: Перед вимкненням по таймеру щоб ліхтар мигав щосекунди 2024-06-22 v2.32 Реалізовано: якщо годинник в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
    2024-06-22 v2.32 Збільшено кількість точок що додаються на один кадр
    2024-06-22 v2.32 Р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
    [DRM_Watch_V3.kicad_pcb, DRM_Watch_V3.kicad_sch]
2024-06-25 2024-06-25 v2.33 Реалізовано: Прибрано зайве з файлу Buzzer 2024-06-25 v2.33 Реалізовано: setting tone of all sounds
    2024-06-25 v2.33 Реалізовано: Прибрано зайве з файлу Buzzer
    2024-06-25 v2.33 Реалізовано: setting tone of all sounds
    [DrmPreferences.h, Global.h]
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
